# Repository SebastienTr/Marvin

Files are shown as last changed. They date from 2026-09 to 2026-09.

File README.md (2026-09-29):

# Marvin

**A small desk companion that sees the room five ways at once, and knows how you are doing.**

Marvin is an open-source robot for your desk. A 360° lidar turns on top of its head, a camera and a face live behind a black glass window, and two mmWave radars (24 GHz and 60 GHz) hide behind the band around its body. It hears you through a microphone and answers through a speaker in its side.

It can **see** (camera, lidar), **feel** (who is in the room, how they move, and your breathing and heart rate when you sit in front of it), **hear** (microphone) and **speak** (speaker, expressive eyes). The heavy thinking runs on your computer, which fuses everything into one live model of the room.

<p align="center">
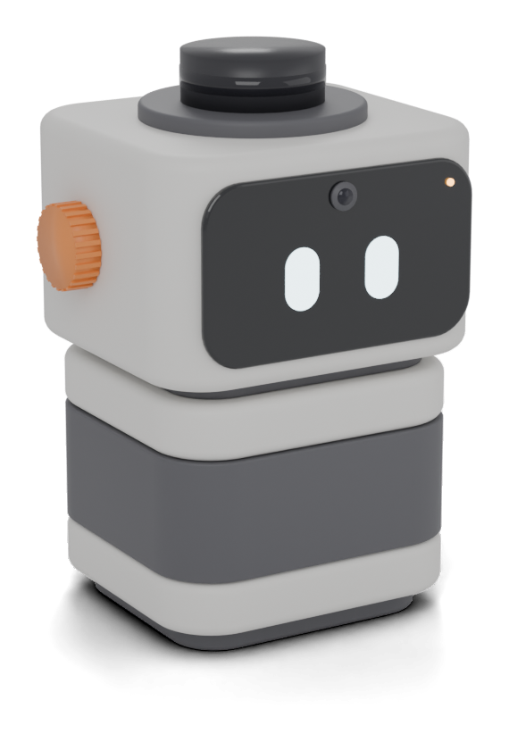
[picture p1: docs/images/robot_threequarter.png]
The Marvin robot: an upright warm-grey body with an anthracite band, a slightly wider head with a black glass face showing two eyes, an orange knob on the side and a lidar turret on top
  
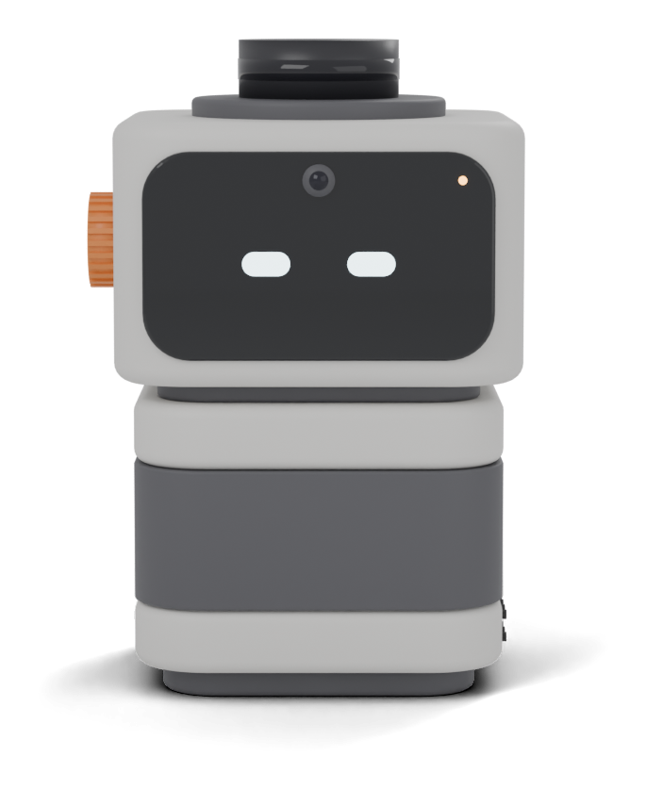
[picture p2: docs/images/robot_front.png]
Front view of the robot with a content expression on its face
  
</p>

> Français : [lire en français](README.fr.md) · Presentation page: open [`docs/index.html`](docs/index.html) in a browser.

> **Project status: rev F, parts for the first build ordered (arriving early October), nothing built yet.** The body half of the CAD is designed and printable ([`hardware/cad/marvin.scad`](hardware/cad/marvin.scad)): body, plinth, sensor sled and TPU neck. The head follows once the screen is measured. The firmware is written and tested on the computer and in simulation, and a Wemos D1 mini runs it today with simulated sensors; its real sensor, screen, audio and camera code has not run on the real hardware yet. The host software (fusion, presence events, the app, the local voice) runs today. The rev E lighthouse is archived in [`hardware/archive/rev-e/`](hardware/archive/rev-e/). The wiring is unchanged since rev D.

## What we want to do

Every sensor on its own is half-blind. A lidar draws perfect walls but cannot tell a person from a coat rack. A radar knows who moves and who breathes, but it cannot draw the room. A camera sees everything and understands nothing about distance. Marvin puts them in one small body, on one clock, and gives the result a personality.

1. **Capture: the robot is dumb on purpose.** The ESP32-S3 reads every sensor, stamps each packet with the same clock and streams it over Wi-Fi. It draws its own eyes and plays its own sounds.
2. **Fuse: the computer does the thinking.** It places every measurement in the same 3D frame (lidar geometry, radar people and speeds, vital signs, camera colour) and shows one live overlay in [Rerun](https://rerun.io).
3. **Live: a companion that notices.** It looks at you when you sit down, reminds you to take a break after about 50 minutes seated, shows your breathing and heart rate (measured, not diagnosed), and answers your questions with what its sensors tell it and what it remembers of you (every memory shows where it comes from, and you can correct or forget it). No cloud is required, and no image needs to leave the room; the one optional exception is the weather tool, which sends a place name to Open-Meteo and can be switched off.

## Designed around the sensors

The robot stands upright on the desk; **the sensors are tilted inside it**, not the body.

- **Heart rate at the desk.** The 60 GHz radar sits in the body on a sled tilted 20° up, so its beam lands on the chest of someone seated 0.65–1.1 m away. It looks through a flat 1.6 mm PETG wall, half a wavelength at 60 GHz; crossing it at 20° costs almost nothing.
- **Room tracking.** The 24 GHz radar sits just below it, tilted 10°, covering ±60° of the room. Below, not above: that way it never shadows the 60 GHz beam.
- **Face and camera.** The screen stands vertical behind a smoked acrylic window; the camera is tilted 20° so it frames your face, not your chest.
- **Lidar on top**, with nothing above its laser plane. On a desk, your monitor and the wall will hide part of its 360° scan; it maps the whole room best from a corner or a shelf.
- **Quiet for the radar.** Head and body are joined through a TPU damper, so the lidar motor does not shake the heart-rate radar.
- **Compact.** About 88 × 80 mm on the desk, about 15 cm tall with the lidar.

<p align="center">
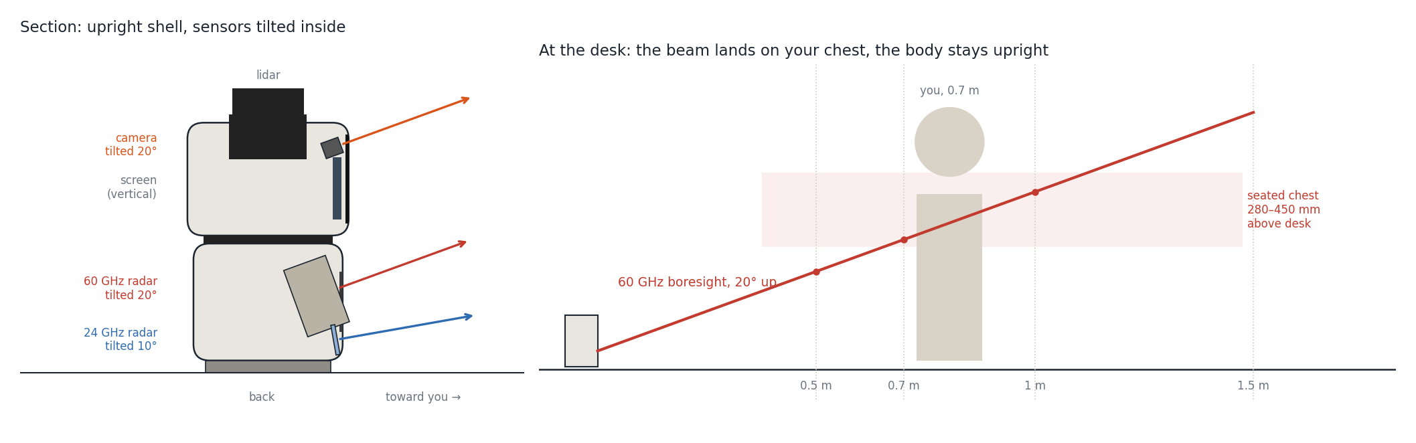
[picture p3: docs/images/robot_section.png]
Section and desk diagram: the upright shell with the sensors tilted inside, and the 60 GHz radar beam reaching the chest of a person seated 0.7 m away
  
</p>

## What each part adds

| Part | Band | Its role |
|---|---|---|
| LDROBOT **D800** lidar (STL-27L) | 905 nm laser | 360° outline of the room, 21 600 points/s, up to 25 m. The cheaper D500 also fits. |
| Hi-Link **HLK-LD2450** | 24 GHz radar | Position and speed of up to 3 people, up to 6 m |
| Seeed **MR60BHA2** kit | 60 GHz radar | Presence, breathing rate and heart rate, best within 1 m |
| **XIAO ESP32S3 Sense** | Visible light | Camera, microphone, Wi-Fi, and the brain that runs everything |
| Waveshare **1.69" LCD** (ST7789) | — | The face: expressive eyes (a mini-map later) |
| **MAX98357A** amp + 1 W speaker | Sound | The voice: built-in sounds, and spoken answers from the computer |

Heart rate from a radar is consumer-grade: a few beats per minute of error, and only while you stay fairly still. It is not a medical device.

## Design language

The name is also the robot's wake word: "marvin" is one of the keywords in Google's open [Speech Commands](https://arxiv.org/abs/1804.03209) dataset, so a keyword-spotting model can be trained for it without recording a dataset first.

Warm grey shell, anthracite band and face, a single orange knob (volume, and a tap to wake it). No stickers, no cartoon features: the personality comes from the eyes and from how it behaves.

## How it works

```mermaid
flowchart LR
  subgraph Robot["Marvin robot"]
    LID["D800 lidar<br/>UART 921600"] --> ESP["XIAO ESP32S3 Sense<br/>camera + mic + Wi-Fi<br/>face + voice"]
    LD2450["HLK-LD2450<br/>UART 256000"] <--> ESP
    MR60["MR60BHA2 kit<br/>(own ESP32-C6)"]
  end
  PWR["USB-C 5 V"] --> ESP
  ESP -->|5 V| LID & LD2450 & MR60
  ESP -->|"Wi-Fi: UDP frames + MJPEG + audio"| PC["Computer<br/>fusion + companion brain"]
  MR60 -->|"Wi-Fi: vital signs"| PC
```

See [docs/architecture.md](docs/architecture.md) for data rates, the power budget and the reasoning behind each choice.

## Build it

1. **Buy the parts** in [docs/bom.md](docs/bom.md): about €230 with the D800 lidar (about €190 with the D500).
2. **Print** following [docs/printing.md](docs/printing.md). Print the 5-minute lidar template first.
3. **Solder** two header strips, then **wire** the 29 connections in [docs/wiring.md](docs/wiring.md). The guide is written for first-timers.
4. **Assemble** following [docs/assembly.md](docs/assembly.md).
5. **Flash and run.** The [firmware](firmware/) and the [host software](host/) already talk to each other with simulated sensors (a Wemos D1 mini is enough to try the firmware); the real-sensor firmware waits for the first build. The host turns what it sees into events, a face, a local voice, a local memory you can read, correct and erase, and an app for your computer and your phone: `./marvin up` starts it (`./marvin demo` without a robot, `./marvin doctor` says what is missing). The Python host's `marvin-host` commands stay as tools: the simulator, the viewer, replays.

The body parts are ready to print; the head parts arrive with the head CAD.

## Repository layout

```
marvin/
├── hardware/
│   ├── cad/                      # parametric OpenSCAD source (marvin.scad, rev F)
│   ├── stl/                      # print-ready STLs (generated)
│   ├── bambu/                    # Bambu Studio project, A1 + AMS lite (generated)
│   ├── blender/                  # assembled model + print layout (generated)
│   ├── scripts/                  # export_stl.sh, render_previews.sh, section_diagram.py, build_3mf.py, build_blend.sh
│   └── archive/                  # earlier revisions (rev E: Fanou the lighthouse)
├── firmware/                     # ESP32 firmware (prototype)
├── host/                         # Python: simulator, viewer, replay tools, the voice sidecar (and the first host)
├── host-java/                    # the host core (Java): ./marvin runs it
├── docs/                         # BOM, wiring, printing, assembly, architecture
│   ├── protocol.md               # robot ↔ host UDP protocol
│   ├── design.md                 # Marvin's brain: next-generation host design (memory, agents, Java core)
│   ├── concepts/                 # design studies, from the lighthouse to the robot
│   └── index.html                # presentation page (open in a browser)
└── LICENSES/                     # full licence texts
```

## Licences

| What | Licence |
|---|---|
| Hardware (`hardware/`) | [CERN-OHL-P-2.0](LICENSES/CERN-OHL-P-2.0.txt) |
| Software (`firmware/`, `host/`, `host-java/`, scripts) | [MIT](LICENSES/MIT.txt) |
| Documentation and images (`docs/`, READMEs) | [CC BY 4.0](LICENSES/CC-BY-4.0.txt) |

All three are permissive: build it, modify it, sell it. Just keep the attribution.

## Contributing

Issues and pull requests are welcome. Build reports with photos are especially useful while no unit has been built yet. See [CONTRIBUTING.md](CONTRIBUTING.md).

## Credits

Mechanical dimensions come from the LDROBOT LD19 datasheet (v2.5, same footprint as the STL-19P and STL-27L in the D500 and D800 kits), the Waveshare 1.69" LCD documentation, the Hi-Link HLK-LD2450 manual, the Seeed MR60BHA2 datasheet and schematic, and the Seeed XIAO ESP32S3 Sense documentation. Sensor names are trademarks of their respective owners. This project is not affiliated with any of them.

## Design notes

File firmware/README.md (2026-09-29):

# Firmware

Firmware for the Marvin robot's XIAO ESP32S3 Sense, built with PlatformIO.

**Status: prototype, real sensors ready for the first power-on.** The Wi-Fi link and the [UDP protocol](../docs/protocol.md) work. The robot build reads the **real lidar and HLK-LD2450** over its UARTs; the other builds run **simulated sensors** (a D500 or D800 lidar, an LD2450 and the MR60BHA2 vital signs, seeing a small home office with a person walking around and sitting down, byte-exact to the real frames), on a Wemos D1 mini (ESP8266) as well as on the ESP32-S3 boards, so the whole chain can be tested without the robot. On the XIAO builds, the face runs on the screen, the speaker and microphone stream over UDP and the camera streams MJPEG over HTTP (untested on hardware so far).

## Build environments

| Env | Board | Sensors |
|---|---|---|
| `xiao_esp32s3` | XIAO ESP32S3 Sense, **the robot** | **Real**: lidar on UART0, LD2450 on UART1 (`MARVIN_SENSORS=REAL`, `MARVIN_LIDAR_MODEL=2` = D800); screen, audio, camera |
| `xiao_esp32s3_sim` | XIAO ESP32S3 Sense | Simulated; screen, audio, camera |
| `esp32s3` | ESP32-S3 DevKitC-1 (bench) | Simulated |
| `esp32dev` | Classic ESP32 DevKit (ESP32-WROOM-32, 30 pins; bench, a second device) | Simulated |
| `d1_mini` | Wemos D1 mini (ESP8266), default | Simulated (real sensors need an ESP32: the build stops with an error) |
| `native` | Your computer | Unit tests of the portable code: `pio test -e native` |

Build flags: `MARVIN_SENSORS=SIM|REAL`, `MARVIN_LIDAR_MODEL=1|2` for the real lidar (1 = D500 at 230 400 baud, 2 = D800 at 921 600 baud), `MARVIN_SIM_LIDAR_MODEL=1|2` for the simulated one. `MARVIN_HAS_SCREEN` (the face), `MARVIN_HAS_AUDIO` (speaker and microphone, see [Audio](#audio)) and `MARVIN_HAS_CAMERA` (see [Camera](#camera)) switch the optional parts on; the audio and camera ones are for the XIAO ESP32S3 Sense only (the build stops with an error elsewhere). The `d1_mini`, `esp32s3` and `esp32dev` builds have neither.

Partitions: the XIAO builds keep the board's `default_8MB.csv`, two 3.2 MB OTA app slots. With screen, audio and camera, the robot firmware is about 0.83 MB (25 % of a slot).

With real sensors, `HELLO` does not carry the *simulated* flag, lidar packets go 10 per `LIDAR` datagram (a partial batch leaves after 20 ms), each LD2450 frame goes in its own datagram, no `VITALS` are sent (the MR60BHA2 kit has its own bridge), and a `LOG` with the sensor counters goes to the host every 5 s.

## Build and flash

1. Install PlatformIO: `pip install platformio` (or the VS Code extension).
2. Copy `include/secrets.example.h` to `include/secrets.h` and put your Wi-Fi name and password in it (2.4 GHz network). `secrets.h` is ignored by git.
3. Plug the board in over USB, then:

```bash
cd firmware
pio run -e d1_mini -t upload       # Wemos D1 mini
pio device monitor                 # serial log (Ctrl+C to quit); the speed comes from platformio.ini
```

The robot: `pio run -e xiao_esp32s3 -t upload && pio device monitor -e xiao_esp32s3`. If the upload does not start, hold **BOOT**, press **RESET**, release **BOOT**, and upload again (the first flash of a new XIAO often needs it). The serial log goes over the USB-C port; UART0 belongs to the lidar.

Then run `marvin-host run` on a computer on the same network (see [host/README.md](../host/README.md)). The on-board LED blinks fast while the robot looks for the host, and flashes briefly every 2 s once linked.

## First power-on with the real sensors

Wire as in [docs/wiring.md](../docs/wiring.md), flash `xiao_esp32s3`, open the serial monitor. Expected:

```text
Marvin firmware 0.1.0, board 3, real sensors
lidar D800 on UART0 RX GPIO44 at 921600 baud
LD2450 on UART1 (RX GPIO5, TX GPIO6) at 256000 baud: multi-target tracking set
joining MyWifi....
IP 192.168.1.42, RSSI -51 dBm
lidar 1800 pkt/s, 0 CRC err, 0 B dropped; LD2450 10.0 frame/s, 0 bad; 0 UART overflows
linked to host 192.168.1.10
```

The counters line comes every 5 s, host or not. A D800 gives about 1 800 packets/s (21 600 points/s), a D500 about 375; the LD2450 10 frames/s. A few CRC errors right after boot are normal.

| Symptom | Likely cause | Fix |
|---|---|---|
| `0 pkt/s` and `0 B dropped` | No lidar data reaches GPIO44 | Check the lidar's power (motor spinning?) and that its **Tx** goes to **D7** |
| `0 pkt/s`, many CRC errors or dropped bytes | Wrong baud rate: the model does not match the build | Set `MARVIN_LIDAR_MODEL` (1 = D500, 2 = D800) in `platformio.ini`, flash again |
| `UART overflows` keep growing | The loop is too slow to drain the UARTs | Report it: something blocks `loop()` |
| `LD2450 ... no answer` and `0.0 frame/s` | TX and RX swapped, or no power | Swap the wires on **D4 / D5** (LD2450 TX → D4, D5 → LD2450 RX), check 5 V |
| `LD2450 ... no answer` but `10.0 frame/s` | Only the robot → radar wire (D5 → LD2450 RX) is wrong | The radar still streams in its saved mode (multi-target by default); fix the wire for the boot configuration |
| `LD2450 0.0 frame/s`, many bad frames | Wrong baud rate (the radar's was changed from 256 000) | Reset it to factory settings with the HLKRadarTool app |

## Audio

`MARVIN_HAS_AUDIO` ([`src/audio/`](src/audio/)): the host streams speech to the speaker and asks for the microphone over the same UDP link as everything else ([protocol](../docs/protocol.md#audio-messages), [docs/audio.md](../docs/audio.md) for the earcons, the volume cap and the latency budget).

- **Speaker**: MAX98357A on I2S1, BCLK GPIO8 (D9), LRC/WS GPIO43 (D6), DIN GPIO3 (D2), 16 kHz 16-bit, the mono stream on both slots. `AUDIO_OUT` datagrams go through a jitter buffer (100 ms prebuffer, 750 ms capacity; lost datagrams become silence, late ones are dropped); `SOUND` plays a built-in earcon, mixed over the stream; `AUDIO_CTRL` stops playback or sets the volume (0–100, the loudest setting is capped at −6 dBFS for the 1 W speaker). The *hello* earcon plays on the first link after boot (`-DMARVIN_BOOT_SOUND=0` to silence it).
- **Microphone**: the Sense board's PDM mic on I2S0, CLK GPIO42, DATA GPIO41, 16 kHz. Off by default: the PDM clock only runs while the host has asked for it (`AUDIO_CTRL` *mic start*, repeated every second) and the link is up. DC offset removed, +12 dB of gain by default, 20 ms per `AUDIO_IN` datagram.
- **Tasks**: `speaker` (priority 6) and `mic` (priority 5) on core 1, above the Arduino loop (priority 1), so the I2S DMA never starves; each 10–20 ms block costs well under a millisecond. The loop sends the microphone blocks itself, so `AUDIO_IN` leaves from the robot's UDP port like every other message.
- **GPIO43**: it is UART0 TX at boot, where the ROM bootloader and ESP-IDF logs print (the Arduino `Serial` is the USB port, and UART0 only receives the lidar on GPIO44). `audio_app::begin()` runs after the sensors, resets GPIO43 (`gpio_reset_pin`) and routes I2S1 WS to it, so no console byte ever reaches the amp's LRC input. The boot ROM messages still toggle it for a moment before the firmware starts: harmless, the amp stays silent without BCLK. Do not call `Serial0.begin()` or `Serial0.setPins()` after `audio_app::begin()`.
- Options: `MARVIN_AUDIO_VOLUME` (default volume, 60), `MARVIN_AUDIO_GAIN_CAP` (percent of full scale at volume 100, 50), `MARVIN_MIC_GAIN_DB` (12), `MARVIN_MIC_RIGHT_SLOT=1` (read the mic on the other PDM slot).

Every 10 s while audio is in use, a `LOG` line: `audio: speaker 500 dgram, 0 lost / 0 late / 0 overflow samples, 0 underruns, 1 sounds; mic 500 blocks, 0 dropped, peak 2100`.

## Camera

`MARVIN_HAS_CAMERA` ([`src/camera/`](src/camera/)): the OV3660 (or OV2640) of the Sense board, VGA JPEG at quality 12, two frame buffers in PSRAM, always the latest frame.

- `http://<robot ip>:81/stream`: MJPEG (`multipart/x-mixed-replace`, boundary `marvinframe`), every part with `Content-Length` and `X-Marvin-Time-Us` (the robot clock of the UDP headers). `http://<robot ip>:81/capture`: one JPEG. `http://<robot ip>:81/`: a page showing the stream. The robot's IP is in the serial log, and the host knows it from `HELLO`.
- A small socket server in one task (`camera`, core 0, priority 1, below Wi-Fi and lwIP): one frame grab is shared by every client (up to 4, e.g. the viewer and the web UI at once), and `/capture` works while a stream is open. Frames go out at most `MARVIN_CAMERA_FPS` times a second (10) and only while someone is connected: VGA is ~25–40 kB a frame, ~3 Mbit/s at 10 fps.
- Options: `MARVIN_CAMERA_FPS` (10), `MARVIN_CAMERA_QUALITY` (12; 0–63, lower is better and larger), `MARVIN_CAMERA_VFLIP` / `MARVIN_CAMERA_HMIRROR` (0/1, for how the module is mounted; the OV3660 is flipped vertically by default, as in Espressif's example).
- `HELLO` flags bit 1 (camera) and bit 2 (audio) are set only when that part started.

Every 10 s while someone watches: `camera OV3660: 1 streaming, 10.0 frames/s, 100 parts, 0 captures, 310 kB/s, 0 connections`.

### Audio and camera troubleshooting

| Symptom | Likely cause | Fix |
|---|---|---|
| `audio: speaker I2S init failed` | Another driver owns I2S1 | Check that nothing else installs an I2S driver |
| No sound at all, not even the *hello* earcon | Amp wiring or power | BCLK → D9, LRC → D6, DIN → D2, VIN on 5 V; SD and GAIN unconnected |
| Buzzing or clicks in time with serial output | GPIO43 still driven by UART0 | Something called `Serial0.begin()` after the audio started: move it before `audio_app::begin()` |
| Distorted or too loud | Gain cap too high for the speaker | Lower `MARVIN_AUDIO_GAIN_CAP`, or the volume from the host |
| `underruns` keep growing | The host sends late, or Wi-Fi drops bursts | Check the host pacing (`RobotSpeakerSink`, 150 ms lead) and the RSSI |
| `mic ... peak 0` | The mic is on the other PDM slot | Build with `-DMARVIN_MIC_RIGHT_SLOT=1` |
| Mic very quiet / clipping | Gain | `AUDIO_CTRL` mic gain from the host, or `MARVIN_MIC_GAIN_DB` |
| `camera: no PSRAM` | Wrong board definition | The env must use `board = seeed_xiao_esp32s3` (OPI PSRAM) |
| `camera: init failed (0x20001)` | Camera not detected | Reseat the Sense expansion board and the camera ribbon |
| Stream stutters, lidar datagrams lost | Wi-Fi air time | Lower `MARVIN_CAMERA_FPS` or raise `MARVIN_CAMERA_QUALITY` |
| `503` from the camera | Four clients already connected | Close a viewer tab |

## Tests

```bash
pio test -e native
```

Runs the Unity tests in `test/` on your computer: the lidar and LD2450 stream framers against a real LD19 packet, the LD2450 datasheet frames, garbage, split and corrupted streams, round trips through the simulator, and the LD2450 command bytes; the face renderer; and (`test_audio`) the speaker jitter buffer (prebuffering, lost, late, duplicated and overlapping datagrams, index wrap, overflow, underrun, stop), the earcons, the audio payloads, the DSP helpers and the camera server's HTTP routing.

## Source layout

| File | Role |
|---|---|
| `src/main.cpp` | Wi-Fi, host discovery (`HELLO` / `HOST_ACK`), host message dispatch, streaming loop, status LED, sensor source selection |
| `src/protocol.h` | UDP envelope, mirrors `host/marvin_host/protocol.py` |
| `src/sensor_framing.cpp` | Portable stream framers: LDROBOT lidar packets (CRC-8), LD2450 target and ACK frames, LD2450 command builders |
| `src/sensors_real.cpp` | ESP32 only: the lidar and LD2450 UARTs, LD2450 boot configuration, counters |
| `src/sensors_sim.cpp` | Simulated lidar packets, LD2450 frames and MR60BHA2 vital signs |
| `src/scene_data.h` | The simulated room and person, generated from `host/marvin_host/scene.py` |
| `src/audio/audio_app.cpp` | ESP32-S3 only: I2S speaker and PDM microphone drivers, their tasks, `AUDIO_*` / `SOUND` handling |
| `src/audio/jitter_buffer.cpp`, `earcons.cpp`, `audio_dsp.cpp`, `audio_packets.h` | Portable: speaker jitter buffer, procedural earcons, DC blocker / gain / volume, audio payloads |
| `src/camera/camera_app.cpp` | ESP32-S3 only: esp32-camera setup and the MJPEG server on port 81 |
| `src/camera/http_request.h` | Portable: the camera server's request routing and multipart framing |
| `test/` | Unit tests (`pio test -e native`) |

## Responsibilities (full firmware)

1. Read the **lidar** on UART0 (RX = GPIO44 / D7): 921 600 baud for the D800 (STL-27L), 230 400 baud for the D500 (STL-19P). Validate each 47-byte LDROBOT packet (header `0x54`, CRC8).
2. Read the **HLK-LD2450** on UART1 (RX = GPIO5 / D4, TX = GPIO6 / D5, 256 000 baud), switch it to multi-target mode at boot and parse its target frames.
3. Stamp every packet with a monotonic microsecond clock, synchronised to the host.
4. Send lidar and radar packets to the host as **UDP** datagrams, in a small versioned binary envelope.
5. Serve the camera as an **MJPEG** stream over HTTP (done: [Camera](#camera)).
6. Drive the **1.69" ST7789 screen** (SPI), the robot's face:
   - **eyes** by default: blinking, looking towards the nearest person tracked by the LD2450, sleepy when nobody is around, and any expression the host sends;
   - a top-down lidar **mini-map** with radar targets, and a status page (Wi-Fi, host link), on request.
7. **Audio in**: read the built-in PDM microphone (I2S0, 16 kHz) and stream it on request (done: [Audio](#audio)), or detect simple sound events locally.
8. **Audio out**: play chirps, beeps and speech streamed from the host through the MAX98357A (I2S1), with a volume cap (done: [Audio](#audio)).
9. Keep the robot **alive without a computer**: eyes, presence reactions and sounds work on the device alone; the host adds understanding and language.
10. Support **OTA** updates after the first USB flash.

The MR60BHA2 kit keeps its own ESP32-C6: [`mr60_bridge/`](mr60_bridge/) replaces Seeed's stock firmware on it and sends the vital signs straight to the host, in the same protocol.

## Pin map

Unchanged since rev D.

| Signal | XIAO pin | GPIO | Peripheral |
|---|---|---|---|
| Lidar Tx → | D7 | 44 | UART0 RX |
| LD2450 TX → | D4 | 5 | UART1 RX |
| → LD2450 RX | D5 | 6 | UART1 TX |
| Screen CS | D0 | 1 | GPIO |
| Screen DC | D1 | 2 | GPIO |
| Screen RST | D3 | 4 | GPIO |
| Screen CLK | D8 | 7 | SPI2 SCK |
| Screen DIN | D10 | 9 | SPI2 MOSI |
| Amp BCLK | D9 | 8 | I2S1 |
| Amp LRC / WS | D6 | 43 | I2S1 |
| Amp DIN | D2 | 3 | I2S1 |
| Mic CLK / DATA | internal | 42 / 41 | I2S0 PDM (Sense board) |
| Camera | internal | — | DVP (Sense board) |

The screen shares the SPI pins (GPIO7/8/9) with the Sense board's microSD slot. Leave the slot empty, or give each device its own chip-select.

## Planned toolchain

PlatformIO with the Arduino-ESP32 core (`board = seeed_xiao_esp32s3`), USB CDC on boot enabled so UART0 stays free.

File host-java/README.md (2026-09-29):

<!-- SPDX-License-Identifier: CC-BY-4.0 -->
# Marvin's host in Java

The next host core for Marvin: Java 25, Spring Boot 4.1, hexagonal, one deployable made of
bounded contexts that could later become services. The design is in
[docs/design.md](../docs/design.md); the engineering log (decisions, deviations, known gaps, per
migration phase) is in [NOTES.md](NOTES.md).

Status: **phase 3, memory v1**, on top of parity with the Python host (phase 2b); the default way to run Marvin (`./marvin up`).
The host owns the robot's UDP port (protocol v1, byte for byte as the Python host), runs the presence
brain on it, feeds the robot's face, records, replays and taps the datagrams, keeps the history in
PostgreSQL, serves its app (the current design) with the Python host's API, event streams and access key, and
talks: the conversation (persona, context, Ollama through Spring AI, the tool loop and the weather,
memory, break reminders) runs in Java, the audio loop in the Python voice sidecar it supervises
([docs/voice.md](../docs/voice.md#the-voice-sidecar)). The Python host (`marvin-host`) stays for the
simulator, the Rerun viewer and replays; only one host can own UDP 47100 at a time.

**Memory v1** (design phase 3) is built: an append-only event log fed by the conversation and the brain, facts on two
clocks with their sources, day, week and month summaries, a profile with versions, a memory worker that learns when
the voice is idle and at night, the profile and the facts that matter in each question, the `remember`, `recall` and
`forget` tools, and the owner's control over all of it in the new app (Day, Night or Auto; Home, Talk, Memory,
Activity, Marvin). How it works: [docs/memory.md](../docs/memory.md); the app: [docs/ui.md](../docs/ui.md).

Before relying on it with real boards and a real model, run the manual
[test plan](../docs/test-plan.md); to review the change, start with the
[review guide](../docs/review-guide.md).

## The architecture in four pictures

### 1. The hexagon

The domain and the use cases sit in the middle, in plain Java, and know nothing about HTTP, UDP,
SQL or Ollama. They define **ports** (Java interfaces). **Adapters** on the outside implement or
call those ports. On the left, the adapters that *drive* Marvin call an inbound port. On the right,
the use cases call an outbound port that an adapter implements.

```mermaid
flowchart LR
    subgraph drivers["Who drives Marvin"]
        phone["📱 The app<br/>(phone, browser)"]
        robot_in["🤖 The robot<br/>UDP 47100"]
        voice_in["🎙️ Voice sidecar<br/>(Python, gRPC)"]
    end

    subgraph in_adapters["Inbound adapters"]
        web["adapter-web<br/>REST · SSE · access key"]
        udp_in["adapter-robot<br/>UdpRobotLink · replay"]
        grpc_in["adapter-sidecar<br/>GrpcVoiceSidecar"]
    end

    subgraph core["The core (plain Java, no framework)"]
        direction TB
        subgraph app["application: use cases"]
            pin(["port.in<br/>ManageSettings · VoiceControl<br/>RobotInbound · PresenceQuery<br/>RecallMemory · ManageFacts …"])
            svc["RobotLinkService · PresenceService<br/>VoiceService · ConversationService<br/>MemoryWorker · MemoryRecallService<br/>SettingsService · HealthService"]
            pout(["port.out<br/>LanguageModel · ConversationStore<br/>RobotOutbound · VoiceSidecar<br/>EventLog · FactStore · MemoryModel · Embedder …"])
            pin --> svc --> pout
        end
        dom["domain<br/>protocol v1 · presence brain<br/>persona · tools · face<br/>memory rules · retrieval scoring"]
        svc --> dom
    end

    subgraph out_adapters["Outbound adapters"]
        pg["adapter-persistence<br/>JDBC · Flyway"]
        llm["adapter-llm<br/>Spring AI · JDK HTTP"]
        udp_out["adapter-robot<br/>UdpRobotLink"]
        side["adapter-sidecar<br/>gRPC client · supervisor"]
    end

    subgraph driven["What Marvin drives"]
        db[("PostgreSQL 18<br/>+ pgvector")]
        ollama["Ollama<br/>(local LLM, embeddings)"]
        meteo["Open-Meteo"]
        robot_out["🤖 The robot<br/>face · speaker"]
        voice_out["🎙️ Voice sidecar"]
    end

    phone --> web --> pin
    robot_in --> udp_in --> pin
    voice_in --> grpc_in --> pin
    pout --> pg --> db
    pout --> llm --> ollama
    llm --> meteo
    pout --> udp_out --> robot_out
    pout --> side --> voice_out
```

The dependency always points **inward**: an adapter knows the port, the port never knows the
adapter. Replacing PostgreSQL, Ollama or the UDP link means writing another adapter; the core does
not change. `marvin-app` (Spring Boot) is the only place where the two sides are plugged together.

### 2. The Maven modules

Each layer is its own Maven module, so a wrong dependency does not even compile. The Maven
enforcer and ArchUnit check the rest on every build.

```mermaid
flowchart BT
    domain["marvin-domain<br/><i>plain Java, depends on nothing</i>"]
    application["marvin-application<br/><i>use cases + ports</i>"]
    web["marvin-adapter-web"]
    robot["marvin-adapter-robot"]
    persistence["marvin-adapter-persistence"]
    llm["marvin-adapter-llm"]
    sidecar["marvin-adapter-sidecar"]
    contracts["marvin-contracts<br/><i>voice.proto · golden files</i>"]
    appm["marvin-app<br/><i>Spring Boot main, wiring, ArchitectureTest</i>"]

    application --> domain
    web --> application
    robot --> application
    persistence --> application
    llm --> application
    sidecar --> application
    sidecar --> contracts
    appm --> web
    appm --> robot
    appm --> persistence
    appm --> llm
    appm --> sidecar
```

No arrow between two adapters: `adapter-web` cannot call `adapter-persistence`, it goes through a
use case.

### 3. The bounded contexts

Seven contexts share the core. Each one owns its model and its ports, and the ones that store data own
a PostgreSQL schema. A context uses another only through that context's ports (`port.in`,
`port.out`) or domain events (`domain.<context>.event`), never through its classes or its tables.
That is what lets a context become a service of its own later ([design 10.4](../docs/design.md)).
An arrow reads "uses".

```mermaid
flowchart LR
    robot["<b>robot</b><br/>protocol v1, devices,<br/>link health, face link"]
    presence["<b>presence</b><br/>the brain: seated,<br/>away, breaks, vitals"]
    conversation["<b>conversation</b><br/>persona, context,<br/>tools, voice turns"]
    face["<b>face</b><br/>the eyes, drawn<br/>for the app"]
    settings["<b>settings</b><br/>app settings"]
    memory["<b>memory</b><br/>event log, facts, episodes,<br/>profile, the memory worker"]
    system["<b>system</b><br/>health, log, traces"]

    robot -. "frames: SensorFrameListener<br/>(plugged in marvin-app)" .-> presence
    robot -- "PresenceQuery, PresenceEvent<br/>(the eyes follow the brain)" --> presence
    robot -- "VoiceRobotAudio<br/>(robot mic and speaker)" --> conversation
    conversation -- "PresenceQuery, PresenceEvent<br/>(what Marvin knows)" --> presence
    face -- "PresenceQuery, PresenceEvent" --> presence
    conversation -- "Tracing" --> system

    classDef ctx fill:#24201d,stroke:#ee7626,color:#ece6da
    memory -. "VoiceActivity, rewarm<br/>(plugged in marvin-app)" .-> conversation
    conversation -. "kept lines<br/>(plugged in marvin-app)" .-> memory
    presence -. "stored events<br/>(plugged in marvin-app)" .-> memory
    conversation -. "MemoryContext: profile, sections, tools<br/>(plugged in marvin-app)" .-> memory

    class robot,presence,conversation,face,settings,system,memory ctx
```

`presence` uses nobody: it is the heart, and everyone reads it. `settings` and `system` are used by
the adapters (the app, the health checks), not by the other contexts. `memory` uses nobody either: `marvin-app`
feeds it what the conversation keeps and what the presence history stores, and gives it the voice's activity; the
conversation reads memory through its own port, `MemoryContext`, which `marvin-app` plugs into memory's in-ports
([docs/memory.md](../docs/memory.md)).

| Context | PostgreSQL schema | Main use cases |
|---|---|---|
| `robot` | none (the link lives in memory) | `RobotLinkService`, `FaceLinkService`, `RobotAudioService` |
| `presence` | `presence` (events, minute samples) | `PresenceService`, `PresenceHistoryService` |
| `conversation` | `conversation` (turns) | `VoiceService`, `ConversationService`, `WeatherTool` |
| `settings` | `settings` | `SettingsService` |
| `face` | none | `FaceService`, `FaceLinkService` drives the robot's screen |
| `system` | none | `HealthService`, `HostLogService` |
| `memory` | `memory` (event log, facts and their sources, episodes, block versions, state) | `MemoryLogService`, `MemoryWorker` (`Consolidator`, `NightlyPass`), `MemoryAdminService`, `MemoryRecallService`, `ForgetConfirmations` |

A `platform` schema holds what belongs to no context: the database extensions (pgvector) and the
record of the one-time import from the Python host.

### 4. Two requests, end to end

**A robot frame becomes a presence event.**

```mermaid
sequenceDiagram
    autonumber
    participant R as 🤖 Robot
    participant U as UdpRobotLink<br/>(adapter-robot)
    participant L as RobotLinkService<br/>(robot)
    participant F as PresenceFeed<br/>(marvin-app)
    participant P as PresenceService<br/>(presence)
    participant B as Brain<br/>(domain)
    participant S as Subscribers<br/>face link · history · app

    R->>U: UDP datagram (protocol v1)
    U-->>R: HOST_ACK
    U->>L: RobotInbound.accept(frame)
    L->>F: SensorFrameListener.onFrame(frame)
    F->>P: ObservePresence.onTargets / onVitals
    P->>B: update (robot clock only)
    B-->>P: event, for example "seated for 50 min"
    P->>S: PresenceEventPublisher.publish(event)
    Note over S: the robot's eyes change,<br/>the history is written,<br/>the phone gets it over SSE
```

**A spoken question becomes a spoken answer, with what Marvin remembers.**

```mermaid
sequenceDiagram
    autonumber
    participant S as 🎙️ Voice sidecar<br/>(Python)
    participant G as GrpcVoiceSidecar<br/>(adapter-sidecar)
    participant V as VoiceService<br/>(conversation)
    participant K as MemoryContext<br/>(memory, via marvin-app)
    participant M as OllamaLanguageModel<br/>(adapter-llm)
    participant W as WeatherTool<br/>(conversation)
    participant D as JdbcConversationStore<br/>(adapter-persistence)
    participant A as 📱 App

    S->>G: partial transcript, then "Marvin, il fait quel temps ?"
    G->>V: VoiceSidecar.Signals
    V->>K: recollect (started on the partial, while recognition ends)
    K-->>V: facts and summaries within their token budget
    V->>M: LanguageModel.streamChat(system prompt with the profile,<br/>question with context and memory, tools)
    M-->>V: tool call get_weather
    V->>W: run (JsonFetcher → Open-Meteo)
    W-->>V: forecast
    V->>M: streamChat(… + tool result)
    M-->>V: answer, piece by piece
    V->>G: VoiceSidecar.send(say …)
    G->>S: speak (Piper)
    V->>D: ConversationStore.save(turn)
    V-->>A: VoiceListener → SSE (partial, say, the reply's memory report)
    Note over D: the kept lines reach memory's event log;<br/>the memory worker learns from them when the voice is idle
```

## Run it

From the repository root, one command does everything (JDK, build, database, host):

```bash
./marvin doctor     # what this machine has and how to fix what is missing
./marvin up         # PostgreSQL (Docker) + the host + the voice; the app on http://localhost:8765/
./marvin demo       # the same with a simulated robot and a simulated past week
./marvin status     # what runs, and the host's health
./marvin logs       # follow the log (-n 100: the last lines)
./marvin restart    # stop the host and start it again, rebuilt if the code changed (after a git pull)
./marvin down       # stop everything (the data is kept)
```

- **JDK**: a JDK 25 from `MARVIN_JAVA_HOME`, `JAVA_HOME`, `/usr/libexec/java_home` (macOS) or the
  `PATH`; if there is none, `./marvin` downloads Eclipse Temurin 25 into
  `~/.local/share/marvin/jdk` (Adoptium API). Nothing is installed system-wide.
- **PostgreSQL 18 with pgvector**: in Docker (`pgvector/pgvector:pg18`, container
  `marvin-postgres`, volume `marvin-pgdata`, `127.0.0.1:5433`) when Docker runs; otherwise the host
  starts its own PostgreSQL (data in `~/.local/share/marvin/pg`, no pgvector yet). The first choice
  is kept (`~/.local/share/marvin/db_mode`): if the data is in Docker and Docker is not running,
  `./marvin up` starts Docker Desktop (macOS) or says so, rather than opening an empty second
  database. `MARVIN_DB=docker` or `MARVIN_DB=embedded` forces one; `MARVIN_PG_PORT` moves the Docker
  database off 5433.
- **Python**: the voice sidecar runs from `host/.venv`, which `./marvin up` creates with the
  `sidecar` and `voice` extras the first time (a few minutes; `--no-voice` skips it). The demo's
  simulated robot and past week also come from the Python host (`host/.venv` if it exists, else
  `python3` if it can import it, else `./marvin demo` creates `host/.venv` with the base
  dependencies; `./marvin demo --voice` adds the voice). The voice is optional: if its packages cannot
  be installed (offline), Marvin starts without it. The sidecars exit with the host, even when it is
  killed.
- **The voice**: turned on and off in the app (Talk panel), settings in Settings > Voice, saved to
  `~/.config/marvin/voice.json` (shared with `marvin-host talk`). It needs Ollama and its model
  (`ollama pull qwen3:4b-instruct`); the panel says what is missing and how to fix it. The demo works
  on a copy of `voice.json` (in `~/.local/share/marvin/demo/`), remade at each start.
- **The Python host's history**: on first start, `~/.local/share/marvin/marvin.db` (the Python
  host's SQLite file: events, minute samples, settings, conversation) is imported into PostgreSQL,
  once. Both hosts use the same data directory and the same access key (`ui_token`).
- **Build**: `./marvin` builds the jar when it is missing or older than the sources.
- **The JVM**: `-XX:+UseSerialGC -Xmx384m` (about 250 MB resident at idle); `MARVIN_JAVA_OPTS` replaces these
  options. The host gives virtual threads at least 8 carrier threads whatever the number of processors (a start-up
  hang seen on two processors, NOTES "final verification"). `host.log` is rotated to `host.log.1` past 10 MB.
- **Health and traces**: `/api/health` (the app's), `/actuator/health` with its components
  (`db`, `marvin/database`, `marvin/robot`, `marvin/voice`), `/actuator/health/readiness` (down
  without the database) and `/actuator/health/liveness`. Each question is a trace
  (`marvin.question`, with the latency stages as attributes; trace and span ids in the log lines);
  set `MANAGEMENT_OPENTELEMETRY_TRACING_EXPORT_OTLP_ENDPOINT=http://localhost:4318/v1/traces` to
  export them to an OpenTelemetry collector.

Or by hand, with a PostgreSQL at `MARVIN_DB_URL` (default `jdbc:postgresql://127.0.0.1:5433/marvin`,
user and password `marvin`):

```bash
cd host-java
./mvnw -q -DskipTests package
java -jar marvin-app/target/marvin-host.jar          # MARVIN_MODE=demo for the demo
curl http://localhost:8765/api/health
```

| Variable | Default | |
|---|---|---|
| `MARVIN_PORT`, `MARVIN_BIND` | `8765`, `0.0.0.0` | The app's port and address |
| `MARVIN_MODE` | `live` | `live` or `demo` |
| `MARVIN_DATA_DIR` | `~/.local/share/marvin` | Data (embedded database, run files, logs) |
| `MARVIN_DB_MODE` | `external` | `external` (at `MARVIN_DB_URL`) or `embedded` |
| `MARVIN_DB_URL`, `MARVIN_DB_USER`, `MARVIN_DB_PASSWORD` | Docker's | The external database |
| `MARVIN_UDP_PORT`, `MARVIN_UDP_BIND` | `47100`, `0.0.0.0` | The robot link |
| `MARVIN_TAP` | none | Forward every datagram to this UDP port (or `host:port`) for the Python viewer |
| `MARVIN_RECORD` | none | Also record the datagrams to this `.mvrec` file (`.gz`: compressed) |
| `MARVIN_REPLAY`, `MARVIN_REPLAY_SPEED`, `MARVIN_REPLAY_LOOP` | none, `1.0`, `true` | Play a recording instead of listening (speed 0: as fast as possible) |
| `MARVIN_CALIBRATION` | `~/.config/marvin/calibration.json` | The sensor calibration the Python host writes (`MARVIN_CONFIG_DIR` also works) |
| `MARVIN_UI_TOKEN` | `auto` | The app's access key for other devices: `auto` (kept in `<data dir>/ui_token`), `off`, or the key |
| `MARVIN_TZ` | this computer's | The owner's time zone (days, quiet hours) |
| `MARVIN_IMPORT` | `<data dir>/marvin.db` | The Python host's history to import once (empty: none) |
| `MARVIN_PYTHON`, `MARVIN_REPO` | `host/.venv`, the repository | The Python for the sidecars, and where `host/` is |
| `MARVIN_DEMO_SIMULATOR`, `MARVIN_DEMO_SEED` | `true`, `true` | Demo: the Python simulator as the robot; the simulated past week |
| `MARVIN_CONFIG_DIR` | `~/.config/marvin` | Where `voice.json` is (also `$XDG_CONFIG_HOME/marvin`) |
| `MARVIN_VOICE_SIDECAR`, `MARVIN_VOICE_ARGS` | `true`, none | Start the voice sidecar; more arguments for it (its test mode: `--fake,--say,2:Marvin bonjour`) |
| `MARVIN_MEMORY_WORKER` | `true` | The memory worker (`false`: memory records but learns nothing) |
| `MARVIN_EMBEDDING_DIMENSIONS` | `1024` | The embedding model's size (qwen3-embedding:8b), fixed when memory's tables are made |
| `MARVIN_MEMORY_VECTOR` | `auto` | pgvector's index when installed; `off`: exact search |

### The app

The app is the Java host's own (`marvin-adapter-web/src/main/resources/app`, plain ES modules, no build step; the
Python host keeps its older app): Day, Night or Auto, five destinations (Home, Talk, Memory, Activity, Marvin), the
same API and event streams (`/api/stream`, `/api/robot/stream`) as the Python host, the same rules
([docs/ui.md](../docs/ui.md)). `AppFilesTest` keeps it self-contained; `e2e/e2e.py` walks it in a browser. From this computer nothing is needed; other devices need the access key, which `./marvin up`
prints in the phone address (`http://<LAN address>:8765/?token=...`); the browser keeps it in a
cookie. `ApiContractIT` replays every request recorded from the Python host (marvin-contracts
`golden/api`) against the Java host and compares status, headers and shapes.

### The demo

`./marvin demo` runs the host on its own database (`marvin_demo`, emptied at every start: the
owner's data is never touched), imports a simulated past week and past conversations made by the
Python host's demo code, and starts the Python simulator as the robot. Time runs at its real pace
(the Python demo runs 10 times faster). The voice is the real one (`./marvin demo --voice` sets it
up); the Python demo's scripted voice is not ported.

### A robot, a simulator, the viewer

The robot finds the host by itself (it broadcasts `HELLO` to UDP 47100): a Wemos D1 mini with
simulated sensors, an ESP32-S3 DevKitC with the face, the MR60BHA2 bridge (a device of its own) all
link with `./marvin up` as they do with `marvin-host run`. Without hardware, the Python simulator
works unchanged against the Java host:

```bash
./marvin up
cd host && python3 -m marvin_host.cli sim --host 127.0.0.1     # or no --host: broadcast
./marvin status                                               # health: robot marvin-53494d (simulator)
```

The Rerun viewer is not ported (design 4.4): start the host with `MARVIN_TAP=47110 ./marvin up`,
then `marvin-host run --port 47110 --no-ui` shows what the Java host receives.

## Build and test

```bash
cd host-java
./mvnw verify          # unit tests, ArchUnit, Testcontainers integration tests (Docker needed)
./mvnw -q test         # unit tests and architecture rules only
```

`*Test` classes run in `test` (surefire), `*IT` classes in `integration-test` (failsafe). The
integration tests use `pgvector/pgvector:pg18` through Testcontainers and are skipped without
Docker; the embedded-database test is skipped when run as root (PostgreSQL refuses root). The voice
tests run the real Python sidecar in its test mode (`pip install -e "host[sidecar]"`) against a
stand-in for Ollama; they are skipped when the sidecar cannot run.

## Modules

| Module | Packages | Holds | May depend on |
|---|---|---|---|
| `marvin-domain` | `marvin.host.domain.<context>` | Model and domain services, plain Java | nothing (Maven enforcer) |
| `marvin-application` | `marvin.host.application.<context>`, `.port.in`, `.port.out` | Use cases and ports, plain Java | domain (Maven enforcer) |
| `marvin-adapter-web` | `marvin.host.adapter.web` | The app, its REST API and SSE (Spring MVC) | application |
| `marvin-adapter-robot` | `marvin.host.adapter.robot` | UDP protocol v1, `.mvrec`, datagram tap | application |
| `marvin-adapter-persistence` | `marvin.host.adapter.persistence` | PostgreSQL, one schema and one Flyway history per context | application |
| `marvin-adapter-llm` | `marvin.host.adapter.llm` | Spring AI's Ollama client (streamed chat, models), the tools' HTTPS requests; memory's model and embeddings (the JDK's HTTP client, so that a cancelled call really stops) | application |
| `marvin-adapter-sidecar` | `marvin.host.adapter.sidecar` | The voice sidecar over gRPC, the process supervisor, the demo's simulator | application, contracts |
| `marvin-app` | `marvin.host.app` | Spring Boot main, wiring; `ArchitectureTest` | everything |
| `marvin-contracts` | `marvin.host.contracts.voice.v1` (generated) | Golden files from the Python host, `voice.proto` ([README](marvin-contracts/README.md)) | protobuf, gRPC |

Bounded contexts today: `robot`, `presence`, `conversation`, `settings`, `system`, `face`, `memory`. A context
reaches another only through its application ports (`application.<context>.port.in|out`) and its
domain events (`domain.<context>.event`); `domain.shared` is the shared kernel. Each context owns a
PostgreSQL schema of the same name.

## Architecture rules

`marvin-app/src/test/java/marvin/host/app/ArchitectureTest.java`, on every build:

- onion architecture: domain, application, adapters; no adapter depends on another;
- the domain uses no framework and no I/O (`org.springframework`, `jakarta`, `javax`, `java.sql`,
  `java.net`, `java.io` except `Serializable`, gRPC, protobuf, Jackson, SLF4J);
- the application layer uses no framework either (Spring wiring lives in `marvin-app`);
- Spring AI only in the LLM and MCP adapters;
- no system clock in the domain and application (`System.currentTimeMillis`, `nanoTime`,
  `Instant.now`, ...): time comes from a `Clock` port or from the robot's frames;
- no cycles between the domain's or the application's contexts; ports are interfaces;
- bounded contexts talk through ports and events only (`ArchitectureRulesBiteTest` checks that
  this rule catches a violation).

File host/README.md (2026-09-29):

# Host software

The desktop side of Marvin: the robot's big brain. Today it receives the robot's sensor stream, places every point in the robot's frame and shows it live in [Rerun](https://rerun.io). A simulator produces the same stream, so all of this runs before any hardware arrives.

> **To run Marvin, use `./marvin up`** from the repository root: the Java host ([host-java](../host-java/README.md)), which starts this package's voice sidecar. The commands below are the first host, complete and kept as tools: the simulator, the Rerun viewer, recording and replay, calibration, and a voice in one process.

## Install

Python 3.10 or newer.

```bash
cd host
python3 -m venv .venv && source .venv/bin/activate
pip install -e ".[dev]"
```

## Use

```bash
marvin-host demo                   # simulated robot + live 3D view, nothing else needed
marvin-host ui --demo              # the app in the browser, with a simulated robot and week
marvin-host run                    # wait for the real robot: viewer, app (http://localhost:8765) and face link
marvin-host run --voice            # ... and talk to Marvin ("Marvin, ...") with the computer's mic
marvin-host -v run                 # the same, printing events, the conversation and a summary per second
marvin-host run --record day1.mvrec   # keep the raw sensor data; `marvin-host replay day1.mvrec` plays it back
marvin-host talk                   # voice only, no robot needed
marvin-host calibrate lidar --save # find the lidar's yaw (person moving in front of the robot)
marvin-host sim --model d800       # pretend to be the robot, for another machine running `run`
```

Voice needs the `voice` extra and Ollama: see [docs/voice.md](../docs/voice.md). The app (this host keeps its older one; the Java host has the current design): [docs/ui.md](../docs/ui.md). Recording, replay, calibration and wireless firmware updates: [docs/tools.md](../docs/tools.md).

The robot finds the host on its own: see [docs/protocol.md](../docs/protocol.md). On macOS, allow incoming connections for Python the first time the firewall asks.

## What the viewer shows

| View | Content |
|---|---|
| 3D | The robot, the lidar scan and the radar targets in the device frame; for a simulated robot, the room as faint wireframes. |
| Face | The robot's eyes, exactly as the 240 × 280 screen will show them, driven by the brain. |
| Camera | The camera image, with the lidar points and radar targets projected onto it. Simulated robots get a rendered image of the simulated room, at the robot's clock. |
| Lidar, top view | One full revolution seen from above, the robot's front up, coloured by distance, with range rings every metre and the LD2450 target. |
| mmWave radars | Radar-style view: the LD2450 sector (±60°, 6 m) with targets, speed and a 4-second trail; the MR60BHA2 vital-signs range and the person it measures. |
| Time series | Presence (targets, distance, speed, seated), vital signs (breath and heart rates, breathing and heartbeat waves), events, link statistics, log. |

## The brain and the face

[`brain.py`](marvin_host/brain.py) follows the nearest person seen by the LD2450 and turns the frames into events ([`events.py`](marvin_host/events.py)): `arrived`, `approached`, `sat_down`, `stood_up`, `still_long` (seated for 50 minutes: time for a break), `vitals_acquired`, `vitals_lost`, `left`. Every decision is debounced, and time comes only from the robot's clock, so a recording replays to the same events. `marvin-host run` prints them and shows them in the viewer.

[`face.py`](marvin_host/face.py) is the reference implementation of the robot's eyes: it follows your head, blinks, reacts to the events and falls asleep when you leave. It only draws rounded rectangles, ellipses and triangles, so it ports 1:1 to the ESP32-S3; see [docs/face.md](../docs/face.md).

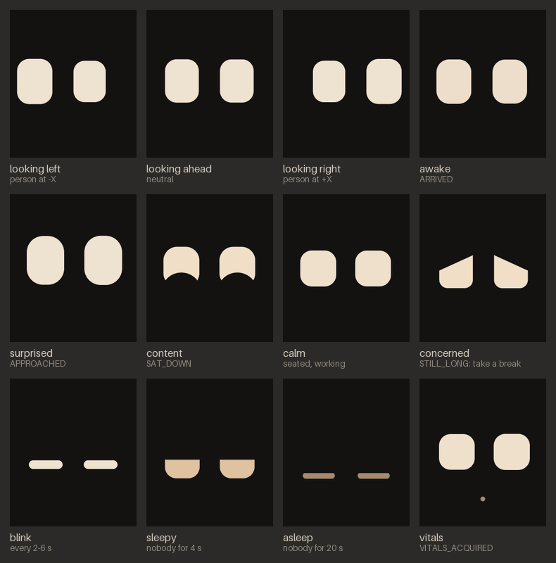
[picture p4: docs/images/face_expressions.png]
The face's expressions


## The simulated room

[`scene.py`](marvin_host/scene.py) describes a small home office (desk, workbench, sofa, wardrobe, plants) and a person who walks in, moves around, sits at the desk for half a minute, then leaves (70 s loop). The lidar only sees what crosses its plane, 133 mm above the desk, as the real one would. The same scene drives the host simulator, the simulated camera and the firmware simulator: after editing it, regenerate the firmware copy with `python -m marvin_host.scene > ../firmware/src/scene_data.h` (a test checks it).

## Layout

| Module | Role |
|---|---|
| `protocol.py` | UDP envelope, message types, `HELLO` |
| `ldrobot.py` | LDROBOT 47-byte lidar packets, CRC-8 |
| `ld2450.py` | HLK-LD2450 30-byte target frames |
| `frames.py` | Sensor extrinsics, conversions to the device frame |
| `receiver.py` | UDP server, handshake, loss counting, lidar revolution assembly; sink calls run on their own thread, so a slow viewer or model never delays the robot's `HOST_ACK` (stale lidar scans are dropped first, see `Device.stats.shed` and `Receiver.timings()`) |
| `viewer.py` | Rerun logging |
| `scene.py` | The simulated room and person (single source of truth) |
| `sim.py` | Simulated robot: lidar, LD2450 and MR60BHA2 frames from the scene |
| `camera.py` | Camera model and the simulated camera (numpy ray casting) |
| `events.py` | Events and presence state: the contract between the brain and what reacts to it |
| `brain.py` | Presence, seating, stillness and vital-sign reliability, as debounced events |
| `face.py`, `raster.py` | The robot's eyes (reference renderer and behaviour) and the tiny rasterizer they use |
| `link.py` | Host → robot face link: brain events (`FACE_EVENT`) and presence state (`FACE_STATE`, 10 Hz) to every robot with a screen |
| `audio.py` | Audio contract (sources and sinks, 16 kHz mono) shared by the voice and the robot's audio |
| `voice/` | Wake word, speech-to-text, local LLM and text-to-speech: talking to Marvin; `voice/tools/`: tools the model can call (the weather) |
| `sidecar/voice/` | The voice sidecar for the Java core: the same audio loop behind gRPC (`python -m marvin_host.sidecar.voice`, see [docs/voice.md](../docs/voice.md#the-voice-sidecar)) |
| `robot_audio.py`, `camera_stream.py` | The robot's microphone and speaker over UDP, its MJPEG camera |
| `ui/` | The app: a local web page with the face, today's timeline, breaks, history, the conversation (kept, searchable, each answer explained) and voice controls, the robot's devices and sensors, the log, settings |
| `record.py`, `calibration.py` | Recording and replaying raw sessions, sensor calibration |
| `cli.py` | The `marvin-host` command |

Tests: `pytest` (includes a real LD19 packet and the LD2450 datasheet example, and a full simulator → UDP → receiver run).

## Roadmap

1. Everything checked on the real hardware: sensors, screen, audio, camera, MR60BHA2 bridge.
2. The voice through the robot's microphone and speaker instead of the computer's.
3. Camera/lidar extrinsic calibration, and using the camera in the brain.
4. A dedicated "Marvin" wake-word model (Google Speech Commands).

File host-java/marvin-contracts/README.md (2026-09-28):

<!-- SPDX-License-Identifier: CC-BY-4.0 -->
# marvin-contracts

What the Java host must reproduce, taken from the Python host (`host/marvin_host`), and the
contract between the Java core and the voice sidecar. See [docs/design.md](../../docs/design.md),
sections 3.5 and 4.3.

Everything under `golden/` is **generated** by the scripts in `tools/`, from this checkout's Python
host. Do not edit it by hand. Regenerate only on purpose, and review the diff: these files are the
contract.

```bash
python3 host-java/marvin-contracts/tools/generate_all.py            # everything (about 40 s)
python3 host-java/marvin-contracts/tools/generate_all.py --no-api   # the deterministic part only
```

The scripts need the Python host's dependencies (`pip install -e "host[dev]"`), nothing else.
The Maven module puts `golden/` on the classpath under `marvin/contracts/golden/`, and
`src/main/proto/` under `marvin/contracts/proto/`, for the other modules' tests.

## What is here

| Path | Made by | Content |
|---|---|---|
| `golden/protocol/vectors.json` | `protocol_vectors.py` | Protocol v1 test vectors: every message type, whole datagrams as hex, their header and decoded values (`HELLO`, `LIDAR` with the LDROBOT manual's packet and CRC failures, `LD2450` with the datasheet frame, `VITALS`, `LOG`, `AUDIO_IN`; `HOST_ACK`, `FACE_STATE`, `FACE_EVENT`, `AUDIO_OUT`, `AUDIO_CTRL`, `SOUND`), invalid datagrams, and the protocol constants (CRC table, board ids, extrinsics) |
| `golden/recordings/*.mvrec.gz` | `recordings.py` | Recordings of the simulated robot (`.mvrec` v1, gzip): `room_loop` (walks in, sits, vital signs acquired and lost at each fidget, stands up, leaves), `lidar_yaw` (lidar mounted 37° off), `robot_reboot` (the device clock jumps back), `damaged_link` (lost datagrams, CRC errors, bad frames, junk) |
| `golden/recordings/*.events.jsonl` | `recordings.py` | The Python brain's events for each recording, in order, with their device times |
| `golden/recordings/*.states.jsonl` | `recordings.py` | The brain's presence state at the end of each device tick |
| `golden/recordings/*.scans.jsonl` | `recordings.py` | The lidar revolutions the receiver assembled (device time, points, speed) |
| `golden/recordings/index.json` | `recordings.py` | The scenarios, the receiver's counters per device, the brain's configuration, the lidar yaw estimate |
| `golden/api/get/*.json`, `post/*.json`, `access/*.json` | `api_snapshots.py` | Every app endpoint in demo mode: request, status, headers, body and its shape (see below); the access key rules |
| `golden/api/sse.json` | `api_snapshots.py` | The two event streams: event names, counts, a sample payload and the shapes of each |
| `golden/face/` | `face_vectors.py` | The face: each expression as PNG, the icon, and the scripted scenario of `host/scripts/face_golden.py` with the CRC-32 of every frame |
| `src/main/proto/marvin/voice/v1/voice.proto` | by hand | The gRPC contract between the Java core and the voice sidecar (design section 4) |

## How the Java host uses them

- **Protocol vectors**: the robot adapter decodes every `robot_to_host` datagram to the same
  values, encodes every `host_to_robot` input to the same bytes, and rejects the `invalid` ones.
  Python's `round()` rounds halves to even; the vectors pin it (Java: `Math.rint`).
- **Recordings**: replayed through the Java receiver and brain, each recording gives the same
  events at the same device times, the same states (floats within 1e-6), the same revolutions and
  the same receiver counters.
- **API snapshots**: the demo runs on a clock ten times faster than real time, so values change
  from run to run. The Java web adapter must answer each request with the same status, content
  type and **shape** (every value replaced by its JSON type; a list becomes the distinct shapes of
  its items), and with the same values where `index.json` does not list them as volatile (error
  messages, settings, the access rules). `get/voice_options.json` depends on the machine that
  recorded it.
- **Face**: pixels, compared through the CRC-32 of the RGB888 frames or the decoded PNGs.
- **voice.proto**: compiled by this module (Java classes in `marvin.host.contracts.voice.v1`),
  and by the Python sidecar with `grpcio-tools` in phase 2.

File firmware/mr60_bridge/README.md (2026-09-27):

# MR60BHA2 bridge

Firmware for the **Seeed MR60BHA2 kit** (60 GHz breathing and heartbeat radar on a XIAO ESP32C6). It replaces the kit's stock ESPHome firmware: it reads the radar and sends breathing rate, heart rate, both waves and the distance to the Marvin host as [`VITALS`](../../docs/protocol.md) messages.

## Why a separate firmware

The kit already has its own Wi-Fi microcontroller, the ESP32-C6 the radar is wired to. Rather than running a wire to the robot, the kit talks to the host directly, exactly like the robot does: same UDP protocol v1, same discovery (`HELLO` / `HOST_ACK`), its own device id. The host receives each device separately and the brain merges them, so the vitals arrive in the same stream as the robot's lidar and LD2450, whether the kit sits on the robot or on the desk.

## Hardware

Everything is on the kit's board; nothing to wire.

| Part | XIAO pin | GPIO | Notes |
|---|---|---|---|
| MR60BHA2 TX → C6 | D7 | 17 | UART1 RX, 115 200 baud 8N1 |
| C6 → MR60BHA2 RX | D6 | 16 | UART1 TX (not used yet) |
| WS2812 RGB LED | D1 | 1 | status light |
| BH1750 light sensor | D4 / D5 | 22 / 23 | I2C, not used yet |

Pins are those of Seeed's stock ESPHome configuration.

## Build and flash

1. Install PlatformIO: `pip install platformio` (or the VS Code extension).
2. Copy `include/secrets.example.h` to `include/secrets.h` and put your Wi-Fi in it (2.4 GHz network; same file format as the main firmware). `secrets.h` is ignored by git.
3. Plug the kit in with a USB-C cable (the port is on the XIAO), then:

```bash
cd firmware/mr60_bridge
pio run -t upload        # the first run downloads the ESP32-C6 toolchain, a few minutes
pio device monitor       # serial log at 115200 (Ctrl+C to quit)
```

If the upload cannot find or open the port (the stock firmware can keep the USB busy, or a crashed sketch can hide it): unplug the kit, **hold the XIAO's BOOT button** (marked B) while plugging it back in, release it, run the upload again, then press **RESET** (R) once it is done.

The official `platformio/espressif32` platform only supports ESP-IDF on the ESP32-C6. Arduino on the C6 needs Arduino-ESP32 3.x, packaged by the community [pioarduino](https://github.com/pioarduino/platform-espressif32) platform, pinned in `platformio.ini` to a release. pioarduino also calls itself `espressif32`, so this project keeps it in its own PlatformIO directory (`core_dir = ~/.platformio-pioarduino`): it cannot replace the platform used by the main firmware.

Unit tests of the radar parser, the vitals logic and the `VITALS` encoder run on the computer:

```bash
pio test -e native
```

### Back to the stock ESPHome firmware

Seeed's firmware can be put back at any time, in a Chrome or Edge browser:

- the [MR60BHA2 web flasher](https://limengdu.github.io/MR60BHA2_ESPHome_external_components/): plug the kit in, click CONNECT; or
- the `*.factory.bin` from the [releases of the ESPHome component](https://github.com/limengdu/MR60BHA2_ESPHome_external_components/releases), flashed with [ESPHome Web](https://web.esphome.io/).

Use the BOOT button as above if the browser cannot connect. The radar module keeps its own firmware either way; only the C6 is reflashed.

## Expected log

```
Marvin MR60BHA2 bridge mr60-bridge-0.1.0, board 4
radar on UART1, RX GPIO17, TX GPIO16, 115200 baud
joining my-network.......
IP 192.168.1.42, RSSI -61 dBm
linked to host 192.168.1.10
radar: nobody, breath 0.0/min, heart 0.0/min, distance 0 mm (frames 812, errors 0)
radar: person, breath 14.2/min, heart 71.0/min, distance 820 mm, valid (frames 1630, errors 0)
```

A status line is printed every 5 s. `radar: no data` means no valid frame came from the radar for 3 s: check that this is an MR60BHA2 kit (the MR60FDA2 fall kit looks the same). A growing `errors` count means corrupted UART frames. If the radar reports its firmware version, it is printed once and sent to the host in the `LOG` message on link (`firmware mr60-bridge-0.1.0 up, MR60BHA2 radar 1.2.3 (project 2)`, or `not reported`).

## Status light

The kit's RGB LED, kept dim:

| Light | Meaning |
|---|---|
| Blue blink | joining Wi-Fi (fast) or looking for the host (one short flash per second) |
| Slow green pulse | linked to the host, no valid vital signs |
| Soft red heartbeat | a person is measured; it beats at the measured heart rate |

## What is sent

`HELLO` every 0.5 s by broadcast until the host answers, then every 2 s to the host; board id **4**, flags 0 (real sensor data), firmware `mr60-bridge-0.1.0`. After 6 s without `HOST_ACK`, back to broadcasting. Once linked, `VITALS` every 100 ms (10 Hz) with the latest readings:

| `VITALS` field | From the radar (frame type) |
|---|---|
| valid | 1 only if someone is present (`0x0F09`, or a valid range `0x0A16` on radar firmware without `0x0F09`), the radar spoke in the last 3 s, and both a breath rate and a heart rate above zero arrived in the last 5 s |
| breath rate | `0x0A14`, float, per minute |
| heart rate | `0x0A15`, float, per minute |
| breathing wave | breath phase of `0x0A13`, rescaled (below) |
| heartbeat wave | heart phase of `0x0A13`, rescaled (below) |
| distance | `0x0A16` range when its flag is set, **cm × 10** → mm; 0 when unknown |

Rates and waves are 0 when nobody is present. A "nobody" report clears the rates, so after someone comes back `valid` waits for fresh ones.

**Wave scaling.** The radar's phases are in raw, uncalibrated units whose amplitude depends on distance and posture. Each one is rescaled to −1…1 by automatic gain: a slow moving average (10 s time constant) removes the offset, then the signal is divided by its recent peak, which decays with an 8 s time constant. The host therefore gets the shape and timing of each breath and beat, not an absolute amplitude. Waves are 0 when no phase frame came in the last second.

## Radar protocol

The radar sends Seeed's "tiny frame" protocol at 115 200 baud: `0x01`, frame id (u16), payload length (u16), type (u16), header checksum, payload, payload checksum; the header is big-endian, the payload little-endian (floats), checksums are the inverted XOR of their bytes. `lib/mr60` holds a small parser for it rather than Seeed's Arduino library: that library blocks the loop for the whole read timeout, allocates a vector per frame, reads payloads without checking their length, and is not in the PlatformIO registry. The parser is portable, uses a fixed buffer, resynchronises on the next frame after any error and is unit-tested.

| File | Role |
|---|---|
| `src/main.cpp` | Wi-Fi, host discovery, UART reading, `VITALS` at 10 Hz, status light and log |
| `lib/mr60/mr60.h`, `mr60.cpp` | Tiny-frame parser, vitals tracker, wave scaling, `VITALS` encoder (no Arduino) |
| `test/test_mr60/` | Unit tests (`pio test -e native`) |
| `../src/protocol.h` | Shared with the main firmware, included through `-I../src` |

## Known limits

- **Heart rate at a desk is not reliable.** Seeed recommends the breathing and heart rate functions for sleep only, with the kit about 1 m above the head, tilted 45° down, and asks not to use them while the person is seated at a desk or moving ([Seeed wiki](https://wiki.seeedstudio.com/getting_started_with_mr60bha2_mmwave_kit/)). Breathing and heart rate need a still person within about 1.5 m; presence works up to about 6 m. The host must treat these values as hints, never as measurements, and `valid` only means that the radar produced them.
- The distance unit (cm) follows ESPHome's MR60BHA2 component; `Tracker::CM_TO_MM` changes it if a real kit proves otherwise.
- Presence frames (`0x0F09`) and the firmware version frame only exist on newer radar firmware; without them, presence falls back to the range flag and the version shows as `not reported`.
- The light sensor, the target list (`0x0A04`) and the radar's configuration commands are not used yet.
- No OTA: updates go over USB.

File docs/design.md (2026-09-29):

<!-- SPDX-License-Identifier: CC-BY-4.0 -->
# Marvin's brain: design

This is the design for the next generation of Marvin's host software: a long-term memory, background agents, connectors to the owner's email and calendar, an identity that grows over time, and a new host core in Java. It builds on what runs today ([architecture.md](architecture.md), [voice.md](voice.md), [ui.md](ui.md), [protocol.md](protocol.md)) and on the perception plan in [intelligence.md](intelligence.md). Status: **proposal**, nothing here is implemented yet.

Versions and facts about third-party projects were checked in late September 2026; the sources are at the end.

## The design in one page

**Decisions already taken** (not up for debate in this document):

1. **One entry point.** One process starts everything on the host, and everything is controlled from the web app: voice on and off, settings, robots, memory, connectors, agents, logs.
2. **The host core is rewritten in Java with Spring Boot, as a hexagonal architecture** (ports and adapters). Later everything runs in Docker, then Kubernetes.
3. **Layered memory, agents and connectors**, with a hard **context budget** so that more knowledge never means a bigger, slower prompt.
4. **A Soul**: Marvin's identity with its owner, a fixed core written by the owner plus a learned part that changes only with the owner's approval.
5. **Microservices in the long term.** The host starts as one deployable, but its parts must be able to become separate services without a rewrite ([section 10.4](#104-toward-microservices)).

**What this document recommends:**

- **Java 25 (LTS), Spring Boot 4.1, Spring AI 2.0**, Maven multi-module, a framework-free domain, ArchUnit to keep it that way.
- **Machine learning stays in Python, in "sidecars"**: small local services behind ports, started and supervised by the Java host, so there is still one command. MLX (Whisper on the Apple GPU) cannot run in a container on macOS; the Mac runs the sidecars natively, Linux runs them in containers with CUDA.
- **The real-time audio loop lives in the voice sidecar** (microphone, VAD, echo gate, speculative STT, chunked TTS, barge-in). Java owns the conversation: context, model, tools, memory. The seam is "a transcript comes in, a stream of text goes out", which costs about a millisecond on localhost.
- **The Java host owns the robot's UDP socket** (protocol v1, unchanged) and relays audio frames to the voice sidecar. Rerun is not ported: a debug tap forwards raw datagrams to the existing Python viewer.
- **Memory is an append-only event log plus derived layers**: Soul (≈300 tokens, system prompt), Profile (≈500 tokens, rewritten nightly), Facts (bi-temporal, with provenance), Episodes (day → week → month summaries), Procedures. A memory worker consolidates when idle and at night. A context assembler builds each prompt under a hard per-section budget.
- **PostgreSQL 18 with pgvector everywhere**, including on the Mac. It needs no GPU, so it runs fine in Docker on macOS (or from Homebrew). One storage engine, one set of queries.
- **Spring AI for model clients** (Ollama chat and embeddings, tool calling, MCP client), **not for memory**: its chat memory is a message window and its vector store is a single document table; our memory model is the domain and gets its own schema.
- **Agents are background tasks** with their own context, tool subset, model and budget. Side effects need the owner's approval in the app. Marvin never sends an email: it writes drafts.
- **Migration is a strangler in seven phases (0 to 6) (about 22 to 28 weeks of full-time work for one developer)**. The protocol, the app and the recordings stay compatible at every step, and golden files taken from the Python host are the contract the Java host must reproduce.

```mermaid
flowchart LR
  subgraph Robot["Robot (ESP32-S3, MR60BHA2 kit)"]
    R["sensors, face, mic, speaker"]
  end
  subgraph Host["Host: one command"]
    CORE["Java core<br/>Spring Boot, hexagonal"]
    VOICE["Voice sidecar<br/>Python: VAD, Whisper, Piper"]
    VISION["Vision sidecar<br/>Python, later"]
    PG[("PostgreSQL<br/>+ pgvector")]
    OLL["Ollama<br/>chat + embeddings"]
  end
  UI["Web app<br/>phone, browser"]
  MCP["MCP servers<br/>calendar, email, ..."]
  R <-->|"UDP protocol v1"| CORE
  R -->|"MJPEG"| VISION
  CORE <-->|"gRPC: audio frames,<br/>transcripts, text"| VOICE
  CORE <-->|gRPC| VISION
  CORE --> PG
  CORE -->|HTTP| OLL
  CORE <-->|"REST + SSE"| UI
  CORE <-->|MCP| MCP
```

## 1. Goals and non-goals

**Goals**

- Marvin remembers what matters about its owner over months and years, and can say where each thing it knows came from.
- A spoken answer stays as fast as today (first word ≈ 1.1–1.6 s with a 4B model and Piper), however much Marvin knows.
- Long jobs ("prepare my week", "find the email about the car insurance") run in the background without blocking the conversation.
- Everything is visible and controllable from the one web app: nothing happens that the owner cannot see, undo or turn off.
- The host core is maintainable for years: strict boundaries, fast tests, one language for the core.
- Every step of the migration leaves a working robot.

**Non-goals**

- A general agent platform. Marvin is one companion for one home; there is no multi-tenancy.
- Autonomous actions in the world. Marvin proposes; the owner disposes.
- Rewriting working ML code in Java. Whisper, Piper, VAD and future vision models stay Python or C++.
- Cloud-first anything. Cloud models are an opt-in per task, never a dependency.
- A protocol v2. The robot does not change for any of this.
- Medical interpretation of vital signs. Marvin keeps measuring, not diagnosing ([intelligence.md](intelligence.md)).

## 2. Privacy principles

These are design constraints, checked in code review and, where possible, in tests.

1. **Local first.** Memory, recordings, audio and images live on the owner's machine. Local models by default. The only network traffic without explicit consent is what the owner already enabled (the weather tool, the connectors).
2. **The owner sees, edits and deletes everything.** Every fact shows its sources; every summary, profile and soul version is readable and editable in the app. "Forget this" deletes the item and everything derived only from it, and marks the summaries that used it for regeneration.
3. **Switches per source.** Sensors, conversation, camera, each connector: each has an on/off switch for *collection* and a separate one for *memory* (a connector can be usable as a tool without anything being remembered from it).
4. **Sensitivity labels on everything.** Each event and fact carries one of `normal`, `personal`, `sensitive` (health including vital signs, finances, third parties' private matters), `secret` (credentials, codes, never stored: dropped at ingestion). `sensitive` data never goes to a cloud model and is never spoken while someone else is detected in the room.
5. **Third parties.** People mentioned in email or conversation are remembered only in relation to the owner ("the owner's brother lives in Lyon"), never profiled.
6. **Export.** One button exports everything as a zip of JSON (machine-readable, the full schema) and Markdown (readable: profile, soul, facts, episodes).
7. **No dark patterns.** Marvin does not try to increase how much it is used (see [Soul guardrails](#guardrails)).

## 3. Architecture overview

### 3.1 Hexagonal core

The core is a set of domain modules with no framework and no I/O. It talks to the world only through ports: interfaces owned by the core, implemented by adapters.

```mermaid
flowchart TB
  subgraph IN["Inbound adapters"]
    WEB["Web: REST + SSE"]
    UDP["Robot link: UDP protocol v1"]
    SCHED["Scheduler: cron, idle"]
    VIN["Voice events<br/>(from the sidecar)"]
  end
  subgraph CORE["Core (plain Java)"]
    direction TB
    APP["Application: use cases"]
    subgraph DOM["Domain"]
      D1["Robots & sensing"]
      D2["Presence (brain, events)"]
      D3["Conversation"]
      D4["Memory"]
      D5["Agents & tasks"]
      D6["Connectors"]
      D7["Soul"]
      D8["Settings"]
    end
    APP --> DOM
  end
  subgraph OUT["Outbound adapters"]
    LLM["Language model: Ollama<br/>(cloud, opt-in)"]
    EMB["Embeddings: Ollama"]
    VOUT["Voice channel, STT batch<br/>(sidecar, gRPC)"]
    VIS["Vision (sidecar)"]
    DB["Persistence + vectors:<br/>PostgreSQL, pgvector"]
    MCPC["Connectors: MCP client"]
    NOTE["Notifications"]
    RTX["Robot out: face, audio,<br/>sounds (UDP)"]
    SEC["Secrets: keychain, files"]
  end
  IN --> APP
  APP --> OUT
```

**Domain modules**

| Module | Holds | Comes from |
|---|---|---|
| Robots & sensing | `Device`, link state and stats, LD2450 targets, lidar revolutions, vitals, parsers for the raw frames | `receiver.py`, `protocol.py`, `ldrobot.py`, `ld2450.py`, `frames.py` |
| Presence | `Brain`, `PresenceState`, `Event` (arrived, sat_down, ...) | `brain.py`, `events.py` |
| Conversation | `Turn`, `Heard`, `Reply`, tool loop, persona text, fillers, the "why Marvin said that" record | `voice/assistant.py` (the non-audio half), `persona.py`, `tools/` |
| Memory | event log, facts, episodes, profile, procedures, consolidation rules, context assembler, retrieval scoring | new |
| Agents & tasks | `Task`, lifecycle, `Budget`, `Approval`, agent loop | new |
| Connectors | `Connector`, scopes, ingestion policy, cursors | new |
| Soul | core, learned part, versions, reflection proposals | new |
| Settings | typed settings, validation, defaults | `ui/server.py`, `voice/control.py` |

**Ports**

| Direction | Port | Adapter (first) | Notes |
|---|---|---|---|
| In | `WebApi` | Spring MVC, SSE | Same endpoints as today's app (see [ui.md](ui.md)), plus new sections |
| In | `RobotInbound` | UDP 47100, protocol v1 | Handshake, parsing, loss counting, lidar revolutions |
| In | `Schedule` | Spring scheduling | Nightly consolidation, weekly reflection, connector sync, idle detection |
| In | `VoiceEvents` | gRPC stream from the voice sidecar | `heard`, `ignored`, `status`, `level`, `partial`, `say` progress |
| Out | `RobotOutbound` | UDP | `HOST_ACK`, `FACE_STATE`, `FACE_EVENT`, `AUDIO_OUT`, `AUDIO_CTRL`, `SOUND` |
| Out | `LanguageModel` | Spring AI `OllamaChatModel`, streamed | Cloud adapter only for tasks with consent |
| Out | `Embeddings` | Spring AI Ollama embeddings | One model for everything, dimension fixed in the schema |
| Out | `VoiceChannel` | gRPC to the voice sidecar | See [section 4](#4-the-ml-reality-sidecars): one bidirectional port rather than separate STT and TTS |
| Out | `SpeechToText` (batch) | gRPC to the voice sidecar | Transcribing recordings, not the live loop |
| Out | `Vision` | gRPC to the vision sidecar | Later: faces, pose, as brain inputs |
| Out | `EventLog`, `MemoryStore`, `TaskStore`, ... | JDBC, Flyway, pgvector | Repositories per module |
| Out | `ConnectorClient` | Spring AI MCP client | Plus native adapters where MCP lacks incremental sync |
| Out | `Notifier` | SSE to the app, robot speech/earcon, optional push | |
| Out | `AudioDevices`, `Camera` | inside the sidecars | The core never opens a sound card or a camera |
| Out | `SecretStore` | macOS Keychain, file with 0600, Docker/Kubernetes secrets | Never the database, never logs, never prompts |
| Out | `Clock` | system clock; device clock for sensor time | Tests inject a fake clock; replays use the robot's clock as today |

**Why `VoiceChannel` and not separate STT and TTS ports.** The live loop couples them in time: the echo gate needs to know when the speaker really played the last sample; barge-in stops TTS from what the microphone hears; speculative STT starts before the end of speech. Splitting them across a process boundary would put a 20 ms-granularity real-time loop on two sides of a socket. The honest port is "a voice that hears and speaks", with a batch STT port on the side.

### 3.2 Versions

| Component | Version | Why |
|---|---|---|
| Java | **25 LTS** | The current LTS (September 2025). JDK 27 (September 2026) is not LTS and Spring Boot 4.1 supports Java 17–26. The next LTS, 29, is due September 2027. |
| Spring Boot | **4.1.x** (4.1.1, August 2026) | Current stable line, open-source support to July 2027. 4.2 is at milestone 2. |
| Spring AI | **2.0.x** (2.0.1, August 2026) | GA in June 2026, built for Boot 4.0/4.1; Ollama chat with streaming, tool calling and `think` control; Ollama embeddings; MCP client and server on MCP Java SDK 2.0. |
| PostgreSQL | **18** + pgvector **0.8.x** | 19 is still in beta. |
| ArchUnit | **1.5.x** | |
| Python (sidecars) | 3.12, managed with `uv` | One lock file per sidecar; reproducible on the Mac and in containers. |

Virtual threads on (`spring.threads.virtual.enabled=true`): the UDP loop, sidecar streams and SSE are all blocking I/O, and virtual threads keep that code straightforward. Generational ZGC keeps pauses well under a millisecond, far below the 20 ms audio frame.

### 3.3 Build: Maven, multi-module

**Recommendation: Maven** with the wrapper. The module graph is small (about ten modules), the build is not a bottleneck, and Maven's declarative model, `enforcer` (dependency convergence, banned dependencies in the domain) and the Spring Boot parent give guardrails with no build logic to maintain. Gradle would be faster on incremental builds and could drive the Python builds, but a build script is code, and nothing here needs it. The Python sidecars keep their own `uv` projects; CI runs both.

```
host-java/
├── pom.xml                         # parent: versions, enforcer, ArchUnit, Spotless
├── marvin-domain/                  # plain Java: model, domain services, NO Spring, NO I/O
│   └── marvin.host.domain.{robot,presence,conversation,memory,agent,connector,soul,settings}
├── marvin-application/             # use cases + port interfaces; depends on domain only
│   └── marvin.host.application.{robot,conversation,memory,agent,connector,soul}
│       ├── port.in                 # WebApi-facing use-case interfaces
│       └── port.out                # LanguageModel, Embeddings, VoiceChannel, EventLog, ...
├── marvin-adapter-web/             # Spring MVC, SSE, static app (moved from host/marvin_host/ui/static)
├── marvin-adapter-robot/           # UDP protocol v1: receiver, sender, .mvrec record/replay
├── marvin-adapter-persistence/     # JDBC, Flyway migrations, pgvector
├── marvin-adapter-llm/             # Spring AI: Ollama chat and embeddings, optional cloud
├── marvin-adapter-sidecar/         # gRPC clients, process supervisor, health checks
├── marvin-adapter-mcp/             # Spring AI MCP client, native connector adapters
├── marvin-adapter-notify/          # notification channels
├── marvin-app/                     # Spring Boot main, configuration, wiring, scheduler
└── marvin-contracts/               # .proto files, protocol test vectors, golden files (shared with Python)
sidecars/
├── voice/                          # Python: the current voice package, minus LLM/tools/persona
└── vision/                         # Python, later
```

Naming: packages `marvin.host.<layer>.<module>`; ports end in the role they play (`LanguageModel`, `EventLog`), adapters say their technology (`OllamaLanguageModel`, `JdbcEventLog`); use cases are verbs (`AnswerQuestion`, `ConsolidateMemory`, `ApproveAction`). Domain events are records in the past tense (`PersonArrived`, `FactLearned`).

Spring Modulith was considered for module boundaries and its event publication registry. ArchUnit covers the boundaries we need without tying the domain to Spring; the event log (below) already gives us durable, replayable events.

Because the long-term target is microservices (section 10.4), the domain and application modules are cut along **bounded contexts** (robot, presence, conversation, memory, agent, connector, soul, settings), and ArchUnit also forbids one context from reaching into another's internals: contexts talk through their application ports and through events only, and each owns its own Postgres schema. That is what makes a later split a deployment change instead of a rewrite.

### 3.4 ArchUnit rules

One test class in `marvin-app` (it sees every module), run on every build:

```java
@AnalyzeClasses(packages = "marvin.host")
class ArchitectureTest {
  @ArchTest static final ArchRule hexagon = onionArchitecture()
      .domainModels("marvin.host.domain..")
      .domainServices("marvin.host.domain..")
      .applicationServices("marvin.host.application..")
      .adapter("web", "marvin.host.adapter.web..")
      .adapter("robot", "marvin.host.adapter.robot..")
      .adapter("persistence", "marvin.host.adapter.persistence..")
      .adapter("llm", "marvin.host.adapter.llm..")
      .adapter("sidecar", "marvin.host.adapter.sidecar..")
      .adapter("mcp", "marvin.host.adapter.mcp..")
      .adapter("notify", "marvin.host.adapter.notify..");

  @ArchTest static final ArchRule pureDomain = noClasses().that().resideInAPackage("marvin.host.domain..")
      .should().dependOnClassesThat().resideInAnyPackage(
          "org.springframework..", "jakarta.persistence..", "java.sql..", "java.net..", "io.grpc..");

  @ArchTest static final ArchRule noSpringAiOutsideAdapters = noClasses()
      .that().resideOutsideOfPackages("marvin.host.adapter.llm..", "marvin.host.adapter.mcp..", "marvin.host.app..")
      .should().dependOnClassesThat().resideInAPackage("org.springframework.ai..");

  @ArchTest static final ArchRule modulesDoNotCycle = slices()
      .matching("marvin.host.domain.(*)..").should().beFreeOfCycles();

  @ArchTest static final ArchRule noSystemClock = noClasses().that().resideInAPackage("marvin.host.domain..")
      .should().callMethod(System.class, "currentTimeMillis");   // time comes from the Clock port
}
```

Onion architecture already forbids adapter-to-adapter dependencies and any dependency from the core to an adapter. The Maven module split makes most violations impossible to compile; ArchUnit catches the rest (inside a module, and the Spring AI rule).

### 3.5 Testing strategy

| Level | What | How |
|---|---|---|
| Domain unit tests | Brain, retrieval scoring, context budget, consolidation rules, task state machine, soul guardrails | JUnit 5, no Spring, fake `Clock`; milliseconds each |
| Golden tests from Python | The brain and the parsers must reproduce the Python host exactly | Fixtures in `marvin-contracts/golden/` (below) |
| Protocol contract tests | Every message type, byte for byte, both directions | Test vectors from `test_protocol.py` (the real LD19 packet, the LD2450 datasheet frame) exported as hex + expected JSON; a Java simulator run over real UDP on localhost, as `test_receiver.py` does |
| Replay tests | A `.mvrec` recording through the Java receiver gives the same events as through the Python one | The Java adapter reads and writes `.mvrec` v1 (the format is small, see `record.py`) |
| Adapter tests | JDBC + pgvector, Flyway migrations, Ollama client | Testcontainers (`pgvector/pgvector:pg18`, the Ollama module with a tiny model), Spring Boot `@ServiceConnection` |
| Sidecar contract tests | The gRPC contract in both languages | Same `.proto`; Python tests with a fake Java peer and the reverse; audio fixtures as WAV |
| UI API contract | The existing app keeps working unchanged | JSON snapshots of today's endpoints, recorded from the Python server in demo mode, replayed against the Java server |
| LLM behaviour | Tool choice, extraction quality | A small evaluation set run on demand (not in CI): questions → expected tool calls; conversations → expected facts. Scored, tracked over time |

**Golden files.** The Python tests generate their recordings on the fly (`record.write_simulated`); they are not in the repository. Phase 0 adds a script that writes a few small recordings (walk in, sit, stand up, leave; vitals acquired and lost; a lidar yaw offset) and, next to each, the Python brain's events and presence states as JSON Lines. These files are the contract: the Java brain must produce the same events at the same device times. They are regenerated only on purpose, and the diff is reviewed.

## 4. The ML reality: sidecars

### 4.1 What runs where

The best speech stack on the Mac is Python or C++ on the Apple GPU:

- **MLX Whisper** (large-v3-turbo on the GPU, a few hundred ms per question) is what Marvin uses on Apple Silicon today.
- **faster-whisper** (CTranslate2) runs on CPU and NVIDIA CUDA; it has no Metal backend.
- **whisper.cpp** runs on Metal and Core ML, CUDA, Vulkan and more, ships an HTTP server and Silero VAD.
- **Piper** runs on CPU with ONNX, fast enough (a sentence in about 0.1 s).

**MLX and Metal are not available inside Docker containers on macOS.** Containers run in a Linux VM with no Metal passthrough; Docker's own Model Runner runs its Metal backend natively on the host for exactly that reason. The partial exception: Podman with the libkrun/krunkit VM exposes a Vulkan GPU to containers (translated to Metal through MoltenVK), which gets llama.cpp close to native speed; it does not help MLX. Ollama in a container on a Mac runs on the CPU only.

So:

- **On the Mac, sidecars run natively**, as child processes of the Java host, from `uv`-managed environments. Ollama runs natively (the app or `ollama serve`).
- **On Linux with an NVIDIA GPU, sidecars run in containers** with faster-whisper or whisper.cpp on CUDA, and Ollama in a container or natively.
- The sidecar's backend is a setting (`mlx`, `faster-whisper`, `whisper.cpp`), as the STT backend is today.

**Piper's licence.** Piper moved to `OHF-Voice/piper1-gpl` (the original repository was archived in October 2025) and is now GPL-3.0. The host is MIT. Running Piper in a separate process, as a sidecar, keeps the two apart; a published container image that bundles Piper must meet the GPL for that component. The voice models have their own licences, listed per voice.

### 4.2 The supervisor: still one entry point

`marvin-app` starts, watches and stops the sidecars:

- A sidecar is declared in configuration: command (native) or image (containers), gRPC port, health check, required or optional.
- Start: spawn (`ProcessBuilder`), wait for the gRPC health check, then mark the port ready. Logs are piped into the app's Log panel with the sidecar's name.
- Crash: restart with exponential backoff (1 s → 60 s), shown in the app with the last error lines. A missing Python environment gives a fix, as today's voice panel does ("run `uv sync` in `sidecars/voice`").
- Stop: graceful shutdown over gRPC, then `SIGTERM`, then `SIGKILL` after 5 s. A shutdown hook makes sure no orphan survives the host.
- In Docker Compose or Kubernetes, the supervisor switches to "external" mode: it only checks health and reports; the orchestrator restarts.

### 4.3 Where the audio loop lives

**Recommendation: the whole real-time loop lives in the voice sidecar. Java owns what to say.**

The current pipeline is already split along this line in all but name: `assistant.py` mixes an audio machine (capture, VAD, echo gate, wake word, speculative STT, chunking, synthesis, playback, barge-in) with a conversation (context, model, tools, history). The audio half is timing-critical, tested, and depends on Python libraries. The conversation half is where all the new work (memory, agents, soul) happens.

| Stays in the voice sidecar (Python) | Moves to the Java core |
|---|---|
| Audio I/O: the Mac's microphone and speakers (`io.py`); the robot's audio as frames relayed by Java | Owning the robot's UDP socket and relaying `AUDIO_IN` / `AUDIO_OUT` / `AUDIO_CTRL` / `SOUND` |
| VAD and segmentation (`vad.py`) | Deciding whether and what to answer, with the conversation history |
| Echo gate and echo filter (`echo.py`) | Context assembly from memory and sensors (`persona.py`'s context block, extended) |
| Wake word, listening windows, follow-up window, "merci" ends the conversation (`wake.py`, `filters.py`) | The model call, streamed; the tool loop, fillers, `</think>` handling (`llm.py`, `tools/`, `text.strip_thinking`) |
| Speculative and final STT, hallucination filters (`stt.py`, `filters.py`) | Tools: weather, recall, calendar, delegate a task |
| Chunking text for speech, cleaning it (`text.py`: first clause early, no markdown, no JSON) | Proactive speech decisions (`proactive.py`: reminders, welcome back, notifications) |
| TTS and playback pacing (`tts.py`, the robot speaker's 150 ms lead from `robot_audio.py`) | Recording every turn in the event log, with its latency breakdown |
| Live signals for the app: level, utterance, partial, say | Forwarding those signals to the app over SSE |

**One turn:**

```mermaid
sequenceDiagram
  participant R as Robot
  participant J as Java core
  participant V as Voice sidecar
  participant O as Ollama
  R->>J: AUDIO_IN (20 ms frames, UDP)
  J->>V: frames (gRPC stream, same bytes)
  V->>V: VAD, echo gate, wake word, speculative STT
  V->>J: heard("what's on tomorrow?", timings)
  J->>J: assemble context (memory, sensors, calendar) under budget
  J->>O: chat (stable system prompt, history, context + question), streamed
  O-->>J: tokens
  J->>V: text pieces, as they come
  V->>V: chunk, synthesise, pace
  V->>J: speaker frames
  J->>R: AUDIO_OUT (UDP)
  V->>J: say progress, done
```

**What this costs.** Each hop over localhost gRPC costs roughly 0.1–0.5 ms. Audio frames arrive every 20 ms, so relaying them through Java adds well under a frame. The turn itself adds two hops: the transcript to Java, the first text piece back. Together: about a millisecond, against a first word at 1.1–1.6 s. The latency that matters is elsewhere and does not change: 0.55 s of silence to end a question, recognition, the model's first token (which the prompt design below protects), the first chunk's synthesis.

**The alternative** was to keep the audio loop in Java and call STT and TTS as remote functions. It would split the echo gate from the speaker it gates, put audio devices behind Java Sound (weak on macOS), and rewrite a few thousand lines of tested timing code for no user-visible gain. Rejected.

**The gRPC contract** (`marvin-contracts/voice.proto`), sketched:

```proto
service Voice {
  rpc Session(stream CoreToVoice) returns (stream VoiceToCore);   // one long-lived bidi stream
  rpc Transcribe(AudioClip) returns (Transcript);                  // batch, for recordings
  rpc Options(Empty) returns (VoiceOptions);                       // backends, models, voices
}
message CoreToVoice { oneof m {
  Configure configure = 1;  AudioFrame robot_mic = 2;   // relayed AUDIO_IN, with sample index and robot clock
  ReplyStart reply_start = 3;  TextPiece text = 4;  ReplyEnd reply_end = 5;
  Say say = 6;  ListenNow listen_now = 7;  Mute mute = 8;  StopSpeaking stop = 9; } }
message VoiceToCore { oneof m {
  Status status = 1;  Heard heard = 2;  Ignored ignored = 3;  Level level = 4;  Partial partial = 5;
  SpeakerFrame robot_speaker = 6;  RobotAudioCtrl ctrl = 7;  SayProgress say = 8;  Interrupted interrupted = 9; } }
```

### 4.4 Rerun

Rerun has no Java SDK, and the web app already has lidar, radar and vital-sign views. **Rerun is not ported.** The Java robot adapter gets a **datagram tap**: an option that forwards every received datagram, unchanged, to a localhost UDP port. The existing Python receiver and viewer read it (`marvin-host viewer --tap 47110`), and they already replay `.mvrec` files, which the Java host writes in the same format. The 3D view stays a developer tool, with no cost to the core. The same goes for the simulator (`marvin-host sim`): it pretends to be a robot over UDP and works against the Java host unchanged.

## 5. Memory

### 5.1 Layers

| Layer | Size | Where it goes | Changes | Written by |
|---|---|---|---|---|
| **Soul** | ≈ 300 tokens | System prompt | Rarely (approved versions) | Owner (core), weekly reflection (learned part, approved) |
| **Profile** | ≈ 500 tokens | System prompt, after the soul | Nightly, **rewritten, not appended** | Memory worker; owner edits win |
| **Facts** | Unbounded; ≤ 300 tokens retrieved per turn | Retrieved into the question's context block, or via `recall` | Continuously | Memory worker, owner |
| **Episodes** | Day, week, month summaries | Today's and yesterday's gist in context (≤ 150 tokens); older ones via `recall` | Daily, weekly, monthly | Memory worker |
| **Procedures** | A few dozen routines | Matched by trigger; the matched one's line in context | Rarely, approved | Owner, or proposed by reflection |
| **Raw log** | Everything | Never in context directly; the source of truth | Append-only (deletions are real) | Every part of the system |

The Soul and Profile are what Letta calls core memory blocks: always in context, labelled, size-limited. Facts follow Graphiti's bi-temporal model. The extraction step follows mem0. Episodes are a summary hierarchy. Retrieval scoring follows the Generative Agents paper. None of these libraries is used directly (see [5.8](#58-what-we-take-from-existing-libraries)).

### 5.2 The write path

**Everything is an event in one append-only log**: what Marvin heard and answered (today's `conversation` table), brain events and per-minute samples (today's `events` and `samples`), connector items (an email arrived, a calendar event changed), task results, the owner's feedback and edits. Each event has a source, a sensitivity label and, when it comes from outside, a reference to the original (a message id, an event id).

```mermaid
flowchart LR
  subgraph Sources
    C["Conversation turns"]
    B["Brain events,<br/>minute samples"]
    K["Connector items"]
    T["Task results"]
    F["Owner feedback, edits"]
  end
  Sources --> LOG[("Event log<br/>append-only")]
  LOG --> W["Memory worker<br/>(idle + nightly)"]
  W --> FA[("Facts<br/>bi-temporal")]
  W --> EP[("Episodes<br/>day → week → month")]
  W --> PR["Profile<br/>(rewrite)"]
  W -.weekly proposal.-> SO["Soul<br/>(owner approves)"]
  W -.proposal.-> PC["Procedures<br/>(owner approves)"]
```

**When the worker runs:**

- **Idle pass**: nobody has talked to Marvin for 10 minutes and no conversation is open. Processes new events since the last pass: extraction and fact updates only. Stops between steps as soon as the voice becomes active (the GPU belongs to the conversation).
- **Nightly pass** (default 03:00, or the first idle hour after it if the Mac was asleep): the day summary, week and month roll-ups when due, the profile rewrite, decay, then re-warming the voice model's prompt cache with the new profile, so the morning's first question is not slow.

**Steps of a pass:**

1. **Extract.** For each batch of new events (a conversation, a day of sensor summaries, a set of emails), ask the model for candidate facts as structured output (Ollama's JSON schema mode): `{subject, statement, valid_from?, valid_to?, importance 1–10, sensitivity, confidence}`. Input: the batch, the current profile, and the date, so relative times ("next Tuesday") resolve against the event's own timestamp.
2. **Reconcile** (mem0's update phase, Graphiti's invalidation). For each candidate, fetch the 10 most similar current facts; the model picks one operation:
   - `ADD` a new fact;
   - `UPDATE`: same fact, better wording or new detail → new version, the old one marked superseded;
   - `INVALIDATE`: the world changed ("moved to Lille" after "lives in Lyon") → the old fact gets `valid_to` (the world's time) and `expired_at` (our time); nothing is deleted;
   - `NOOP`.
3. **Link provenance**: every fact keeps the ids of the events it came from.
4. **Summarise** (nightly): the day's episode from its events (≤ 200 words), then the week from its days and the month from its weeks.
5. **Rewrite the profile** (nightly): from the previous profile, the day's new and invalidated facts, and the owner's edits. Hard limit 500 tokens; the rewrite is a new version with a diff, visible in the app. Lines the owner wrote or pinned are kept verbatim.
6. **Decay** (nightly): each fact's retrieval weight decays with time since it was last used; facts below a threshold are archived (still searchable with `recall`, never auto-retrieved). Nothing is deleted by decay.
7. **Retention** (nightly): raw sensor samples older than the retention setting (default 1 year) are reduced to their day summaries. Conversation text is kept until the owner says otherwise.

Honest limits: a 4–8B local model is mediocre at extraction. It misses facts, merges people, misreads dates. That is why every fact has provenance and a confidence, why the owner can fix anything in the app, why a larger local model (up to 27–32B, if the Mac has the memory) is used at night when speed does not matter, and why the extraction prompts are measured against a small evaluation set before they change.

### 5.3 The read path: a context assembler with a budget

The **context assembler** builds each prompt from sections, each with a hard token budget. When a section overflows, it is cut by score, never by position. Budgets depend on the path: the voice path is small because every token in the volatile part is processed again at each turn; background agents get more.

**Prompt layout, voice path** (target model context: 8192 tokens, as today):

| Part | Section | Budget | Changes | Cached by Ollama |
|---|---|---:|---|---|
| System | Rules (today's persona: body, how to speak, tools usage) | ≈ 600 | With the code | Yes |
| System | Soul | 300 | Rarely | Yes |
| System | Profile | 500 | Nightly | Yes (re-warmed after the rewrite) |
| System | Tool schemas | ≈ 400 | With settings | Yes |
| History | Previous turns, whole turns only | ≤ 2500 | Each turn | Yes (the prefix grows) |
| Last message | Now: time, presence, seated for, vitals, room | 120 | Each turn | No |
| Last message | Today so far (episode gist) + next calendar items | 150 | Each turn | No |
| Last message | Retrieved facts (top 5) | 300 | Each turn | No |
| Last message | Matched procedure, open tasks, pending approvals | 80 | Each turn | No |
| Last message | The question | ≈ 50 | | No |

About 1800 tokens of "memory" in total (soul, profile and the volatile block), of which only ≈ 700 are new at each turn. That distinction is the key to latency: Ollama reuses the cached prefix (system prompt and history), so what costs time at each turn is the volatile block. A 4B model on Apple Silicon processes a prompt at hundreds to a few thousand tokens per second depending on the chip; 700 tokens is a fraction of a second at worst, and the assembler logs `prompt_eval_count` and `prompt_eval_duration` from Ollama's response so the budget is tuned on measurements, not guesses.

**Keeping the prompt cache.** The rule already in place today stays: the system prompt is byte-identical from one question to the next; the live context goes into the last user message. New: the soul and profile join the system prompt because they change at most daily; the profile rewrite is followed by a warm-up. Tool schemas are sorted and canonical, as today. The history keeps its past context blocks (they are part of the cached prefix; stripping them would invalidate it).

**Token counting.** Java has no Qwen tokenizer at hand. The assembler estimates tokens with a characters-per-token ratio per language, calibrated continuously from Ollama's `prompt_eval_count`, and keeps a 10 % margin.

**Retrieval scoring** for auto-retrieved facts, as in Generative Agents, as a weighted sum of normalised terms rather than a product (with a product, one weak term hides a fact that is both very relevant and very important):

```
score = 1.0 · relevance + 0.5 · recency + 0.7 · importance
relevance  = cosine(question embedding, fact embedding)            (min-max over the candidates)
recency    = 0.995 ^ hours since the fact was last used or learned
importance = importance / 10
```

Candidates: the 30 nearest facts by vector (pgvector HNSW), filtered to currently valid (`expired_at IS NULL AND (valid_to IS NULL OR valid_to > now())`), not archived, and allowed by the path (no `sensitive` facts when a guest is detected, none at all for a cloud model). Then scored, cut to the budget. A relevance floor keeps irrelevant facts out: an empty section is better than noise. The question's embedding is computed on the speculative transcript as soon as it exists, so retrieval (tens of milliseconds) overlaps the end of recognition.

**As built (memory v1, read path).** As above, with these deliberate differences, explained in [host-java/NOTES.md](../host-java/NOTES.md) ("Memory v1, read path"): the "now" section's budget is 200 tokens, not 120 (the brain's context is up to about 230 real tokens, and the line saying the sensors are simulated, which must never be cut, is about 100 of them); the history is held to its 2500 tokens by dropping its older half at once, as the turn limit already does; the question waits at most 300 ms for its memory, then goes without; "today so far" is today's and yesterday's day summaries, sentence by sentence (a day is summarised the night after); the relevance floor is 0.45 (qwen3-embedding:8b). `forget` answers a six-character code and forgets only when it comes back in a later turn, or when the owner confirms in the app. The retrieval, the tools and the memory API are described in [memory.md](memory.md). Since the review fixes: the memory sections share one budget of 250 tokens (`marvin.memory.volatile-budget`), filled by score, because what memory adds to every question's prompt evaluation is what it costs the first word; the conversation's history is dropped when a guest comes in and after anything is forgotten; with a guest, `remember` only suggests and a forget is confirmed in the app.

**Tools for deep dives**, offered to the model like `get_weather`:

| Tool | Does |
|---|---|
| `recall(query, period?)` | Searches facts (including archived and past ones, with their validity), episodes and the raw log; returns a short, dated list with sources |
| `calendar(range)` | Events in a range, from the calendar connector |
| `search_email(query)` | Searches mail through the connector; returns senders, subjects, dates, snippets |
| `remember(statement)` | The owner said "remember that ...": written at once as an owner-stated fact, confidence 1 |
| `forget(query)` | Proposes the matching facts for deletion; confirmed by voice or in the app |
| `delegate(goal)` | Starts a background task (section 6) |

With many tools, Spring AI 2.0's tool-search advisor (progressive disclosure of tool definitions) is worth measuring. For the voice path, a short fixed list is better: it keeps the tool block stable and cached.
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

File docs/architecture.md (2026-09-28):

# Architecture

## Principle: dumb device, smart computer

The robot collects, timestamps and forwards data, and it performs: eyes on the screen, sounds on the speaker. The computer does everything else: parsing, fusion, 3D modelling, language and the companion's behaviour. This keeps the firmware small and lets heavy processing run on a GPU.

```mermaid
flowchart TB
  subgraph Device["Marvin robot"]
    direction LR
    LID["D800 lidar<br/>≈ 21 600 pts/s"] -->|UART0 921600| FW
    LD2450["LD2450<br/>3 targets @ 10 Hz"] -->|UART1 256000| FW
    CAM["OV3660 camera"] -->|DVP| FW
    MIC["PDM mic"] -->|I2S0| FW
    FW -->|"I2S1"| SPK["MAX98357A + speaker"]
    FW["ESP32-S3 firmware<br/>timestamp + frame"]
    FW -->|"SPI"| LCD["1.69in screen<br/>eyes + mini-map"]
    MR60["MR60BHA2 kit<br/>ESP32-C6"]
  end
  FW -->|"UDP: lidar + radar frames"| HOST
  FW -->|"HTTP MJPEG stream"| HOST
  HOST -->|"expressions + speech"| FW
  MR60 -->|"Wi-Fi: vitals"| HOST
  subgraph HOST["Computer"]
    direction LR
    RX["Receivers"] --> SYNC["Time alignment"] --> FUSE["Fusion<br/>(extrinsics)"] --> VIEW["Live viewer (Rerun)"]
    FUSE --> BRAIN["Companion brain<br/>(events, local LLM)"]
  end
```

## Data rates

| Stream | Rate | Bandwidth |
|---|---|---|
| Lidar point packets, D800 (12 points each) | ≈ 1 800 packets/s × 47 bytes | ≈ 85 kB/s |
| Lidar point packets, D500 | ≈ 420 packets/s × 47 bytes | ≈ 20 kB/s |
| Microphone, 16 kHz 16-bit mono (when streamed) | — | 32 kB/s |
| LD2450 target frames | 10 Hz × 30 bytes | < 1 kB/s |
| Camera, MJPEG VGA | ≈ 10–15 fps | ≈ 300–600 kB/s |
| MR60BHA2 vitals | ≈ 1 Hz | negligible |

Everything fits comfortably in the ESP32-S3's Wi-Fi throughput.

## Design decisions

| Decision | Why | Alternative considered |
|---|---|---|
| **The MR60BHA2 stays a separate Wi-Fi node** | The kit ships with its own ESP32-C6 and firmware. Routing its data through the S3 would mean opening the case and soldering. Vital signs update at about 1 Hz, so timestamping them on arrival at the PC is precise enough. | UART link through the kit's Grove port (possible later) |
| **Power through the XIAO's USB-C port** | The 5V pin is tied directly to VBUS, so the ESP32 becomes the power distribution point with no extra board. | Separate USB-C breakout with 5.1 kΩ resistors and a soldered distribution board (rev A) |
| **WAGO lever connectors** | Solderless, reliable and reusable. | Soldered perfboard |
| **An upright robot, sensors tilted inside** | To measure heart rate at a desk, the 60 GHz radar must aim at a seated chest, about 20° up. Tilting the whole object (rev E and the early robot sketches) made it look like it was falling backwards. Keeping the shell vertical and tilting the sensors on an internal sled gives the same aim with a calm silhouette. | Tilted face panel (robot v1–v2), lighthouse taper (rev E) |
| **Radars behind a flat, uniform wall** | No holes in front of the radars keeps the design clean. A 1.6 mm PETG wall is half a wavelength at 60 GHz; seen at 20° incidence it is only about 3 % thicker electrically, which costs almost nothing. The anthracite band is a colour change, not a thickness change. | Open radar windows (rev A–D) |
| **Head and body decoupled by a TPU damper** | The radar measures sub-millimetre chest motion; the lidar motor spins at 10 Hz on top of the head. The damper keeps that vibration out of the body. | Rigid neck |
| **Screen vertical, camera tilted** | An IPS screen reads fine from 20° below, but a camera with a ~65° field of view at desk height would frame your chest. Tilting the XIAO by 20° centres your face. | Tilting the whole face |
| **Smoked acrylic face window** | Gives the black-glass look while letting the screen through; printed black PETG would be opaque. | Open screen cut-out with a bezel |
| **Grown-up design language** | The companion is for adults: warm grey, anthracite, one orange knob. Personality comes from the eyes and behaviour, not from decoration. | Cute toy styling (robot v2) |
| **Screen as the face, eyes by default** | A face makes the device readable at a glance: awake, listening, sleepy. The mini-map is still one tap away. | Back screen with a mini-map (rev C–D) |
| **Thread-forming screws into PETG and PLA** | No heat-set inserts and no nuts, except the optional tripod nut. | Brass inserts (rev A) |
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

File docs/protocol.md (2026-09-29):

# Robot ↔ host protocol (v1)

The robot streams its sensors to the host over **UDP** on the local network. Each datagram carries one message: a 16-byte header, then a payload. All integers are little-endian.

Reference implementations: [`host/marvin_host/protocol.py`](../host/marvin_host/protocol.py) and [`firmware/src/protocol.h`](../firmware/src/protocol.h).
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

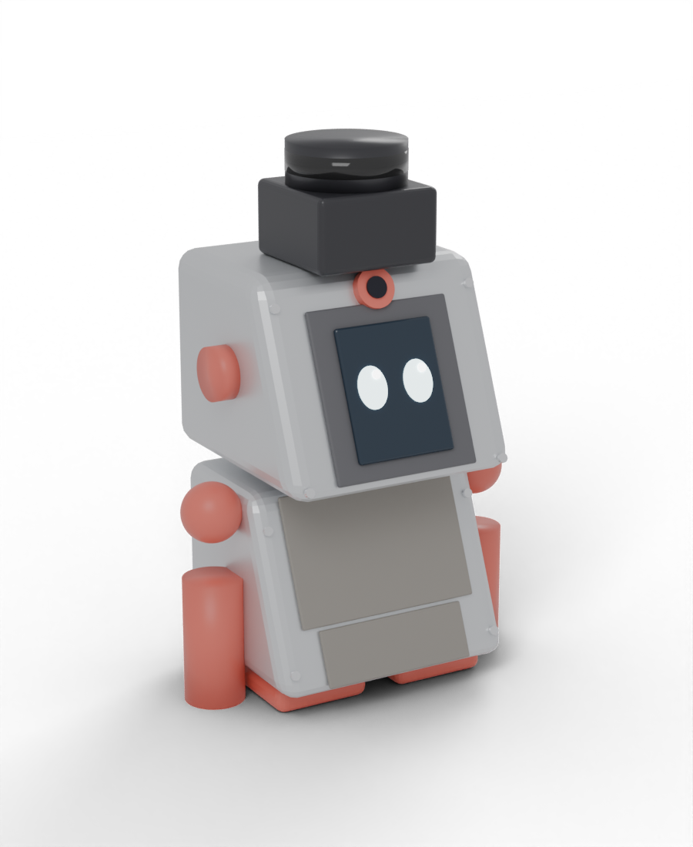
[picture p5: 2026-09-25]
docs/concepts/concept_E_robot.png

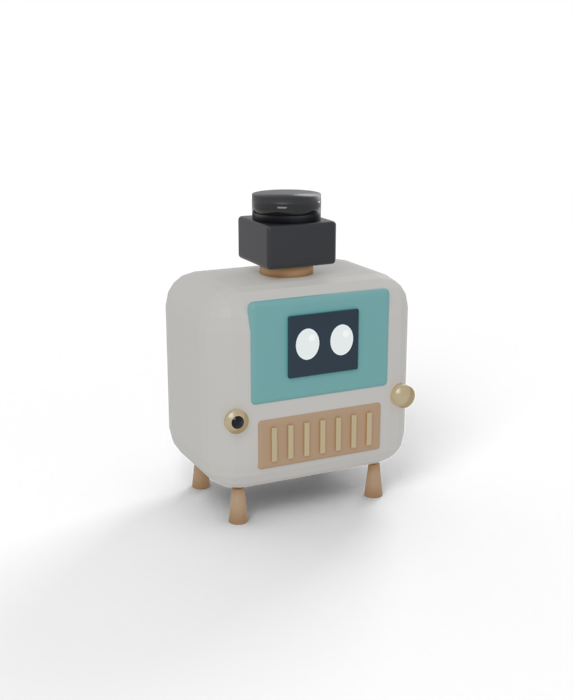
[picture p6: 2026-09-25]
docs/concepts/concept_C_tito.png

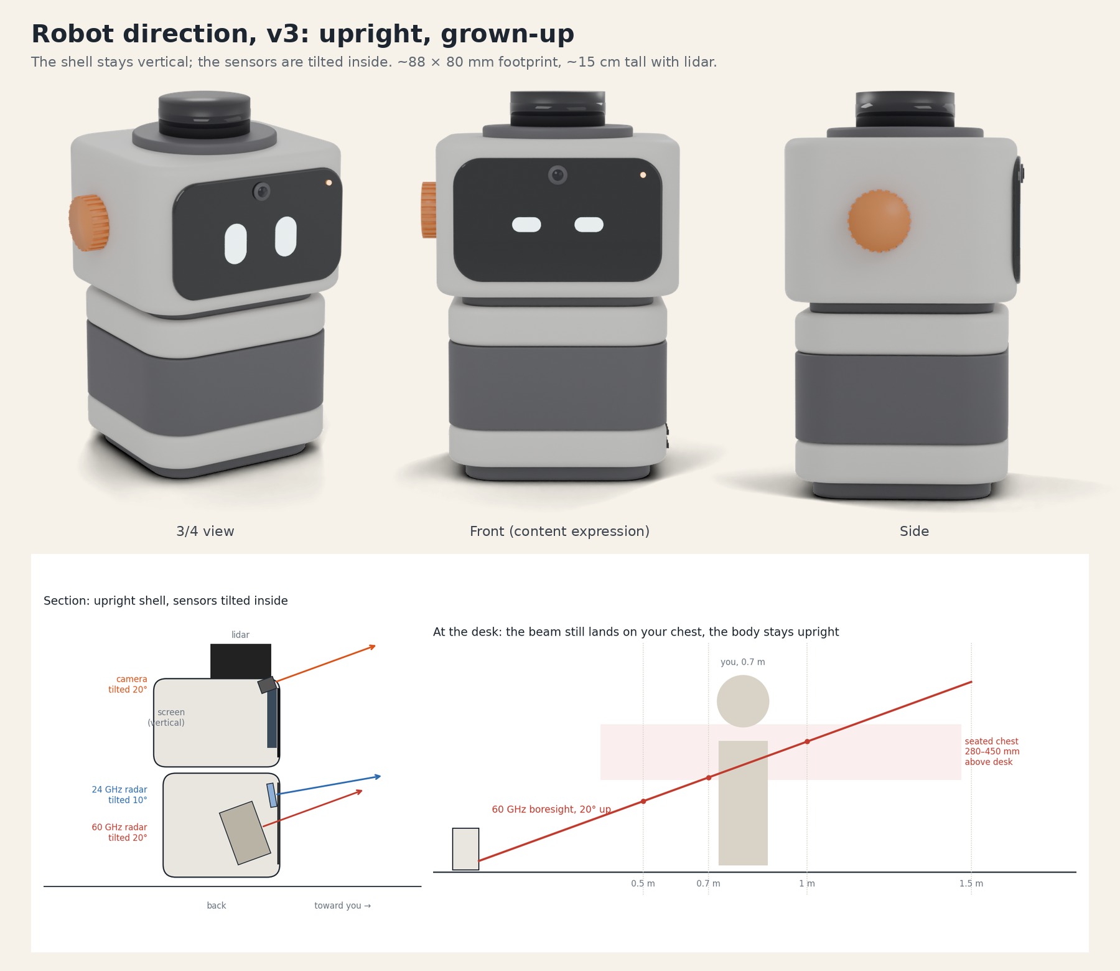
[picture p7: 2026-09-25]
docs/concepts/robot_v3_board.jpg

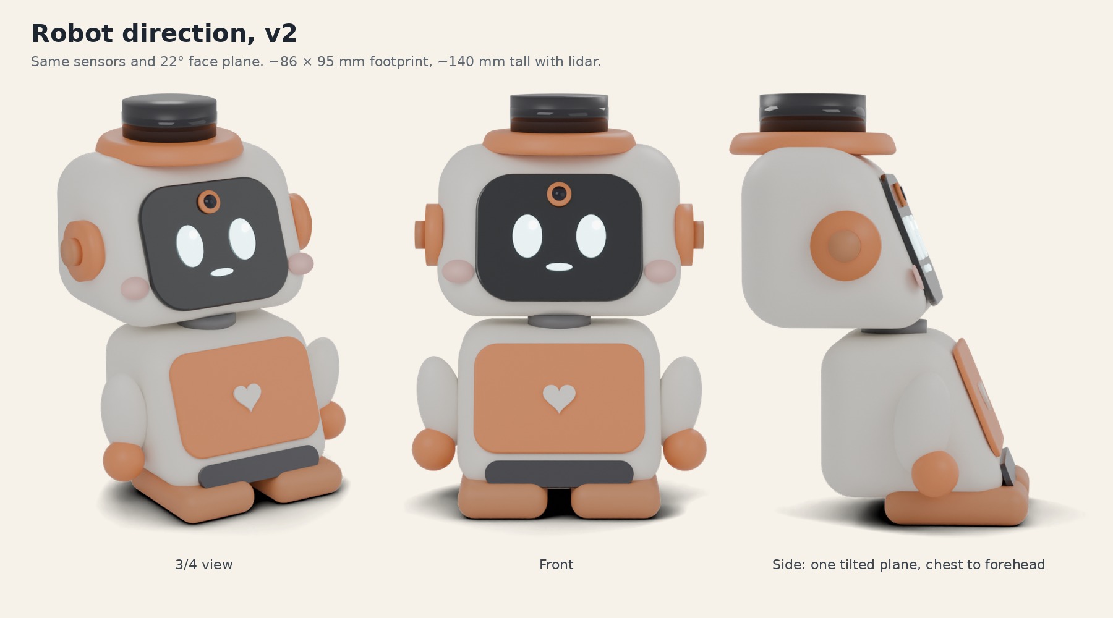
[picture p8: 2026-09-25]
docs/concepts/robot_v2_board.jpg

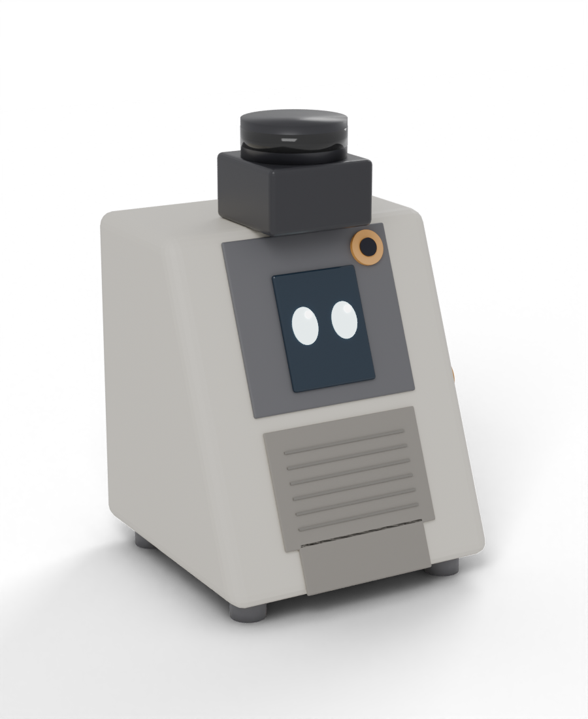
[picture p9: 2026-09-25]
docs/concepts/concept_D_terminal.png

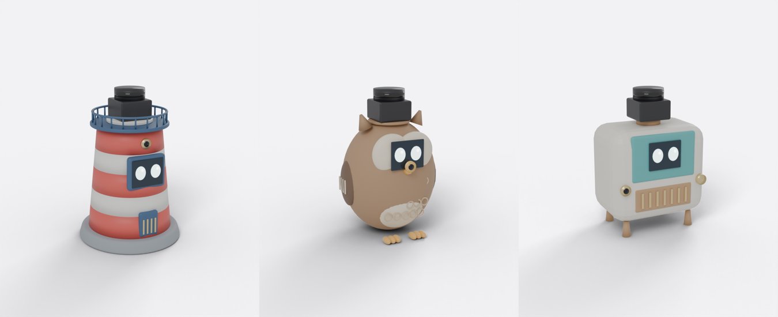
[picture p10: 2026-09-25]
docs/concepts/concepts_board.jpg

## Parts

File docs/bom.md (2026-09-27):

# Bill of materials

Prices are indicative. They were checked in September 2026 and move often. Pick the best-rated listing rather than the cheapest one, and allow 2–4 weeks for delivery.

**Total: about €230 in parts with the D800 lidar, or about €190 with the D500** (prices checked 26 September 2026, before import fees, see below), in one AliExpress order. Seeed Studio's own shop (Germany warehouse) can be cheaper for the MR60BHA2 kit and the XIAO ESP32S3 Sense when they are in stock there. You provide the USB-C power source: a phone charger or a power bank.

Rev F (the upright robot) uses exactly the same electronics as rev D and rev E. It only adds a smoked acrylic face window and a little TPU for the vibration damper.

## Sensors and controller

| Part | Qty | Purpose | ≈ € |
|---|---:|---|---:|
| [Seeed XIAO ESP32S3 Sense](https://fr.aliexpress.com/item/1005006988111963.html) (official Seeed store on AliExpress, variant "1pc", +€5.44 shipping) | 1 | Controller, camera (OV3660), **built-in PDM microphone** and Wi-Fi. It sits in the head, tilted 20° so the camera sees your face. Ships with loose header pins to solder; the [pre-soldered version](https://www.seeedstudio.com/Seeed-Studio-XIAO-ESP32S3-Sense-Pre-Soldered-p-6335.html) avoids that step. | 22 |
| [LDROBOT **D800** lidar kit (STL-27L)](https://fr.aliexpress.com/item/1005010728254952.html), variant "D800 lidar" | 1 | Reference lidar: 360°, 25 m, 21 600 points/s, UART at 921 600 baud. It sits on top of the head. Its footprint (54 × 46.29 mm) matches the LD19 family; check it on the printed template. | 111 |
| *Cheaper option:* same listing, variant "D500 lidar kit" (STL-19P) | — | 12 m, 5 000 points/s, UART at 230 400 baud, same footprint and connector. | 68 |
| [Hi-Link HLK-LD2450, KIT-A](https://fr.aliexpress.com/item/1005007316768708.html) (official Hi-Link store) | 1 | 24 GHz radar, tracks up to 3 people. Behind the body band, tilted 10°. KIT-A ships with its cable. | 8 |
| [Seeed MR60BHA2 kit with XIAO ESP32C6](https://fr.aliexpress.com/item/1005008715574827.html) (Elshare store on AliExpress, variant "MR60BHA2 Sensor", free shipping) | 1 | 60 GHz radar for breathing and heart rate. Behind the body band, on a sled tilted 20° towards the chest of a seated person. It has its own ESP32-C6 and sends data over Wi-Fi. Kept in Seeed's 54 × 35 × 22 mm case, printed from [Seeed's published files](https://www.printables.com/model/1326287-3d-print-enclosure-for-xiao-60ghz-mmwave-sensors-m). | 47 |
| [1.69" IPS LCD module, 240×280, ST7789](https://fr.aliexpress.com/item/1005007987731480.html), variant "1.69 Inch" | 1 | The face: expressive eyes behind the smoked window, and a mini-map or status on demand. Generic SPI module (the Waveshare one works too, for €15). Measure its board and mounting holes before printing the head frame. | 3 |
| *Optional upgrade:* 2.0" ST7789 LCD, 240×320 | — | Same driver and wiring, fills more of the face window. Change `lcd*` in the CAD if you use it. | 7 |

## Audio

| Part | Qty | Purpose | ≈ € |
|---|---:|---|---:|
| [MAX98357A I2S amplifier module](https://fr.aliexpress.com/w/wholesale-max98357a.html) | 1 | 3 W class-D mono amp, driven digitally over I2S by three ESP32 pins. Most boards ship with a loose header and a screw terminal. | 2 |
| [2030 cavity speaker, 8 Ω 1 W](https://fr.aliexpress.com/w/wholesale-2030-speaker-8ohm-1w.html) | 1 | 20 × 30 mm speaker in its own small box, behind the dot grille on the right side of the body. | 2 |

The microphone is already on the XIAO Sense board: nothing to buy.

## Wires and connectors

| Part | Qty | Purpose | ≈ € |
|---|---:|---|---:|
| [JST-ZH 1.5 mm 4-pin → Dupont female cables](https://fr.aliexpress.com/item/1005005840702851.html), variant "ZH1.5 to Dupont / 4Pin 10 pieces" | 1 pack | Lidar to ESP32. | 5 |
| [Dupont jumper wires, female–female, 20 cm](https://fr.aliexpress.com/item/1005012095727159.html) | 1 lot | ESP32 power pins to the lever connectors, the amp's I2S lines, and the runs through the neck. | 2 |
| [5-port lever connectors, 221-415 type](https://fr.aliexpress.com/item/1005007171193407.html), variant "10pcs-415-Bag" | 1 bag of 10 | Four buses: 5 V, GND-A, GND-B, 3V3 (0.15–4 mm² wire). No tools needed. | 3 |
| [USB-C male pigtail, 2 wires, 90° plug](https://fr.aliexpress.com/item/1005010089226136.html) | 1 | Powers the MR60BHA2 kit from the 5 V bus; the right-angle plug fits under the kit. | 2 |
| [USB-C cable with a **90° (right-angle) plug**](https://fr.aliexpress.com/item/1005008765247136.html), single elbow, 1 m | 1 | Enters at the back of the body and climbs through the neck to the XIAO in the head. The other end goes to a charger, a power bank or your computer (for flashing). | 3 |

## Enclosure extras

| Part | Qty | Purpose | ≈ € |
|---|---:|---|---:|
| [Tinted acrylic sheet, 10 × 20 cm, 2.3 mm](https://fr.aliexpress.com/item/1005006782700043.html), variant "Transparent Black" | 1 | The black-glass face window, about 74 × 44 mm (the CAD uses 2.3 mm). Cut with a fine saw or score-and-snap, then file the corners round. Black PETG would hide the screen. | 5 |
| [TPU filament 95A, 200 g](https://fr.aliexpress.com/item/1005008589285483.html), variant "Black 200g" | ~15 g used | The neck gasket, the four grommets between head and body, and the feet. It keeps the lidar motor's vibration away from the 60 GHz radar. Print it on the A1 outside the AMS. | 13 |
| M2.5×10 screws | 3 | Lidar on top of the head. They thread-form into the plastic: no nuts. | from your kit |
| M3 screws | 2 × M3×12, 4 × M3×10 button head, 4 × M3×14 + 4 washers | Plinth to sled, body back wall to sled, neck (through the TPU grommets into the head floor). They thread-form into the plastic: no nuts. See [assembly](assembly.md#screws). | from your kit |
| [3 mm double-sided foam strips](https://fr.aliexpress.com/item/1005008290401897.html), variant "Square 20X150mm 5pcs" | 1 | Cut into pads that hold both radars on the sled, and the lever connectors, amp and speaker. | 2 |

## Tools

| Tool | Needed? | ≈ € |
|---|---|---:|
| [Automatic wire stripper](https://fr.aliexpress.com/item/1005007540063503.html) | Yes | 8 |
| Soldering iron and [0.6 mm solder](https://fr.aliexpress.com/item/1005005618101831.html) | Yes, for the two header strips. | 4 (solder) |
| Small Phillips/hex screwdriver | Yes | — |
| Fine saw or cutter, file | Yes, for the acrylic window | — |
| [Multimeter (ANENG SZ308)](https://fr.aliexpress.com/item/1005007097120431.html) | Recommended, to check the buses before plugging modules in | 6 |

## Power requirements

- USB-C, 5 V, **at least 2 A**. Any phone charger or modern power bank qualifies.
- At about 1 A average draw, a 10 000 mAh power bank lasts roughly 5 hours. On a desk, a wall charger is simpler.
- To flash the firmware, plug the same cable into your computer instead. Never connect both at once.

## Import fees

AliExpress splits the cart into one order per seller, and since July 2026 each parcel entering the EU pays a small flat import fee (about €1–4, shown only after checkout in each order's details). Ordered from about 15 sellers, the parts above add **roughly €40 of import fees** to the cart total. Buying several items from the same seller keeps it down.

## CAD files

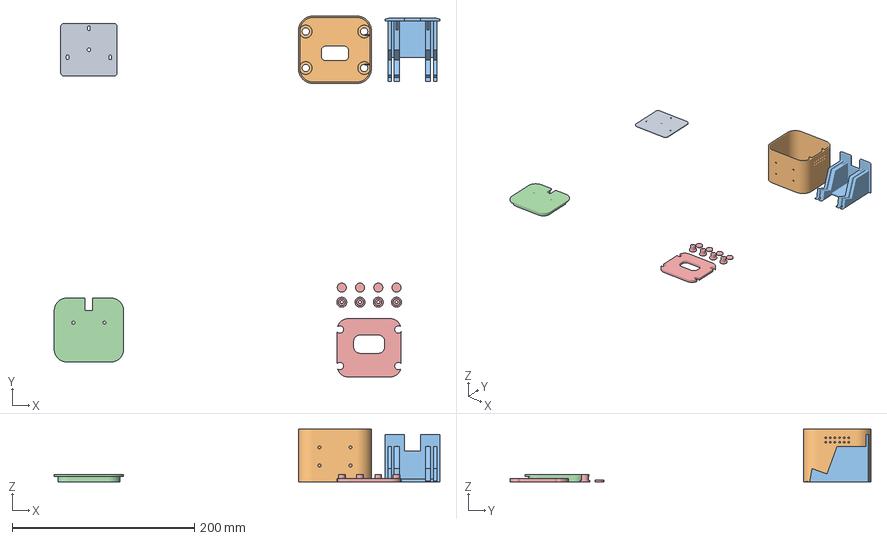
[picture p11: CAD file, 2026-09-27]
hardware/bambu/marvin_A1.3mf
422.8 x 395.7 x 58.0 mm
Lidar template
Sensor sled
Plinth
TPU neck, grommets and feet

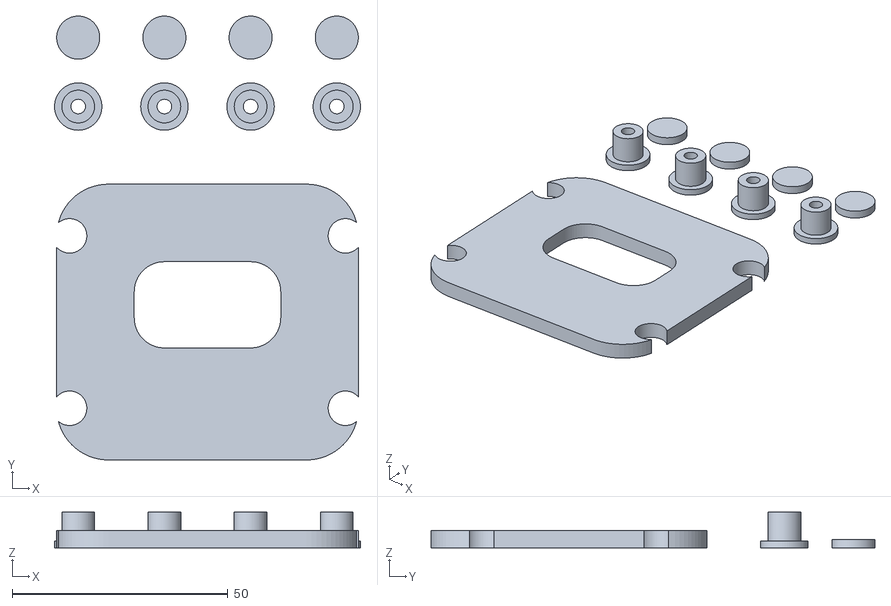
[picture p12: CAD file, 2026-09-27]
hardware/stl/4_tpu_neck_grommets_feet.stl
71.0 x 103.0 x 8.30

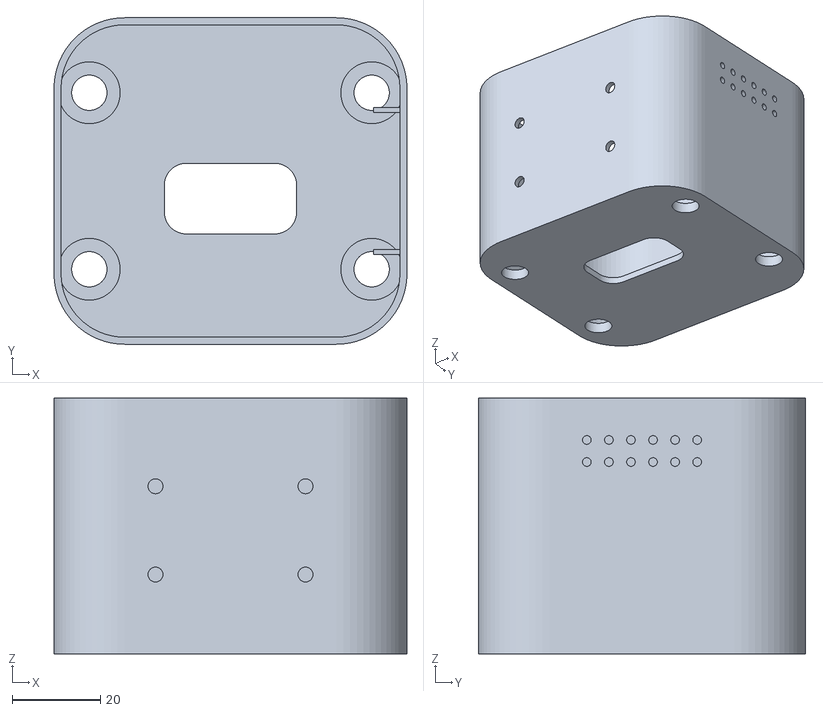
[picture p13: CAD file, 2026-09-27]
hardware/stl/1_body.stl
80.0 x 74.0 x 58.0

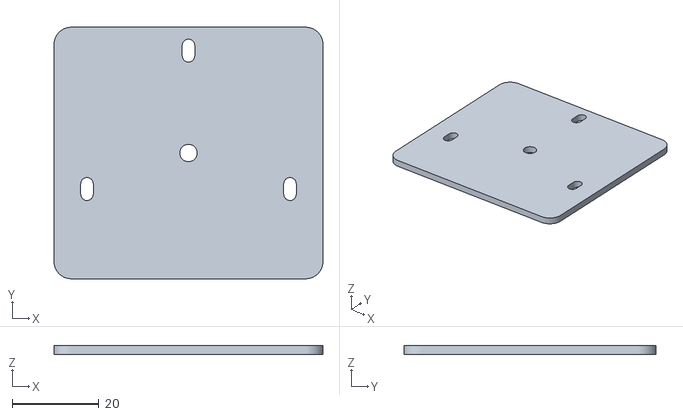
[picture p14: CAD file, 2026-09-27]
hardware/stl/0_lidar_template.stl
62.0 x 58.0 x 2.00

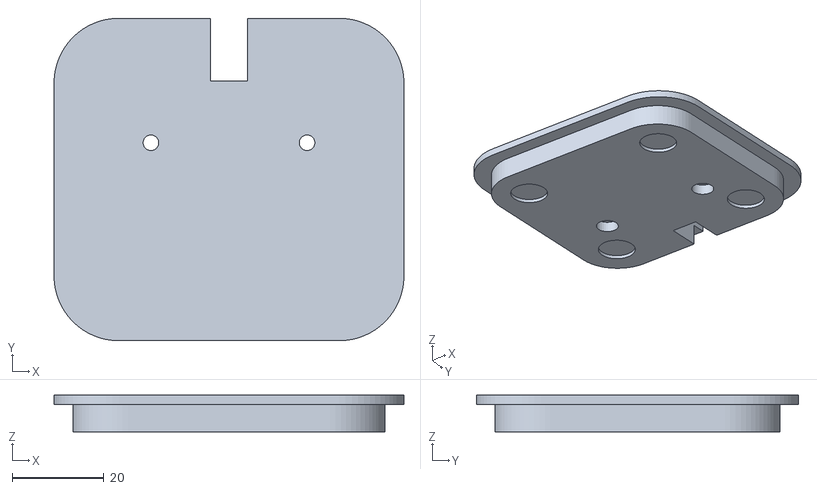
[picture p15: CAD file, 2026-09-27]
hardware/stl/2_plinth.stl
76.2 x 70.2 x 8.00

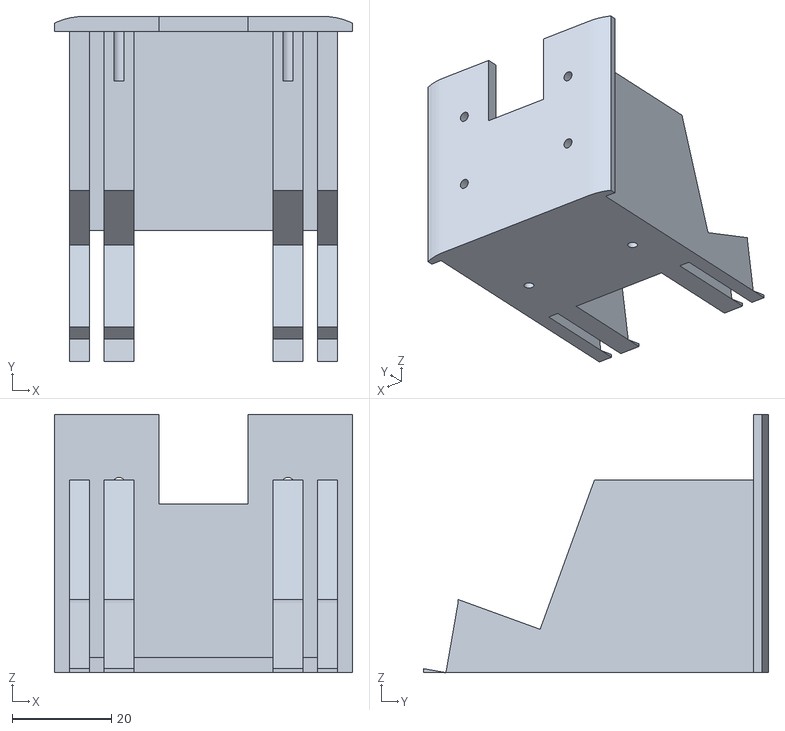
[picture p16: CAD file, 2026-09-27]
hardware/stl/3_sensor_sled.stl
60.0 x 69.5 x 52.0

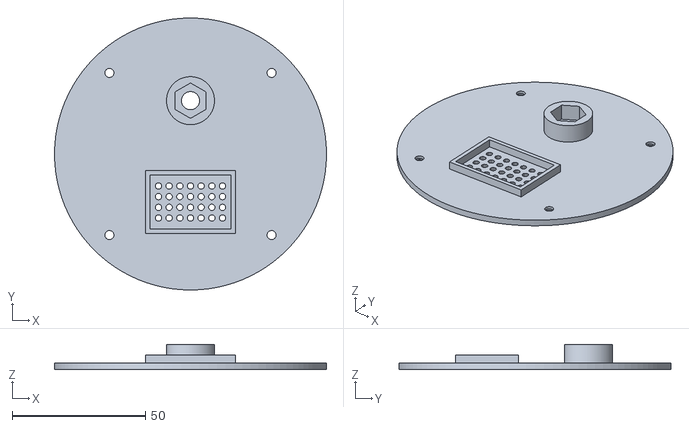
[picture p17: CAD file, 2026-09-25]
hardware/stl/2_bottom_plate.stl
102.0 x 102.0 x 9.40

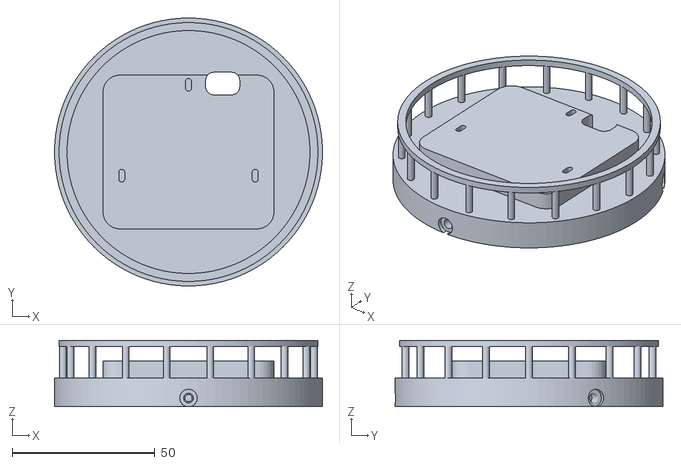
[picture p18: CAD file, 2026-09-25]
hardware/stl/5_gallery_cap.stl
94.0 x 94.0 x 23.2

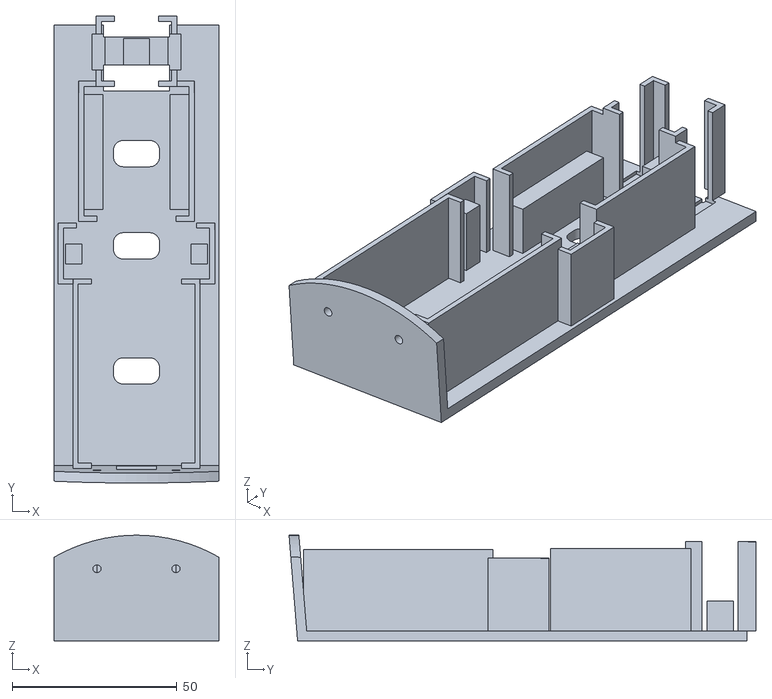
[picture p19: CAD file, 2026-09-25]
hardware/stl/4_spine.stl
50.0 x 141.8 x 32.1

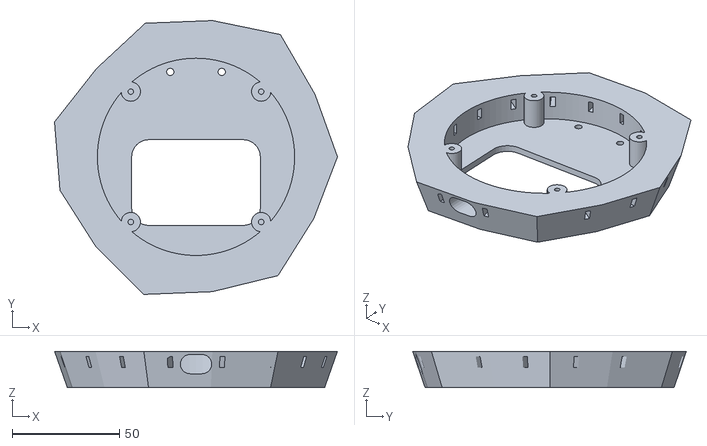
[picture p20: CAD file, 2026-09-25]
hardware/stl/1_base_island.stl
132.0 x 127.7 x 17.0

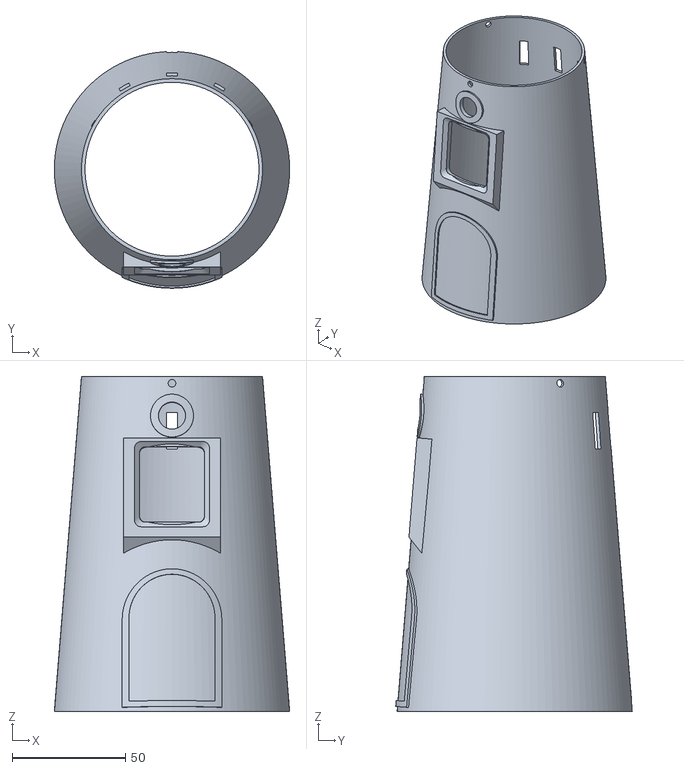
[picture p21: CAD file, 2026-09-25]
hardware/stl/3_tower_shell.stl
104.0 x 104.5 x 148.0

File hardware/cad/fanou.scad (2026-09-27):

// =====================================================================
//  FANOU - the little lighthouse (Marvin rev E)
//  A desk companion: the lidar is the lamp turning at the top, the
//  screen is its face, the radars sleep behind the painted bands.
//
//  Parametric OpenSCAD source. Units: mm.
//  Frame: X = right, Y = front (-) to back (+), Z = up. Tower axis = Z.
//
//  PART = "base" | "bottom" | "shell" | "spine" | "cap" | "template"   (assembly frame)
//         "print_base" | "print_bottom" | "print_shell" | "print_spine" | "print_cap"
//         "assembly" | "exploded" | "section"
//
//  SPDX-License-Identifier: CERN-OHL-P-2.0
// =====================================================================

PART = "assembly";
$fn = 96;
eps = 0.01;

// ---------------- Tower -------------------------------------------------
zb  = 22;        // tower bottom = top face of the base
zt  = 170;       // tower top = underside of the gallery
Rb  = 52;        // outer radius at the bottom
Rt  = 40;        // outer radius at the top
ws  = 1.6;       // shell wall: half a wavelength at 60 GHz in PETG, so it acts as a radome
k   = (Rb - Rt) / (zt - zb);
a   = atan(k);   // taper angle: every front module leans back by it and looks slightly up
function r(z) = Rb - k * (z - zb);

// Face plane: the front of every module, parallel to the wall and "gap" behind it
gap = 0.8;
y0  = -(Rb - ws - gap);
module F() { translate([0, y0, zb]) rotate([-a, 0, 0]) children(); }
// F frame: x = right, y = depth (backwards), z = height measured along the face
function Fy(w, u) = y0 + w * cos(a) + u * sin(a);
function Fz(w, u) = zb - w * sin(a) + u * cos(a);
// A flat module in a round tower must sit back so its corners clear the wall.
// sb(h, u) = depth of the module front for a half-width h whose top is at height u.
function Rin(u) = r(Fz(0, u)) - ws - 0.3;
function sb(h, u) = ceil((Rin(u) + 0.3 - gap - sqrt(Rin(u)*Rin(u) - h*h)) * 10) / 10;

// ---------------- Fits / fasteners ---------------------------------------
clr     = 0.4;
colFoam = 3.0;                     // 3 mm double-sided foam pads hold the modules
m3_clear = 3.4; m3_pilot = 2.6; m25_pilot = 2.1;
tripod_nut_af = 11.5; tripod_nut_h = 6.0;

// ---------------- Modules (face-frame heights) -----------------------------
kitW = 35; kitH = 54; kitD = 22; kitU = 6;       // MR60BHA2 in its Seeed case, portrait
ldW = 44;  ldH = 15;  ldT = 1.6; ldU = 62;       // HLK-LD2450 behind the red band
lcdW = 31.5; lcdH = 39; lcdT = 4.5; lcdStand = 4.0; lcdU = 81;  // Waveshare 1.69", portrait like a window
lcdWinW = 28.8; lcdWinH = 33.4;                  // opening for the 27.97 x 32.63 active area
lcdSx = 13.25;                                   // standoff columns (pads are wide)
xW = 21; xH = 17.8; xD = 15; xU = 122;           // XIAO ESP32S3 Sense, lens forward
camD = 12;
g = 1.6 + clr/2;                                  // guide thickness beyond the module edge
kitS = sb(kitW/2 + g, kitU + kitH);
ldS  = sb(ldW/2 + g, ldU + ldH);
lcdS = sb(lcdW/2 + g, lcdU + lcdH);
xS   = sb(xW/2 + g, xU + xH);
echo(setbacks = [kitS, ldS, lcdS, xS]);

// Spine: tilted plate behind all modules
spD = kitS + kitD + 2.8;
spT = 3; spW = 50; spTopU = 139;

// ---------------- Lidar (D800 / D500, LD19 footprint) ---------------------
lidPairDY = 8.3; lidSingleDY = -23.6; slot = 1.2; lidY = 0;

// ---------------- Cap (gallery + lantern plinth) --------------------------
galR = Rt + 7; galT = 4; capDn = 6;              // floor from zt-capDn to zt+galT
plinthH = 6;
railR = galR - 3; railH = 13; nPosts = 18;

// ---------------- Base (rocky island) ------------------------------------
baseR = 66; baseRt = 60; baseZ0 = 5; cavR = 46;
spkL = 30.4; spkH = 20.4; spkT = 5;

// =====================================================================
module rrect(w, d, r, h) {
    hull() for (x=[-w/2+r, w/2-r], y=[-d/2+r, d/2-r]) translate([x,y,0]) cylinder(r=r, h=h, $fn=32);
}
module slotY(d, len, h) { hull() for (s=[-len, len]) translate([0,s,0]) cylinder(d=d, h=h, $fn=24); }
module lidarHoles() {
    for (x=[-23.4, 23.4]) translate([x, lidY - lidPairDY, 0]) children();
    translate([0, lidY - lidSingleDY, 0]) children();
}
rockJ = [1.00,0.94,1.02,0.96,1.04,0.95,0.99,1.03,0.94,1.01,0.97,1.05,0.95];
rockPts = [for (i=[0:12]) [cos(i*360/13)*rockJ[i], sin(i*360/13)*rockJ[i]]];
module rock(h, r0, r1) { linear_extrude(height=h, scale=r1/r0) scale([r0, r0]) polygon(rockPts); }

// thin layer hugging the outside of the tower, used to make reliefs
module skin(t) {
    difference() {
        translate([0,0,zb]) cylinder(r1=Rb+t, r2=Rt+t, h=zt-zb);
        translate([0,0,zb-1]) cylinder(r1=Rb-0.3, r2=Rt-0.3, h=zt-zb+2);
    }
}
// shapes projected forward through the wall (in the F frame, facing -y)
module throughF(u) { F() translate([0, 30, u]) rotate([90,0,0]) linear_extrude(60) children(); }
module arch(w, h) { translate([-w/2, -h]) square([w, h - w/2]); translate([0, -w/2]) circle(d=w); }

// =====================================================================
// SHELL - the striped tower (print upright; colour changes by layer)
module shell() {
    difference() {
        translate([0,0,zb]) cylinder(r1=Rb, r2=Rt, h=zt-zb);
        translate([0,0,zb-eps]) cylinder(r1=Rb-ws, r2=Rt-ws, h=zt-zb+2*eps);
        throughF(lcdU + lcdH/2) offset(r=3) offset(delta=-3) square([lcdWinW, lcdWinH], center=true);   // face
        throughF(xU + xH/2) circle(d=camD);                                                              // camera porthole
        for (ang=[150, 180, 210]) rotate([0,0,ang-90]) translate([r(146), 0, 146]) cube([10, 5, 16], center=true);  // back windows = vents
        for (ang=[0, 120, 240]) rotate([0,0,ang-90]) translate([r(zt-3), 0, zt-3]) rotate([0,90,0]) cylinder(d=m3_clear, h=10, center=true, $fn=24);  // cap screws
        translate([-2.5, Rb-ws-1.5, zb-eps]) cube([5, 4, 4]);                                           // key notch
    }
    // face plaque: flat inside for the screen, chamfered underneath so it prints without supports
    difference() {
        intersection() {
            F() hull() {
                translate([-(lcdWinW/2 + 7), -(gap + ws + 1.0), lcdU - 4]) cube([lcdWinW + 14, 0.01, lcdH + 5]);
                translate([-(lcdWinW/2 + 7), lcdS - 0.4, lcdU - 4 - (lcdS + gap + ws + 1)]) cube([lcdWinW + 14, 0.01, lcdH + 5 + (lcdS + gap + ws + 1)]);
            }
            translate([0,0,zb]) cylinder(r1=Rb+20, r2=Rt+20, h=zt-zb);
        }
        translate([0,0,zb-0.01]) cylinder(r1=Rb-ws+0.01, r2=Rt-ws+0.01, h=zt-zb+0.02);   // outside only: nothing inside the tower
        throughF(lcdU + lcdH/2) offset(r=3) offset(delta=-3) square([lcdWinW, lcdWinH], center=true);
        F() translate([0, -(gap + ws + 1.0) - 0.01, lcdU + lcdH/2]) rotate([-90,0,0]) linear_extrude(2.2, scale=[lcdWinW/(lcdWinW+4.4), lcdWinH/(lcdWinH+4.4)]) offset(r=3) offset(delta=-3) square([lcdWinW + 4.4, lcdWinH + 4.4], center=true);
    }
    // reliefs: arched door around the 60 GHz radar, face frame, brass porthole ring
    intersection() { skin(0.8); throughF(kitU + kitH + 3) difference() { arch(kitW + 9, kitH + 7); translate([0, -2.4]) arch(kitW + 3, kitH + 2); } }
    intersection() { skin(1.0); throughF(xU + xH/2) difference() { circle(d=camD + 7); circle(d=camD); } }
}
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

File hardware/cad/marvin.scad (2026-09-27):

// =====================================================================
//  MARVIN - open-source desk companion, rev F (the upright robot)
//
//  Parametric OpenSCAD source. Units: mm. OpenSCAD >= 2021.01.
//  Frame: X = right, Y = back (+) / front (-, toward the user), Z = up.
//  Z = 0 is the desk. The robot stands upright; the sensors are tilted
//  inside it, not the body.
//
//  This file covers the body half of the robot (everything below the neck).
//  The head (face frame, acrylic window, XIAO cradle, lidar ring, knob)
//  follows once the 1.69" screen is measured; its interface with the body
//  is fixed here (neck bolt pattern, cable hole).
//
//  PART = "assembly" | "exploded" | "section"                (views)
//         "body" | "plinth" | "sled" | "neck" | "grommet" | "foot" | "template"   (assembly frame)
//         "ghost_mr60" | "ghost_ld2450" | "ghost_speaker"   (modules, for the Blender model)
//         "print_body" | "print_plinth" | "print_sled" | "print_tpu" | "print_template"
//
//  SPDX-License-Identifier: CERN-OHL-P-2.0
// =====================================================================

PART = "assembly";
$fn = 64;
eps = 0.01;

// ---------------- Outer shape -------------------------------------------
bodyW = 80;  bodyD = 74;  bodyR = 16;     // body footprint (squircle), a little narrower than the head
bodyZ0 = 6;  bodyZ1 = 64;                 // body bottom / top (the plinth hides below bodyZ0)
wall = 1.6;                               // half a wavelength at 60 GHz in PETG: the front wall is a radome
deck = 2.0;                               // roof of the body, under the neck
headW = 88;  headD = 80;  headR = 16;     // head footprint (for the ghost and the bolt pattern)
headZ0 = 68; headZ1 = 124;
neckH = headZ0 - bodyZ1;                  // 4 mm TPU gasket between body and head

// Anthracite band: a filament change by layer (cosmetic only; any colour is RF-transparent)
bandZ0 = 20; bandZ1 = 50;

plinthW = 68; plinthD = 62; plinthR = 12; // recessed foot, reads as a shadow line
floorT = 2.0;                             // plinth plate that closes the body from below
floorZ = bodyZ0 + floorT;                 // = 8, everything inside stands on it

// ---------------- Fits and fasteners -------------------------------------
clr = 0.3;
m3_clear = 3.4; m3_pilot = 2.6; m3_head = 6.2; m25_pilot = 2.1;
foam = 3.0;                               // double-sided foam pads under every module

// ---------------- Inside the body ------------------------------------------
inW = bodyW - 2*wall;  inD = bodyD - 2*wall;  inR = bodyR - wall;
yWall  = -inD/2;                          // inner face of the front wall
yFront = yWall + 1.0;                     // module fronts stand 1 mm behind the wall

// 24 GHz radar HLK-LD2450: low, tilted 10 deg up. It sits BELOW the 60 GHz radar so it never
// shadows the 60 GHz beam, which leaves the robot upwards.
ldW = 44; ldH = 15; ldT = 1.6; ldTilt = 10;
ldZ = floorZ + 1.0;                       // bottom edge of the board (rests on a 1 mm lip)

// 60 GHz radar MR60BHA2 kit in Seeed's 54 x 35 x 22 case, landscape, tilted 20 deg up
kitW = 54; kitH = 35; kitD = 22; kitTilt = 20;
kitZ = ldZ + ldH*cos(ldTilt) + 1.5;       // bottom front edge of the case, just above the LD2450

// Sled: four ribs (they carry both radars), a foot and a back plate for the lever connectors and the amp
ribX  = [[14, 20], [23, 27]];             // |x| ranges of the inner and outer ribs
bpT = 3;  bpW = 60;                       // back plate
yBP = inD/2 - clr - bpT;                  // front face of the back plate
sledTop = bodyZ1 - deck - 2;              // 2 mm under the deck
screwX = 17;                              // plinth screws (from below) and back-wall screws (from behind) go into the inner ribs
plinthScrewY = 8;
backScrewZ = [26, 46];

// Speaker 2030 (20 x 30 x 5) glued inside the right wall behind a dot grille
spkY = 0; spkZ = 18; spkL = 30.4; spkH = 20.4;

// Neck: 4 x M3 through TPU grommets. The screws go up into the head floor, so no rigid path
// links the head (lidar motor) to the body (heart-rate radar).
neckBolt = [[-32, -20], [32, -20], [-32, 20], [32, 20]];
gromOD = 7.6; gromFlange = 11; gromFlangeT = 1.6; gromBore = m3_clear;
bossT = 1.2;                              // flat seat for the grommet flange under the deck
cableHole = [30, 16, 5];                  // w, d, corner r; the 90 deg USB-C plug passes through it
cableHoleY = 4;

// Lidar (D800 / D500, LD19 footprint): used by the template now and by the head later
lidPairDY = 8.3; lidSingleDY = -23.6; lidHalfX = 23.4; slot = 1.2; lidY = 0;

// =====================================================================
// Helpers
function rot(v, a) = [v[0]*cos(a) - v[1]*sin(a), v[0]*sin(a) + v[1]*cos(a)];
function add(a, b) = [a[0]+b[0], a[1]+b[1]];
function mul(v, k) = [v[0]*k, v[1]*k];

module squircle(w, d, r) { offset(r=r) square([w - 2*r, d - 2*r], center=true); }
module sqblock(w, d, r, z0, h) { translate([0, 0, z0]) linear_extrude(h) squircle(w, d, r); }
module rrect(w, d, r, h) { linear_extrude(h) offset(r=r) square([w - 2*r, d - 2*r], center=true); }
module slotY(d, len, h) { hull() for (s=[-len, len]) translate([0, s, 0]) cylinder(d=d, h=h, $fn=24); }
module lidarHoles() {
    for (x=[-lidHalfX, lidHalfX]) translate([x, lidY - lidPairDY, 0]) children();
    translate([0, lidY - lidSingleDY, 0]) children();
}
// a 2-D profile drawn in the (y, z) side plane, extruded along X from x0 to x1
module sideExtrude(x0, x1) { translate([x0, 0, 0]) rotate([90, 0, 90]) linear_extrude(x1 - x0) children(); }

// ---------------- Radar geometry in the side plane (y, z) --------------------
// "up" follows the front face of a module tilted by t; "in" goes from its front face into the robot
function upV(t) = [sin(t), cos(t)];
function inV(t) = [cos(t), -sin(t)];
L0 = [yFront, ldZ];                                         // LD2450 front, bottom edge
K0 = [yFront, kitZ];                                        // MR60 case front, bottom edge
kitCentre = add(K0, mul(upV(kitTilt), kitH/2));
ldCentre  = add(L0, mul(upV(ldTilt), ldH/2));
echo(str("MR60BHA2 face centre: y=", kitCentre[0], " z=", kitCentre[1], " | LD2450 face centre: y=", ldCentre[0], " z=", ldCentre[1]));

// Rib profile: lip under the LD2450, foam line behind it, ledge under the MR60 case,
// foam line behind the case, then straight back to the back plate.
function ribProfile() = let(
    sL0 = add(L0, mul(inV(ldTilt), ldT + foam)),            // LD2450 support line, bottom
    sL1 = add(sL0, mul(upV(ldTilt), ldH - 1)),               // ... top
    ledgeZ = function (y) kitZ - (y - yFront) * tan(kitTilt),
    e1 = [sL1[0], ledgeZ(sL1[0])],                           // up to the MR60 ledge
    f1 = add(K0, mul(inV(kitTilt), kitD + foam)),            // end of the ledge (case back + foam)
    f2 = add(f1, mul(upV(kitTilt), kitH - 3))                // top of the case support
) [[yFront, floorZ], [yFront, ldZ - 0.2], [sL0[0], ldZ - 0.2 - (sL0[0]-yFront)*tan(ldTilt)],
   sL1, e1, f1, f2, [yBP + eps, f2[1]], [yBP + eps, floorZ]];

// =====================================================================
// BODY - upright shell with the deck on top. Print upside down (deck on the bed), no supports.
module body() {
    difference() {
        union() {
            difference() {
                sqblock(bodyW, bodyD, bodyR, bodyZ0, bodyZ1 - bodyZ0);
                sqblock(inW, inD, inR, bodyZ0 - eps, bodyZ1 - deck - bodyZ0 + eps);
            }
            // bosses under the deck for the grommet flanges to bear on (keep the deck flat and stiff)
            for (p = neckBolt) translate([p[0], p[1], bodyZ1 - deck - bossT]) cylinder(d=gromFlange + 3, h=bossT + eps);
        }
        // neck bolt holes (grommet shafts) and the cable hole
        for (p = neckBolt) translate([p[0], p[1], bodyZ1 - 5]) cylinder(d=gromOD + 0.4, h=10);
        translate([0, cableHoleY, bodyZ1 - 5]) rrect(cableHole[0], cableHole[1], cableHole[2], 10);
        // back-wall screws into the sled
        for (s=[-1,1], z=backScrewZ) translate([s*screwX, bodyD/2 - wall - 1, z]) rotate([-90, 0, 0]) cylinder(d=m3_clear, h=wall + 2, $fn=24);
        // speaker grille, right side: 6 x 2 dots
        for (i=[0:5], j=[0:1]) translate([bodyW/2 - wall - 1, spkY - 12.5 + i*5, spkZ - 2.5 + j*5]) rotate([0, 90, 0]) cylinder(d=2.0, h=wall + 2, $fn=16);
    }
    // speaker locating rails on the right wall (the speaker drops in from below)
    for (s=[-1,1]) translate([inW/2 - 6, spkY + s*(spkL/2 + clr) + (s > 0 ? 0 : -1.2), spkZ - spkH/2 - 1]) cube([6 + eps, 1.2, spkH + 2]);
}
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

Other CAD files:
hardware/archive/rev-e/stl/0_lidar_template.stl
hardware/archive/rev-e/blender/fanou.blend
hardware/blender/fanou.blend
hardware/blender/marvin.blend

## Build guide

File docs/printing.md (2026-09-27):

# Printing

All parts come from one parametric OpenSCAD source, [`hardware/cad/marvin.scad`](../hardware/cad/marvin.scad). The STLs in [`hardware/stl/`](../hardware/stl/) are exported already oriented for the print bed, and **none of them needs supports**. Every part fits a 180 × 180 mm bed (Bambu A1 mini and up).

> **Rev F status:** the body half is ready to print (lidar template, body, plinth, sensor sled, TPU parts). The head (face frame, window, lidar ring, knob) comes next, once the 1.69" screen is measured on arrival. The rev E lighthouse parts are archived in [`hardware/archive/rev-e/`](../hardware/archive/rev-e/).

## Bambu Studio project (A1 + AMS lite)

[`hardware/bambu/marvin_A1.3mf`](../hardware/bambu/marvin_A1.3mf) is ready to open in Bambu Studio: every part on its plate, the filaments and colours set, the per-part settings and the band colour change already in place. Check the filament profiles against your spools, then slice.

| Plate | Parts | Filament | Time (Bambu Studio estimate) |
|---|---|---|---:|
| 1 | Lidar template, **print it first** | PETG anthracite | 12 min |
| 2 | Body + sensor sled | PETG warm grey, anthracite band from 14 to 44 mm | 2 h 27 |
| 3 | Plinth | PETG anthracite | 30 min |
| 4 | Neck gasket, 4 grommets, 4 feet | TPU 95A, **external spool** (not the AMS lite) | 59 min |

Slots: 1 = PETG warm grey, 2 = PETG anthracite, 3 = TPU black. Textured PEI plate, 0.4 mm nozzle, 0.20 mm layers. The sled also changes colour inside the band: it is hidden in the body, so it does not matter.

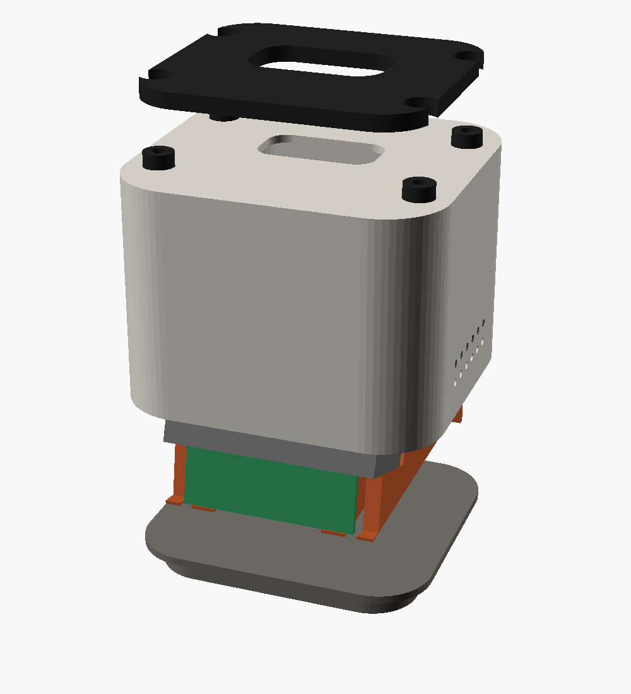
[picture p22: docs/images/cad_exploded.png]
Exploded view of the body half: plinth with the sensor sled and both radars, body shell, grommets and TPU neck gasket


## Parts

| File | Part | Material | Suggested settings | Notes |
|---|---|---|---|---|
| `0_lidar_template.stl` | Lidar template | PLA | 0.2 mm, 2 walls | About 5 min. **Print this first** and test-fit the lidar on it. |
| `1_body.stl` | Body shell | **PETG**, warm grey + anthracite | 0.2 mm, **4 walls of 0.4 mm = exactly 1.6 mm**, 15 % infill | Printed upside down, deck on the bed. The front wall in front of the radars must stay 1.6 mm and flat. The anthracite band is a filament change (see below). |
| `2_plinth.stl` | Plinth | PETG or PLA, anthracite | 0.2 mm, 3 walls, 20 % | Closes the body from below. The USB-C cable leaves through the notch at the back. |
| `3_sensor_sled.stl` | Sensor sled | PETG | 0.2 mm, 3 walls, 20 % | Printed standing, as installed. Carries the 24 GHz radar at 10° and the 60 GHz radar at 20°; the lever connectors and the amp stick on its back plate. |
| `4_tpu_neck_grommets_feet.stl` | Neck gasket, 4 grommets, 4 feet | **TPU 95A**, black | 0.2 mm, 3 walls, 15 % gyroid, slow (≤ 40 mm/s) | Decouples the head (lidar motor) from the body (heart-rate radar). On the A1, feed it from the external spool holder, not the AMS lite. |

Coming with the head: head shell, face frame (screen + XIAO cradle), lidar ring and knob. The face window is not printed: it is cut from the 2.3 mm smoked acrylic.

## The anthracite band

The body prints upside down, so the band is a filament change at two heights measured **from the bed**:

| From | To | Colour |
|---:|---:|---|
| 0 mm | 14 mm | Warm grey (top of the body) |
| 14 mm | 44 mm | Anthracite (the band) |
| 44 mm | 58 mm | Warm grey (bottom of the body) |

- **Bambu A1 with AMS lite:** in Bambu Studio, right-click the layer slider at 14 mm and at 44 mm and choose "Change filament".
- **Single-extruder printer:** insert a pause (M600 or "Pause print") at those heights and swap the filament by hand.

## Why PETG in front of the radars

At 60 GHz, a 1.6 mm PETG wall is half a wavelength thick, so it lets the signal through almost unchanged, even when the radar looks through it at 20°. At 24 GHz the same wall is thin enough not to matter. Keep the wall at 1.6 mm and flat, and avoid metallic, glitter or carbon-filled filaments on the body. The filament colour does not matter: the band is only there for looks.

## Regenerating files

```bash
# every print-ready STL
hardware/scripts/export_stl.sh

# the exploded view in docs/images (headless Linux: prefix with `xvfb-run -a`)
hardware/scripts/render_previews.sh

# the side section diagram in docs/images (needs matplotlib)
python3 hardware/scripts/section_diagram.py

# the Bambu Studio project (needs the Bambu Studio command line)
BAMBU_STUDIO=/path/to/bambu-studio python3 hardware/scripts/build_3mf.py

# the Blender model hardware/blender/marvin.blend (needs Blender 4.2+ or the bpy wheel)
hardware/scripts/build_blend.sh
```

OpenSCAD 2021.01 or newer is required.

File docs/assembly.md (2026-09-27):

# Assembly

> **Rev F status:** the body half (plinth, sensor sled, body, neck) is designed and printable; the steps below are exact for it. The head steps are the plan until the head CAD lands. A photo guide will follow the first build.

You need a small screwdriver, a wire stripper and, for two header strips, a soldering iron. The whole build takes an evening.

<p align="center">Section of the robot: upright shell, 24 GHz radar tilted 10° low in the body with the 60 GHz radar tilted 20° above it, screen vertical and camera tilted 20° in the head, lidar on top</p>

How it goes together: the **plinth** carries the **sensor sled** (both radars, the lever connectors and the amp) and slides up into the **body**, which is held by four screws through its back wall. The **head** sits on the body through a **TPU gasket and four TPU grommets**, so no rigid part links the lidar motor to the heart-rate radar. Every wire between head and body passes through the hole in the neck.

The 24 GHz radar sits **below** the 60 GHz radar on purpose: the 60 GHz beam leaves the robot upwards, so nothing may stand in front of the upper part of that radar.

## Screws

| Where | Screw | Qty |
|---|---|---:|
| Plinth → sensor sled (from below) | M3 × 12 | 2 |
| Body back wall → sensor sled | M3 × 10, button head | 4 |
| Neck: grommets → head floor (from inside the body) | M3 × 14 + washer | 4 |
| Lidar → head | M2.5 × 10 | 3 |

All M3 screws thread-form into the printed pilot holes: no nuts.

## 0. Solder the headers

Solder the 2 × 7 header pins under the XIAO ESP32S3 Sense (long side of the pins pointing away from the camera board) and the 7-pin header on the MAX98357A amp. Skip this step if you bought them pre-soldered.

## 1. Check the lidar on the template

Lay the lidar on the printed template. Its three holes must fall inside the slots. If they don't, adjust `lidPairDY` / `lidSingleDY` in the CAD and please open an issue with your measurements.

## 2. Head (planned)

1. Drill a 6 mm hole in the smoked acrylic for the camera, file the corners round, peel the film, and clip the window into the face frame.
2. **Screen** into the face frame, glass against the acrylic, connector at the back.
3. **XIAO ESP32S3 Sense** into its 20° cradle, lens right behind the hole in the acrylic.
4. Face frame into the head shell; lidar cable up through the lidar ring; lidar on top with 3 × M2.5 × 10.

## 3. Neck

1. Push the four **TPU grommets** up through the deck of the empty body, flange underneath.
2. Lay the **TPU gasket** on the deck, over the grommet shafts.
3. Pass the head wires down through the neck hole, set the head on the gasket and screw it from inside the body: 4 × M3 × 14 with a washer, up through the grommets into the head floor. Stop as soon as the gasket is lightly squeezed.

## 4. Sensor sled

1. **HLK-LD2450**: antenna side forward, bottom edge on the two small lips at the front of the sled, 3 mm foam on the inner ribs behind it.
2. **MR60BHA2 kit** in its printed case: landscape, radar face forward, standing on the sloped ledge above the LD2450, 3 mm foam on the ribs behind it.
3. Stick the four **lever connectors** and the **amp** on the back plate.
4. Screw the sled onto the **plinth**: 2 × M3 × 12 from below.

## 5. Speaker

Slide the **speaker** between the two rails on the inside of the right wall, face against the dot grille, on a strip of foam tape.

## 6. Wire it

Follow the [wire-by-wire table](wiring.md#wire-by-wire-table) and tick each line. Tug gently on every wire in a lever connector: none should come out.

## 7. Close it

1. Pass the USB-C cable in through the notch at the back of the plinth and up through the neck, and plug the right-angle end into the XIAO.
2. Slide the plinth with the sled up into the body and fix it with 4 × M3 × 10 through the back wall.
3. Stick the four TPU (or silicone) feet into the pockets under the plinth.

## 8. First power-up

Plug the other end of the USB-C cable into a charger. You should see:

- the ESP32 LED light up,
- the MR60BHA2 kit's LED light up,
- the screen backlight turn on,
- the lidar start spinning.

If nothing happens, unplug and re-check lines 1 to 5 of the wiring table.

## Check on arrival

These dimensions are not guaranteed by the datasheets. Measure them before printing the big parts, and change the matching parameter in `marvin.scad` if needed:

| What | Designed for | Parameter |
|---|---|---|
| Lidar holes | the printed template (step 1) | `lidPairDY`, `lidSingleDY` |
| MR60BHA2 kit in its case | 54 × 35 × 22 mm | `kitW`, `kitH`, `kitD` |
| HLK-LD2450 board | 44 × 15 × 1.6 mm | `ldW`, `ldH`, `ldT` |
| Speaker | 30 × 20 mm face, at most 5 mm deep | `spkL`, `spkH` |
| 1.69" screen module | to be measured: board size, glass thickness, holes | head (next) |
| Camera lens position on your XIAO Sense | relative to the board edge | head (next) |
| LD2450 cable | should end in female Dupont plugs; if male, add a few male–female jumpers | — |

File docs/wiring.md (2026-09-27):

# Wiring

**29 connections, and the only soldering is two header strips.** This guide assumes you have never wired electronics before.

## The idea in one paragraph

There are two kinds of wires:

- **Power wires** (5 V, 3.3 V and GND) go into one of four WAGO lever connectors. Cut the plug off, strip 10 mm of insulation, lift the lever, insert, and close the lever.
- **Data wires** keep their female Dupont plug and push straight onto a pin of the ESP32.

The USB-C cable (charger or power bank at the other end) plugs into the ESP32's USB-C port. The ESP32's **5V** pin is connected directly to that port's 5 V line, so it feeds the WAGO bus, and the bus powers every sensor.

## Where everything sits in the robot

Body heights come from the rev F CAD; head heights are planned until the head CAD lands.

| Part | Place | Height above the desk |
|---|---|---:|
| Lidar | On top of the head, cable down through the lidar ring | ≈ 133 mm |
| XIAO ESP32S3 Sense | Face frame, tilted 20°, camera above the screen | ≈ 113 mm |
| Screen | Face frame, vertical, behind the acrylic window | ≈ 92 mm |
| MR60BHA2 kit | Body, upper part of the sensor sled, tilted 20° | 42 mm |
| **Lever connectors** | Body, stuck on the back plate of the sensor sled | ≈ 20–55 mm |
| **Amp** | Body, back plate of the sensor sled, low down | ≈ 20 mm |
| Speaker | Body, against the dot grille in the right wall | 18 mm |
| HLK-LD2450 | Body, bottom front of the sensor sled, tilted 10° | 16 mm |

Everything between head and body (XIAO power and data, screen, lidar) runs through the neck damper. Every run fits the 20 cm Dupont jumpers. The USB-C power cable enters at the back of the plinth and climbs through the neck to the XIAO.

## Three rules

1. **Read the label, not the colour.** Wire colours differ between sellers. The pin names printed on each board (TX, GND, 5V…) are what count.
2. **5 V never touches a D pin.** 5 V goes only into its WAGO and onto the ESP32 pin marked **5V**. Anywhere else, it can destroy the ESP32.
3. **Connect the power last.** Wire everything, re-check the table line by line, then plug in the charger. If anything gets hot or smells, unplug it.

## Diagram

```mermaid
flowchart LR
  BANK["Charger or power bank"] -- "USB-C cable, 90° plug" --> XIAO

  subgraph XIAO["XIAO ESP32S3 Sense (built-in mic)"]
    P5V["5V"]; PGND["GND"]; P33["3V3"]; D7["D7 / GPIO44"]; D4["D4 / GPIO5"]; D5["D5 / GPIO6"]
    D0["D0 / GPIO1"]; D1["D1 / GPIO2"]; D3["D3 / GPIO4"]; D8["D8 / GPIO7"]; D10["D10 / GPIO9"]
    D2["D2 / GPIO3"]; D6["D6 / GPIO43"]; D9["D9 / GPIO8"]
  end

  W5["WAGO 5V"]; WGA["WAGO GND-A"]; WGB["WAGO GND-B"]; W33["WAGO 3V3"]
  P5V --> W5
  PGND --> WGA
  WGA -- "link wire" --- WGB
  P33 --> W33

  subgraph LID["Lidar (D800 / D500)"]
    L5["P5V"]; LG["GND"]; LP["PWM"]; LT["Tx"]
  end
  W5 --> L5
  WGA --> LG
  WGA --> LP
  LT --> D7

  subgraph RAD["HLK-LD2450"]
    R5["5V"]; RG["GND"]; RT["TX"]; RR["RX"]
  end
  W5 --> R5
  WGA --> RG
  RT --> D4
  D5 --> RR

  subgraph MR["MR60BHA2 kit"]
    MU["USB-C (pigtail)"]
  end
  W5 -- "red" --> MU
  WGB -- "black" --> MU

  subgraph LCD["1.69in screen (ST7789)"]
    SV["VCC"]; SG["GND"]; SDIN["DIN"]; SCLK["CLK"]; SCS["CS"]; SDC["DC"]; SRST["RST"]; SBL["BL"]
  end
  W33 --> SV
  W33 --> SBL
  WGB --> SG
  D10 --> SDIN
  D8 --> SCLK
  D0 --> SCS
  D1 --> SDC
  D3 --> SRST

  subgraph AMP["MAX98357A amp"]
    AV["VIN"]; AG["GND"]; ABC["BCLK"]; ALR["LRC"]; ADI["DIN"]; ASP["speaker + / -"]
  end
  W5 --> AV
  WGB --> AG
  D9 --> ABC
  D6 --> ALR
  D2 --> ADI
  ASP --> SPK["2030 speaker 8 Ω"]
```

## Wire-by-wire table

Tick each line as you go.

| # | Wire (name printed on the board) | Goes to | How |
|---:|---|---|---|
| 1 | XIAO **5V** | WAGO 5V | Dupont female on the pin, other end cut and stripped |
| 2 | XIAO **GND** | WAGO GND-A | Same as above |
| 3 | XIAO **3V3** | WAGO 3V3 | Same as above |
| 4 | Link wire | WAGO GND-A ↔ WAGO GND-B | A short stripped wire joining the two GND connectors |
| 5 | Lidar **P5V** | WAGO 5V | Cut the Dupont plug off, strip |
| 6 | Lidar **GND** | WAGO GND-A | Cut, strip |
| 7 | Lidar **PWM** | WAGO GND-A | Yes, to ground: the lidar spins at its default speed |
| 8 | Lidar **Tx** | XIAO **D7** | Push the Dupont plug on |
| 9 | LD2450 **5V** | WAGO 5V | Cut, strip |
| 10 | LD2450 **GND** | WAGO GND-A | Cut, strip |
| 11 | LD2450 **TX** | XIAO **D4** | Push the Dupont plug on |
| 12 | LD2450 **RX** | XIAO **D5** | Push the Dupont plug on |
| 13 | USB-C pigtail **red** | WAGO 5V | Usually pre-stripped. The plug goes into the MR60BHA2 kit. |
| 14 | USB-C pigtail **black** | WAGO GND-B | Same as above |
| 15 | Screen **VCC** | WAGO 3V3 | Cut, strip. **3V3, not 5V**: the screen's logic must match the ESP32's 3.3 V. |
| 16 | Screen **BL** | WAGO 3V3 | Cut, strip. The backlight stays on at full brightness; the eyes dim in software by drawing darker colours. |
| 17 | Screen **GND** | WAGO GND-B | Cut, strip |
| 18 | Screen **DIN** | XIAO **D10** | Push the Dupont plug on (SPI data) |
| 19 | Screen **CLK** | XIAO **D8** | Push the Dupont plug on (SPI clock) |
| 20 | Screen **CS** | XIAO **D0** | Push the Dupont plug on |
| 21 | Screen **DC** | XIAO **D1** | Push the Dupont plug on |
| 22 | Screen **RST** | XIAO **D3** | Push the Dupont plug on |
| 23 | Amp **VIN** | WAGO 5V | Dupont female on the amp pin, other end cut and stripped |
| 24 | Amp **GND** | WAGO GND-B | Same as above |
| 25 | Amp **BCLK** | XIAO **D9** | Dupont female–female |
| 26 | Amp **LRC** | XIAO **D6** | Dupont female–female |
| 27 | Amp **DIN** | XIAO **D2** | Dupont female–female |
| 28 | Speaker **+** | Amp terminal **+** | Screw terminal on the amp |
| 29 | Speaker **−** | Amp terminal **−** | Screw terminal on the amp |

The screen ships with a cable that ends in 8 labelled Dupont plugs. Leave the amp's **GAIN** and **SD** pins unconnected: the defaults give 9 dB of gain and a mono mix.

When you are done:

| Connector | Wires | Ports used |
|---|---|---|
| WAGO 5V | XIAO, lidar, LD2450, MR60, amp | 5 / 5 |
| WAGO GND-A | XIAO, lidar GND, lidar PWM, LD2450, link | 5 / 5 |
| WAGO GND-B | link, MR60, screen, amp | 4 / 5 |
| WAGO 3V3 | XIAO, screen VCC, screen BL | 3 / 5 |

Every XIAO pin is used.

## The only soldering

The standard XIAO ESP32S3 Sense ships with loose header pins, and so do most MAX98357A amp boards. Solder these two header strips (7 + 7 pins on the XIAO, 7 pins on the amp) before wiring. It takes about ten minutes. If you buy both boards pre-soldered, the build needs no soldering at all.

## XIAO pin map

As seen **from the pin side** (pins pointing at you, USB-C at the top). In the head frame this is how you see the board from behind; its USB-C port points to the side.

```
               ┌──[ USB-C ]──┐
         5V  ● │             │ ●  D0
        GND  ● │             │ ●  D1
        3V3  ● │             │ ●  D2      Seen from below, the two sides
        D10  ● │             │ ●  D3      are swapped compared with the
         D9  ● │             │ ●  D4      usual top-view pinout drawings.
         D8  ● │             │ ●  D5
         D7  ● │             │ ●  D6
               └─────────────┘
```

If in doubt, compare with Seeed's official pinout.

## Signal details

| Link | ESP32-S3 peripheral | Settings | Logic level |
|---|---|---|---|
| Lidar → ESP32 | UART0 RX on GPIO44 (D7) | 921 600 baud (D800) or 230 400 baud (D500), 8N1, one-way | 3.3 V |
| LD2450 ↔ ESP32 | UART1, RX on GPIO5 (D4), TX on GPIO6 (D5) | 256 000 baud, 8N1 | 3.3 V |
| ESP32 → screen | SPI2 (FSPI): SCK GPIO7 (D8), MOSI GPIO9 (D10); CS GPIO1 (D0), DC GPIO2 (D1), RST GPIO4 (D3). Backlight tied to 3V3. | Up to 80 MHz | 3.3 V |
| ESP32 → amp | I2S1 TX: BCLK GPIO8 (D9), LRC/WS GPIO43 (D6), DOUT GPIO3 (D2) | 16 kHz – 44.1 kHz, 16-bit | 3.3 V |
| Microphone → ESP32 | Built-in PDM mic on the Sense board: CLK GPIO42, DATA GPIO41, on I2S0 | 16 kHz | internal |
| MR60BHA2 → PC | Its own ESP32-C6 over Wi-Fi | — | — |

The ESP32-S3 console uses native USB, which leaves UART0 free for the lidar. No level shifters are needed, because both sensors use 3.3 V UART levels.

## Power budget

| Load | Average | Peak |
|---|---:|---:|
| XIAO ESP32S3 + camera + Wi-Fi | 300 mA | 450 mA |
| D800 lidar (STL-27L) | ≤ 290 mA | ≈ 350 mA (motor start) |
| HLK-LD2450 | 120 mA | 200 mA |
| MR60BHA2 kit | 160 mA | 300 mA |
| 1.69" screen (from 3V3) | 60 mA | 90 mA |
| MAX98357A + speaker | 20 mA idle | 400 mA (loud sound) |
| **Total at 5 V** | **≈ 1.0 A** | **≈ 1.9 A** |

Pick a charger or power bank that delivers at least 2 A. Keep the speaker volume moderate in the firmware: a 1 W speaker can be overdriven by the amp at 5 V.

## Flashing the ESP32

Unplug the charger and plug the same cable into your computer: it goes straight to the XIAO. The two sources must never be connected at the same time, because the 5V pin is wired straight to the port. After the first flash, updates go over Wi-Fi (OTA).

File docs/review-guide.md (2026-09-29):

<!-- SPDX-License-Identifier: CC-BY-4.0 -->
# Review guide: the Java host (migration phases 0 to 3)

The change adds `host-java/` (a Spring Boot host at parity with the Python host), the `./marvin`
launcher, the Python voice sidecar (`host/marvin_host/sidecar/voice`) and a few deliberate changes to
the Python host (phases 0 to 2); then memory v1 and the new app (phase 3, [its own reading
order](#memory-v1-and-the-new-app-design-phase-3)). The Python host still works and its tests still pass. The work
is big (most of it tests, golden files and generated gRPC code), so review it in this order.

## 1. What was asked, and what was decided (30 min)

1. [design.md](design.md): sections 3 (architecture), 4 (the sidecars), 10.4 (ready for
   microservices) and 11 (migration plan, phases 0 to 2). This is the specification.
2. [host-java/NOTES.md](../host-java/NOTES.md): one section per stage. Each has **Decisions and
   deviations** (where and why the code differs from the design), **Known gaps** and **Verified**.
   Read the deviations and the gaps. The "Review fixes" section lists what an earlier review
   found and how each finding was fixed.
3. [host-java/README.md](../host-java/README.md): how to run, the variables, the module table.

## 2. Module map

| Module | Holds | Start with |
|---|---|---|
| `marvin-domain` | Plain Java, no Spring, no I/O: `robot` (protocol v1 messages, device monitor), `presence` (the brain and events, ported from `brain.py`/`events.py`; day statistics), `conversation` (persona, speech text and `</think>` handling, sentence splitter, weather tool, settings), `settings`, `face`, `system` | `presence/Brain.java`, `conversation/SpeechText.java` |
| `marvin-application` | Use cases and ports per context (`port.in`, `port.out`): `VoiceService` (the conversation: turn order, answer loop, tools, memory), `AnswerLoop`, `PresenceHistoryService` + `HistoryWriter` (history written off the robot thread), `RobotAudioService`, health | `conversation/VoiceService.java`, `conversation/AnswerLoop.java` |
| `marvin-adapter-robot` | UDP 47100 (HELLO/HOST_ACK, lidar, LD2450, vitals, face link, audio relay), `.mvrec` record/replay, datagram tap | `UdpRobotLink.java` |
| `marvin-adapter-persistence` | PostgreSQL through JdbcClient, Flyway, one schema per context, the one-time SQLite import, `voice.json`, embedded PostgreSQL | `SqliteImporter.java`, `db/migration/*` |
| `marvin-adapter-web` | The app (the Java host's own since phase 3, `app/`), the Python host's REST API and SSE streams, the memory API, the access key, the face PNG | `AccessFilter.java`, `ApiController.java`, `MemoryController.java` |
| `marvin-adapter-llm` | Ollama through Spring AI (streaming, tool calls); memory's model and embeddings (JDK HTTP client) | `OllamaLanguageModel.java`, `OllamaMemoryModel.java` |
| `marvin-adapter-sidecar` | gRPC client of the voice sidecar, the process supervisor, the Python runtime | `GrpcVoiceSidecar.java`, `SupervisedProcess.java` |
| `marvin-app` | Spring Boot wiring (`HostWiring`, `VoiceWiring`), lifecycle, tracing, ArchUnit rules | `ArchitectureTest.java` |
| `marvin-contracts` | Golden files made by the **Python** host (`tools/*.py`): protocol vectors, recordings with their expected events, API snapshots, face and conversation vectors; `voice.proto` | `README.md`, `golden/` |
| `host/marvin_host/sidecar/voice` | The voice sidecar (Python): audio, VAD, wake word, speech recognition and synthesis behind gRPC | `engine.py`, `server.py` |
| `marvin` (repo root) | The launcher: JDK, build, PostgreSQL, host, venv, doctor | `cmd_up` |

Boundaries are enforced, not only described: `ArchitectureTest` (layers, contexts only through
ports, adapters independent of each other, domain without Spring or I/O, Boot glue in
`@Configuration` classes only; `ArchitectureRulesBiteTest` shows each rule fails on a fixture),
the Maven enforcer (domain and application depend on nothing else), and `SchemaOwnershipTest` (a
context's storage names only its own schema).

## 3. Where parity is proven

| What must match the Python host | Proof |
|---|---|
| UDP bytes, protocol v1 | `ProtocolVectorsTest` (Python-made vectors for every message), `UdpRobotLinkTest`, `SimulatorLinkIT` (the real Python simulator against the Java socket) |
| The brain's events and states | `GoldenRecordingsTest`: Python recordings replayed through the Java brain, compared with the Python events and states |
| `.mvrec` files | `MvrecCompatibilityTest`, `PythonReadsJavaRecordingTest` (both directions) |
| API JSON, headers, access rules | `ApiContractIT` replays every request recorded from the Python host (`golden/api`) and compares status, headers and shapes; `PyJsonTest` (Python's number and escaping format) |
| The app itself | `AppFilesTest`: every file served, nothing from the network, no inline script or style, Day and Night define the same variables (the Java app is its own since the app shell stage); `e2e/e2e.py` in a browser |
| Face | `FaceVectorsTest` (the Python renderer's pixels) |
| Conversation text handling and tools | `ConversationVectorsTest`, `ToolVectorsTest` (Python-made vectors: speech text, `</think>`, splitter, weather) |
| Voice behaviour end to end | `VoiceEndToEndIT` (the real sidecar in its test mode, a stub model, a spoken question through wake word, answer and latency), `GrpcVoiceSidecarIT`, `VoiceServiceTest` (turn order, interruption, errors) |
| History and import | `StoresAndImportIT`, `DayStatsTest`; the final check compared `/api/history`, `/api/day`, `/api/conversation` of both hosts on the same imported database (NOTES, "Final verification") |
| The whole thing in a browser | `host-java/e2e/` (Playwright walk, stub Ollama, second device); screenshots in the final verification |

Run everything: `cd host-java && ./mvnw verify` (Docker needed for the `*IT` tests) and
`cd host && python3 -m pytest -q`.

## 4. Changes to the Python host (deliberate)

- The voice package split: the audio half is the sidecar (`sidecar/voice`); `marvin-host talk` and
  `run --voice` still work in process.
- `ui/server.py`: the Host check accepts only whole names (DNS rebinding fix, the same in both hosts).
- `parent.py`: a child started by the Java host exits when the host dies.
- Contract tools under `host-java/marvin-contracts/tools` import the Python host to make the golden files.

## Memory v1 and the new app (design phase 3)

Built in six stages (write path, read path, app shell, app screens, review fixes, final verification), each with a
section under "Memory v1" in [NOTES.md](../host-java/NOTES.md). About half a day, in this order:

1. **The specification** (30 min): [design.md](design.md) section 5 (memory), then 3, 9 and 10.4, with their "as
   built" notes where reality differs. The approved visual direction is described in [ui.md](ui.md).
2. **How it works** (30 min): [memory.md](memory.md) (the log, facts on two clocks, the worker, the read path, the
   tools, the API, forgetting, the evaluation set, where the code is).
3. **What was decided and what is missing**: NOTES.md, "Memory v1", each stage's *Decisions and deviations* and
   *Known gaps*; the last stage, *Final verification*, says what was checked end to end.
4. **The rules**, plain Java: `domain/memory` (`Reconciliation`, `FactCandidate`, `ProfileText`, `RetrievalScoring`,
   `DecayRules`, `Redaction`, `EventFeeds`).
5. **The use cases**: `application/memory` (`MemoryLogService` and the catch-up, `Consolidator`, `MemoryWorker`,
   `NightlyPass`, `MemoryGuard`, `MemoryAdminService` and forgetting, `ForgetConfirmations`, `MemoryRecallService`,
   `MemoryExportService`) and their ports; tests: `ConsolidatorTest`, `MemoryWorkerTest`, `NightlyPassTest`,
   `MemoryPrivacyAndRobustnessTest`.
6. **Storage**: `db/migration/memory/V1..V3`, `JdbcEventLog`, `JdbcFactStore` (pgvector, and the exact search without
   it), `MemoryStoresIT`.
7. **The models**: `OllamaMemoryModel`, `OllamaEmbedder`, the prompts in `marvin/memory/prompts/v1/`,
   `OllamaMemoryModelTest`, `MemoryEvaluationTest` (the evaluation set).
8. **Memory in the voice**: the conversation's port `MemoryContext` and its bridge `MemoryForConversation`
   (marvin-app), `ContextAssembler`, `Persona.systemPrompt`, `VoiceService` (`prefetch`, `assemble`, `usage`),
   `MemoryTools`; tests: `VoiceMemoryTest` (the system prompt byte-identical between questions and languages, budgets
   cut by score, the cost on the voice's path), `MemoryToolsLoopTest`, `MemoryForConversationTest`.
9. **The API and the app**: `MemoryController`, `MemoryApiIT`; the app in `marvin-adapter-web/.../app/` (`theme.js`,
   `face.js`, `home.js`, `talk.js`, `inspector.js`, `memory.js`, `memtools.js`, `worker.js`, `activity.js`,
   `marvin.js`, `system.js`), `AppFilesTest`.
10. **End to end**: `MemoryEndToEndIT` (the whole host), `host-java/e2e/week.py` (a scripted week in French and
    English against the running host) and `e2e.py` (every screen, both appearances, phone and desktop); their
    screenshots are listed in NOTES.md.
11. **The owner's checks on the Mac**: [test-plan.md](test-plan.md), part 11 and checks 9.4 to 9.6.

The boundaries: `memory` is a bounded context with its own schema and Flyway history; the conversation reaches it only
through its own `MemoryContext` port, plugged in `marvin-app` (`ArchitectureTest`, and `ArchitectureRulesBiteTest`
shows the rule fails on a fixture).

## 5. Known gaps and risks (details in NOTES.md)

- Only one host can own UDP 47100. History written by the Java host stays in PostgreSQL: going back
  to the Python host shows its own SQLite history only. The import runs once, so days spent on the
  Python host afterwards are not imported.
- Not run on macOS or with real boards before release: [test-plan.md](test-plan.md) covers it.
- `/api/state` and `today` answer 500 after 5 s while PostgreSQL is down (robot and voice keep going).
- No trace context sent to the sidecar yet (phase 3: a `trace_parent` field in the voice contract).
- Four Boot lifecycle classes are known exceptions to the glue rule (`ArchitectureTest.BOOT_GLUE_KNOWN`).
- The embedded PostgreSQL (used without Docker) has no pgvector yet, and its test is skipped as root.
- Cosmetic: an empty day's `present_s`/`seated_s` are `0.0` in Java, `0` in Python (the same number in JSON).
- Memory: extraction quality and the first-word cost of memory are measured on the stub only; the owner's model and
  Mac numbers come from the test plan (part 11, 9.4 to 9.6). Forgetting a fact withholds the whole conversation batch
  it was learned from. Details: NOTES.md, "Memory v1", each stage's known gaps.

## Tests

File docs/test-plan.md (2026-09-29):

<!-- SPDX-License-Identifier: CC-BY-4.0 -->
# Test plan: the Java host on a Mac

A manual check of the Java host (`./marvin`) with the real boards, the real voice and a real model,
before it replaces `marvin-host run` for good. About an hour, and half an hour more for memory and the
new app ([part 11](#11-memory-and-the-new-app)). Each check says what to do and what you should see;
write down any difference (and the last lines of `./marvin logs -n 100`).

The setup this plan assumes: an Apple Silicon Mac (M3 Max) on the same 2.4 GHz Wi-Fi as the boards,
Ollama with the model `qwen3.8:27b-mlx`, a Wemos D1 mini and an ESP32-S3 DevKitC running the firmware
with simulated sensors, and `host/.venv` already set up for the Python host.

## 0. Before you start (once)

1. Update the repository: `git pull`.
2. Keep a copy of the Python host's history, in case: `cp ~/.local/share/marvin/marvin.db ~/marvin-before-java.db`.
3. Stop the Python host if it runs (`Ctrl+C` in its terminal): only one host can own UDP port 47100.
4. Start Docker Desktop (optional: without it the host runs its own PostgreSQL; the first choice is kept).
5. Start Ollama (the app, or `ollama serve`) and check the model: `ollama list` shows `qwen3.8:27b-mlx`.
6. `./marvin doctor`. Expected: `ok` lines, possibly `note` lines, and `Ready: ./marvin up` at the end.
   A missing JDK is not an error: `./marvin up` downloads one into `~/.local/share/marvin/jdk`.

## 1. Start and stop

| # | Do | Expected |
|---|---|---|
| 1.1 | `./marvin up` | The first time: JDK download, Java build (a few minutes), `Starting PostgreSQL ...`, `Starting Marvin's host (live) ...`, then `Marvin's app: http://localhost:8765/` and a phone address with `?token=`. The prompt comes back. |
| 1.2 | `./marvin status` | `host: running (pid ..., live)`, a `health:` line where `database`, `robot` and `voice` are `up` (`robot` says `no robot yet` until a board links), `postgres: running`. |
| 1.3 | Open http://localhost:8765/ | The app: the top bar with Marvin's eyes and `Live · on this computer`. No error banner. |
| 1.4 | `./marvin up` again | `Marvin's host is already running (pid ...)`; nothing restarts. |
| 1.5 | `./marvin restart` | The host stops and starts again in a few seconds; the app reconnects by itself (header dot back to Live). |
| 1.6 | `./marvin down`, then `./marvin status` | `Stopped.`; status says `host: not running`. The app says the host does not answer ("What you see may be out of date"). |
| 1.7 | `./marvin up`, then `./marvin logs -n 30` | The last log lines, no `ERROR`. |

## 2. Robot link

| # | Do | Expected |
|---|---|---|
| 2.1 | Power the Wemos D1 mini | Within 2 s its LED stops blinking fast and flashes every 2 s. App, **Marvin > Robot**: the device list shows `marvin-xxxxxx`, `Wemos D1 mini (ESP8266)`, simulated. |
| 2.2 | Marvin > Robot, lidar and radar views | The lidar top view is redrawn several times a second, the radar shows a moving target, the vital signs move. The top bar shows the **Simulated** badge. |
| 2.3 | Power the ESP32-S3 DevKitC | A second device `ESP32-S3 DevKitC` in the list (`2 of 2 connected`). Its screen shows Marvin's face, which follows the presence state (eyes open when someone is there, reacts to events). |
| 2.4 | `./marvin status` | `robot` is `up` and names a linked device. |

## 3. Presence (with the simulated sensors)

The simulated person comes in, sits down, stands up and leaves in a loop of about a minute and a half.

| # | Do | Expected |
|---|---|---|
| 3.1 | Watch **Home** for two minutes | Marvin's eyes follow the state; the sentence under them changes (`You're here, up and about`...); **Recent moments** gets `You came in`, `You sat down`, `You left`, with the time. Breathing appears while seated (marked **Simulated reading**). |
| 3.2 | Home, **Breaks and breathing** | While seated, the time left before the next break counts down (the interval from Marvin > Preferences). |
| 3.3 | Home, **Your day** | Seated time and breaks grow; the day's timeline gets the new sessions. |

## 4. The app, section by section (on the Mac and on the phone)

| # | Do | Expected |
|---|---|---|
| 4.1 | On the phone, open the address `./marvin up` printed (`http://<Mac address>:8765/?token=...`) | The same app, with the five destinations in a bar at the bottom. It keeps working after reloading the page without `?token=` (the key is kept in a cookie). |
| 4.2 | On the phone, the same address without `?token=` in a private tab | Refused (the access key is needed from other devices). |
| 4.3 | **Home** | Marvin's eyes, your decision ("Nothing needs you."), your day, a small thing remembered, breaks and breathing, recent moments. **Customize** hides and reorders them. |
| 4.4 | **Marvin > Robot** and **Marvin > System** | Devices, lidar, radar, vital signs; System lists each service with its state and the host log (new lines appear by themselves, filters work). |
| 4.5 | **Activity > History** | The day (timeline, seated time, breaks), the arrow goes to the previous day, the last seven days, the day in Marvin's words, and the day's conversation. |
| 4.6 | History, search box: type a word you said to Marvin before | The matching sentences from all days, with their date; clearing the box shows the day again. |
| 4.7 | **Marvin > Voice & models** and **Marvin > Preferences** | The voice's settings, Ollama and its models, memory's models; break reminder, quiet hours, clock, sounds, appearance. |

## 5. Voice

Turn the voice on in the **Talk** panel (the switch); the first time it takes a few seconds (models load).

| # | Do | Expected |
|---|---|---|
| 5.1 | Marvin > Voice & models, language model: pick `qwen3.8:27b-mlx`, **Apply** | Saved, the voice restarts with it; Talk shows the model's name. |
| 5.2 | Wake word: say "Marvin, bonjour" | Your sentence appears (`bonjour`), Marvin answers aloud in French, the answer appears as it is spoken. |
| 5.3 | Follow-up: right after the answer, ask another question without "Marvin" | Marvin answers (the listening window stays open `follow_up_s` seconds, shown by the listening bar). |
| 5.4 | Press **Talk now**, ask a question without "Marvin" | The button shows `Listening`, a countdown bar; Marvin answers. |
| 5.5 | Type a question in `Write to Marvin…`, press the arrow | It appears marked as typed; Marvin answers aloud and in text. |
| 5.6 | Tools: "Marvin, quel temps fait-il à Nice demain ?" | A short `Je regarde…`, then the real forecast for Nice (compare with a weather site). |
| 5.7 | Think leak: ask two or three weather questions in a row, and one that needs reasoning ("Marvin, combien font 17 fois 23 ?") | Marvin never says his reasoning aloud ("Okay, the user asks..."), never says `think`. If a model leaks, only the answer is spoken. |
| 5.8 | Inspector: **Why this answer** under one of Marvin's answers | It opens: what you said, what Marvin answered, **Where the time went** (end of speech, recognition, model, synthesis), the tool calls with their results, **Memory in this answer** (the profile's version, each section with its budget, what was kept), the prompt. |
| 5.9 | **Mute** | The button is pressed, "Marvin, ..." is no longer heard; press again to unmute. |
| 5.10 | Ask a long question ("Marvin, raconte-moi une histoire"), press **Stop** while he speaks | He stops within a moment; the answer is marked `interrupted`. |
| 5.11 | Interrupt by voice: while he speaks, say "Marvin, stop" | Same as 5.10 (barge-in). |
| 5.12 | Turn the voice off with the switch | Status `off`; turning it back on works. |

## 6. Settings

| # | Do | Expected |
|---|---|---|
| 6.1 | Marvin > Preferences: set the break reminder to 45 min, save | Saved; Home's breaks card counts from 45 min. |
| 6.2 | Marvin > Voice & models: change the follow-up window to 8 s, **Apply** | Saved; after an answer the listening strip stays open about 8 s. `cat ~/.config/marvin/voice.json` shows `"follow_up_s": 8.0`. |
| 6.3 | Voice & models: turn tools off, **Apply**, ask the weather | No tool call in the answer's inspector and no `Je regarde…` (the model answers on its own, possibly saying it cannot check). Turn tools back on. |
| 6.4 | Voice & models: type a model name with a space (`bad model`), **Apply** | `llm_model must be an Ollama model name, e.g. qwen3:4b-instruct` under the form, nothing saved. |

## 7. Persistence and import

| # | Do | Expected |
|---|---|---|
| 7.1 | First `./marvin up` only: `./marvin logs -n 500 \| grep imported` | `imported .../marvin.db: N events, N samples, N conversation`: the Python host's history is in PostgreSQL. |
| 7.2 | History: go back to days before the switch | The same days, bars and conversations as the Python host showed. |
| 7.3 | `./marvin down`, `./marvin up`, open History and search a sentence from section 5 | Still there; settings from section 6 kept; the voice comes back in the state you left it (on or off). The log does not import again. |
| 7.4 | Reboot the Mac (with Docker Desktop), `./marvin up` | Same data (Docker starts if it is not running; the host never opens an empty second database). |

## 8. Failure cases

| # | Do | Expected |
|---|---|---|
| 8.1 | Quit Ollama, ask a typed question | Marvin says `Je n'arrive pas à joindre mon modèle de langage. Ollama est-il lancé ?` (or the English one), with how to start Ollama under the answer; Settings > Voice says Ollama is not running. Start Ollama again: the next question is answered, no restart needed. |
| 8.2 | Unplug the D1 mini (and the S3) | After about 10 s the status says `Marvin is offline`, the devices show as not connected. Plug it back in: `Connected to the robot`, events resume. |
| 8.3 | Kill the voice: `pkill -f marvin_host.sidecar.voice` | The Talk panel shows `starting` for a moment, then the voice is back on by itself within about 2 s. The log says `restarting the voice sidecar`. |
| 8.4 | Kill the host hard: `kill -9 $(cat ~/.local/share/marvin/run/host.pid)` | Within 3 s no `marvin_host` Python process is left (`pgrep -fl marvin_host` is empty). `./marvin up` starts again cleanly. |
| 8.5 | Stop the database: `docker stop marvin-postgres`, wait 20 s, `docker start marvin-postgres` | The robot views keep moving; `curl -s localhost:8765/actuator/health/readiness` says `DOWN` then `UP`; the events of that time appear in Recent afterwards. |

## 9. Performance

| # | Do | Expected |
|---|---|---|
| 9.1 | Ask 5 short spoken questions; read the time under each answer | First word about 2.8-3.2 s with the 27B model and Piper, about 4.4-4.7 s with `say` ([voice.md](voice.md#latency)); the first question after a start can be slower. |
| 9.2 | Same 5 questions on the Python host (section 10) | The Java host is not slower by more than about 0.1 s on average. |
| 9.3 | `ps -o rss=,%cpu= -p $(cat ~/.local/share/marvin/run/host.pid)` at idle, robot linked | About 250 MB (the first number, in KB), CPU a few percent at most. |
| 9.4 | What memory costs the first word. Start with `MARVIN_JAVA_OPTS="-XX:+UseSerialGC -Xmx384m -Dmarvin.memory.read=false" ./marvin up`, ask the same 20 short questions (typed in Talk, so that recognition is out of the measure), note each reply's first-word time; then `./marvin up` (memory read on) and the same 20 questions, with some facts and yesterday's summary in memory. In each reply's inspector read "memory" (tokens sent) and Ollama's `prompt_eval_count`/`prompt_eval_duration`; the host log has one `prompt:` line per question. | The median first word with memory is within 100 ms of the median without it (docs/design.md, phase 3). If not, lower `marvin.memory.volatile-budget` (tokens, default 250) and note the prompt evaluation rate (tokens per second) of the voice model. |
| 9.5 | Ask a question while a memory pass runs: `curl -s -X POST localhost:8765/api/memory/consolidate -H 'Content-Type: application/json' -d '{"pass":"nightly"}'`, then speak at once | The pass yields (Memory > Memory at work: "yielded"), `ollama ps` shows the night model's request gone within a second, and the first word is not more than about 0.3 s later than usual. |
| 9.6 | Switch languages: ask "Marvin, quelle heure est-il ?", then "Marvin, what time is it?", then French again; read the host log's `prompt:` lines (`./marvin logs -n 50 \| grep prompt:`) | After the first question each one evaluates only its new message (a few hundred tokens at most), whatever the language: the system prompt does not name the language, so a switch does not re-read it. |

## 10. Going back to the Python host

The Python host is kept and still works on its own SQLite file.

```bash
./marvin down                                   # frees UDP 47100 and port 8765
cd host && source .venv/bin/activate
marvin-host run --voice                         # as before: viewer, app on :8765, voice
```

What it shows: its own history up to the day of the switch (`~/.local/share/marvin/marvin.db`, which
the Java host reads once and never writes). What happened while the Java host ran stays in PostgreSQL
and is not visible there; the voice settings (`~/.config/marvin/voice.json`) and the access key are
shared. To come back: `Ctrl+C`, then `./marvin up` (the import is not repeated: days spent on the
Python host in between are not imported).

To undo everything the Java host added: `./marvin down`, `docker rm marvin-postgres`,
`docker volume rm marvin-pgdata` (or `rm -rf ~/.local/share/marvin/pg` without Docker), and
`rm ~/.local/share/marvin/db_mode`.

## 11. Memory and the new app

What Marvin remembers, why, and how you correct it. Do it in order: each step builds on the one before. Memory
learns from what you say to Marvin; "Consolidate now" makes it learn at once instead of waiting until you have been
away for a while.

**Before you start (once)**

1. `ollama pull qwen3-embedding:8b` (the embedding model memory searches with: about 4.7 GB, French and English).
2. Choose the night model. Memory uses the voice's model by default. If the voice runs a small model (for example
   `qwen3:4b-instruct`, for a quick first word), set a larger one for the night in **Marvin > Voice & models**,
   *Memory's models*, *At night*: `qwen3.8:27b-mlx` (the night has time, and a larger model extracts better). If the
   voice already runs the 27B model, leave both empty.
3. `./marvin doctor`: an `ok` line for the embedding model `qwen3-embedding:8b`.

**Step by step**

| # | Do | Expected |
|---|---|---|
| 11.1 | Open **Memory**, then **Marvin > System** | Memory: empty lists that say so, no notice at the top (a notice with `ollama pull qwen3-embedding:8b` means the model is missing). System: *Memory* is up and says how it searches (`pgvector HNSW index` with Docker). |
| 11.2 | Say "Marvin, j'habite à Nice." then "My sister Julie lives in Nantes." then "Je préfère le thé au café." | Marvin answers each; nothing new in Memory yet (it learns later). |
| 11.3 | Memory > *Memory at work* > **Consolidate now**, wait until it says *done* | **Suggested** shows the facts in English ("The owner lives in Nice.", "Julie is the owner's sister and lives in Nantes.", ...), each with where it comes from ("From a conversation · Today, ..."). Nothing about the weather or small talk. |
| 11.4 | **Source & edit** on "The owner lives in Nice." | The sentence you said, quoted and dated; **Open that conversation** opens Activity > History at that line. This is how you see *why* Marvin remembers something. |
| 11.5 | Say "Marvin, on a déménagé à Lille." Then **Consolidate now** | "The owner lives in Lille." in **All memories**; "The owner lives in Nice." moves to **Past**, with the day it stopped being true. |
| 11.6 | Say "Marvin, souviens-toi que mon rendez-vous chez le dentiste est vendredi à dix heures." | Marvin says it will remember; a chip *Remembered: ...* under the answer in Talk; the fact is in Memory at once, marked **Yours**. |
| 11.7 | Say "Marvin, où est-ce que j'habite ?", then open **Why this answer** | He says Lille, not Nice. *Memory in this answer* lists what was sent: the profile's version and the facts kept, each with its score. |
| 11.8 | Say "Marvin, what do you remember about Julie?" | A chip *Looked in memory*; he mentions Nantes. |
| 11.9 | Say "Marvin, je suis allergique aux arachides." Then **Consolidate now** | The fact is marked **Sensitive**; it is not in the profile, and it is not used while someone else is in the room. |
| 11.10 | Memory > *Memory at work* > **Run the nightly pass** | *Days, in Marvin's words*: today is written after tonight, earlier days are there; **Your profile** gets a new version (the facts that matter most, Lille and not Nice, nothing sensitive). **Read profile & versions** shows what changed. |
| 11.11 | **Read profile & versions** > **Edit**: add the line "Call me by my first name.", save; then **Run the nightly pass** again | Your line is marked as yours and is still there after the rewrite. **Use this version again** on an older version brings it back. |
| 11.12 | Say "Marvin, oublie que ma sœur habite à Nantes." | He says what he would forget and asks you to confirm; **Home** > *Your decision* shows the request with **Keep** and **Forget**. |
| 11.13 | Press **Forget** on Home. Then ask "Marvin, where does my sister live?" | The fact is gone from Memory (all filters) and from the profile and its older versions; he does not know any more. The conversation itself stays in History. After **Consolidate now** it does not come back. |
| 11.14 | Pick a fact, **Source & edit**, correct it (for example the dentist's day), save | A new version; the old one is listed under the fact's versions. **Pin**: the fact moves to *Pinned* and never fades. |
| 11.15 | Memory > **Export**, JSON then Markdown | Two files download (`marvin-memory-<day>.json`, `.md`): every fact with its sources, the summaries, the profile and its versions. Nothing you forgot is in them. |
| 11.16 | `./marvin restart`, open Memory | Everything is still there, nothing forgotten came back. |
| 11.17 | Memory > *Memory, on your terms*: switch off **Your conversations**, say something, **Consolidate now**; switch it back on | Nothing said while it was off reaches memory. |
| 11.18 | Appearance: top bar **Day**, **Night**, then **Auto**; then switch macOS to dark (System Settings > Appearance) | Colours change, nothing moves (same layout in both). Auto follows the Mac at once. The phone keeps its own choice. |
| 11.19 | Resize the browser from wide to phone width, and open the app on the phone | Wide: a rail on the left. Narrow and on the phone: a bar at the bottom. Every screen fits without sideways scrolling. |
| 11.20 | **Activity** and **Marvin > Overview** | Tasks & approvals, Soul and Connections say "coming later", with no button that pretends to do something. |
| 11.21 | Last: Memory > *Memory, on your terms* > **Forget everything**; read what goes and what stays, type `forget everything` | Memory is empty (facts, summaries, profile). Ask "Marvin, où est-ce que j'habite ?": he does not know. History still has the conversations. |

**What Marvin remembers, and why**: Memory lists every fact with its source (**Source & edit**); **Why this answer**
under each reply shows what went into that question; **The raw log** (Memory, on your terms) is everything memory was
told; the export is all of it in one file.

**Reset memory without the app** (the host running): the same two-step request as the app,

```bash
code=$(curl -s -X POST localhost:8765/api/memory/forget-everything -H 'Content-Type: application/json' \
  -H 'Origin: http://localhost:8765' -d '{}' | python3 -c 'import json,sys; print(json.load(sys.stdin)["confirm"])')
curl -s -X POST localhost:8765/api/memory/forget-everything -H 'Content-Type: application/json' \
  -H 'Origin: http://localhost:8765' -d "{\"confirm\": \"$code\", \"phrase\": \"forget everything\"}"
```

**How good is extraction with your model** (about 5 minutes, Ollama running): from the repository,

```bash
cd host-java
MARVIN_EVAL_OLLAMA=http://localhost:11434 MARVIN_EVAL_MODEL=qwen3.8:27b-mlx MARVIN_EVAL_EMBED=qwen3-embedding:8b \
  ./mvnw -q -pl marvin-adapter-llm -am test -Dtest=MemoryEvaluationTest -Dsurefire.failIfNoSpecifiedTests=false
cat marvin-adapter-llm/target/memory-eval-report.txt
```

Expected: recall and precision of at least 0.7 each; note both numbers, and run it again with the voice's model if
it is a different one.

## Without the hardware

The same checks run without boards, model or microphone (this is how they were run before release):
`host-java/e2e/README.md` has a stand-in Ollama, a second simulated device, a scripted walk
through the app and a scripted week for memory (`week.py`); `./marvin demo` runs a simulated robot
and a simulated past week on its own database.

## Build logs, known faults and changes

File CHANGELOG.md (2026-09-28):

# Changelog

All notable changes to this project are documented here. The format follows [Keep a Changelog](https://keepachangelog.com/en/1.1.0/). Each hardware revision is a git tag (`rev-B` to `rev-E`; rev A predates the repository). Rev F will be tagged once the head is designed and the first unit is built.

## [Unreleased]

### Java host (2026-09-28)
- `host-java/`: the host core in Java 25 and Spring Boot 4.1 (hexagonal, bounded contexts, ArchUnit), built phase by phase from `docs/design.md` and checked against the Python host (`marvin-contracts`: protocol vectors, recordings, API snapshots, face and conversation vectors). It reaches parity with `marvin-host run`: the robot link (UDP protocol v1), the brain, the face, the history in PostgreSQL (the Python host's `marvin.db` imported once), the app unchanged, and the voice: the conversation in Java (Ollama through Spring AI, tools, memory, reminders), the audio loop in the Python voice sidecar it supervises (`host/marvin_host/sidecar/voice`, gRPC `marvin.voice.v1`).
- `./marvin up` is now the way to run Marvin (PostgreSQL, the Java host and its voice); `./marvin demo`, `status`, `logs`, `doctor`, `down`. The `marvin-host` commands stay as tools: simulator, viewer, recording, replay, calibration.

### Software prototype (2026-09-27)
- `docs/protocol.md`: robot → host UDP protocol v1. Zero-configuration discovery (`HELLO` broadcast, `HOST_ACK`), raw lidar and LD2450 frames in a 16-byte envelope.
- `host/`: the `marvin-host` Python package. Parsers for LDROBOT and HLK-LD2450 frames, sensor extrinsics, UDP receiver with loss counting, live Rerun view and recording, and a simulated robot (room, walking person, D500 or D800 lidar). `marvin-host demo` runs everything on one computer. Tests with `pytest`.
- Simulated home office (`host/marvin_host/scene.py`, shared with the firmware through a generated header): walls, furniture at their real heights, and a person who comes in, sits at the desk and leaves. Simulated camera rendering the same room, and MR60BHA2 vital signs (`VITALS` message).
- Viewer layout: 3D, camera with lidar and radar projected onto the image, lidar top view, radar-style mmWave view, presence and vital-sign time series.
- The brain (`host/marvin_host/brain.py`): presence, seating, stillness and vital-sign reliability as debounced events (`events.py`), shown in the viewer. The simulated MR60BHA2 now drops out while the person fidgets, as the real one does.
- The face (`host/marvin_host/face.py`, `docs/face.md`): the robot's eyes as a reference renderer for the 240 × 280 screen, following the person, blinking, reacting to events and falling asleep; shown live in the viewer.
- Real sensors (`firmware/src/sensor_framing.*`, `sensors_real.*`): resynchronising framers for the LDROBOT lidar and the HLK-LD2450 (with its multi-target init sequence), UART drivers for the XIAO ESP32-S3; `xiao_esp32s3` builds the real robot, `xiao_esp32s3_sim` keeps simulated sensors. Unity tests run on the PC (`pio test -e native`).
- The face on the robot (`firmware/src/face/`): C++ port of the face, identical to the Python reference frame for frame, a small ST7789 driver sending only what changed, and host → robot messages `FACE_STATE` and `FACE_EVENT` (`host/marvin_host/link.py`).
- `firmware/mr60_bridge/`: firmware for the MR60BHA2 kit's ESP32-C6 that sends its vital signs to the host (`VITALS`, board 4).
- The app (`host/marvin_host/ui/`, `docs/ui.md`): a local web page for computer and phone with the live face, today's timeline, breaks, 7-day history and settings; events and daily stats kept in SQLite on the computer. `marvin-host ui --demo` shows it with a simulated robot.
- The voice (`host/marvin_host/voice/`, `docs/voice.md`): "Marvin" wake word, Whisper speech-to-text, a local LLM through Ollama and macOS/Piper speech, with the brain's context and break reminders; all local. `marvin-host talk`, `marvin-host run --voice`.
- Audio and camera on the robot (`firmware/src/audio/`, `firmware/src/camera/`, `docs/audio.md`): I2S speaker with earcons and streamed speech, PDM microphone streamed to the host, MJPEG camera on port 81 shown in the viewer; protocol messages `AUDIO_IN`, `AUDIO_OUT`, `AUDIO_CTRL`, `SOUND` and HELLO capability flags.
- Tools (`docs/tools.md`): wireless firmware updates (OTA, `xiao_esp32s3_ota`), raw session recording and replay (`.mvrec`), automatic or manual lidar yaw calibration.
- PlatformIO platforms are pinned (espressif32 7.1.3, espressif8266 4.2.1).
- `firmware/`: first PlatformIO firmware. Wi-Fi, host discovery and streaming with simulated sensors, on the Wemos D1 mini (ESP8266), the ESP32-S3 DevKitC and the XIAO ESP32S3.

### Rev F CAD, body half (2026-09-27)
- `hardware/cad/marvin.scad`: body shell (printed upside down, 1.6 mm radome wall, anthracite band by filament change), plinth, sensor sled, TPU neck gasket, grommets and feet, lidar template. Print-ready STLs in `hardware/stl/`.
- The 24 GHz radar now sits **below** the 60 GHz radar (face centres at 16 mm and 42 mm): above it, it would have shadowed the upper part of the 60 GHz beam.
- The head sits on the body through a TPU gasket and four TPU grommets; no screw links them rigidly.
- `hardware/scripts/section_diagram.py` draws the section diagram from the CAD values.
- Rev E (Fanou) sources, STLs and Blender file moved to `hardware/archive/rev-e/`.
- `hardware/blender/marvin.blend`: the body half from the CAD (band painted), the modules, a concept stand-in for the head, and the print plates. Built by `hardware/scripts/build_blend.sh`.
- `hardware/bambu/marvin_A1.3mf`: Bambu Studio project for the A1 + AMS lite (4 plates, colours, per-part settings, band colour change). Built by `hardware/scripts/build_3mf.py` with the Bambu Studio command line.

### Renamed (2026-09-27): SuperLens is now Marvin
- The project and the robot are now called Marvin. "marvin" is also its wake word, a keyword of Google's open Speech Commands dataset.
- Older entries below keep the file names they had at the time (`superlens.scad`, `superlens.blend`).

### Rev F design (2026-09-25): the upright robot
- New shape: a compact upright robot (about 88 × 80 mm, 15 cm tall with the lidar) replaces the lighthouse. Design studies in `docs/concepts/` (terminal, robot v1–v3, sight lines).
- Sensors are tilted inside an upright shell: 60 GHz radar at 20° (aimed at a seated chest, 0.6–1 m), 24 GHz radar at 10°, camera at 20°, screen vertical.
- Head and body joined through a TPU damper so the lidar motor does not disturb the heart-rate radar.
- Smoked acrylic face window; anthracite band hiding both radars, printed as a filament change.
- Grown-up design language: warm grey, anthracite, one orange knob.
- BOM: MR60BHA2 now bought from Seeed Studio; adds smoked acrylic and TPU. Electronics and wiring unchanged.
- Docs, READMEs and presentation page describe rev F. The rev F CAD is not written yet; `hardware/cad/fanou.scad` still holds rev E.

## [rev E] - 2026-09-25 · Fanou

### Changed
- The handheld sensor head becomes **Fanou**, a desk companion shaped like a little lighthouse. Same sensors, same wiring and pin map as rev D.
- New parametric source `hardware/cad/fanou.scad`: rocky island base, bottom plate, striped tower (1.6 mm PETG wall, half a wavelength at 60 GHz), spine carrying every module, gallery cap with railing and lidar plinth.
- The radars now look through the painted wall: the 60 GHz radar behind an arched door, the 24 GHz radar behind the middle red band.
- The screen is Fanou's face, in portrait behind a framed window; the camera looks through a brass porthole above it.
- The speaker moves to the bottom plate under a grille; the WAGOs and the amp are stuck on the back of the spine.
- Power arrives through a USB-C cable with a right-angle plug, entering at the back of the island.
- The lidar is held by 3 thread-forming M2.5 screws (no nuts); the cap by 3 radial M3 screws.
- New Blender file `hardware/blender/fanou.blend` and Cycles renders `docs/images/fanou_*.png`. Presentation page and READMEs rewritten.

### Added
- Character studies in `docs/concepts/` (Fanou the lighthouse, Hulotte the owl, Tito the robot).

### Removed
- `hardware/cad/superlens.scad` and its parts (head, back cover, grip, stand), `superlens.blend` and the rev D renders.

## [rev D] - 2026-09-24

### Added
- Audio: the XIAO Sense's built-in PDM microphone, plus a MAX98357A I2S amp driving a 2030 speaker held in a cradle on the left wall. The side vents act as its grille, with extra holes.
- Presentation page `docs/index.html` (EN/FR) with a live simulation of the back screen.
- Cycles renders `docs/images/hero_front.png` and `hero_back.png`.

### Changed
- The D800 lidar (STL-27L, 921 600 baud) is now the reference; the D500 remains a cheaper option.
- To free the I2S pins, the lidar PWM goes back to GND and the screen backlight to 3V3. There are now four WAGO buses (5 V, GND-A, GND-B, 3V3) and 29 connections.
- The standard XIAO (loose headers) is the default: two header strips to solder.
- README and README.fr open with the project vision.
- Blender file: flat CAD shading, glowing screen, speaker volume.

## [rev C] - 2026-09-24

### Added
- 1.69" ST7789 colour screen (Waveshare, 240×280) in the back cover, held by two clamp brackets pressing its standoffs through foam.
- Blender file `hardware/blender/superlens.blend` (assembly + print layout) and its build script.

### Changed
- Recommended lidar: LDROBOT D500 (STL-19P), a drop-in replacement for the LD19. The D800 (STL-27L) is listed as an option.
- The power bank now stays in your pocket on a 1 m USB-C cable. The strap slots are gone.
- The lidar PWM pin now goes to D9 instead of GND, so the firmware can control the motor speed.
- Pressing columns moved around the screen: MR60 columns lowered, LD2450 columns moved to the board ends.

## [rev B] - 2026-09-24

### Changed
- Solderless build: a pre-soldered XIAO ESP32S3 Sense, Dupont plugs and WAGO 221 lever connectors replace the soldered distribution board.
- The user's power bank now plugs straight into the XIAO's USB-C port, and the 5V pin feeds the sensors.
- M3 screws thread-form into PETG, so heat-set inserts are no longer needed.
- The tripod mount uses a captive 1/4"-20 nut instead of a heat-set insert.

### Added
- Desk stand that holds the grip so the head stays level.
- Print-bed orientations in the CAD source (`PART="print_*"`) and export scripts.

### Removed
- Trigger button, USB-C input breakout, switch cable and bulk capacitor.

## [rev A] - 2026-09-24

### Added
- First enclosure: head, back cover with pressing columns, raked pistol grip, lidar check template.

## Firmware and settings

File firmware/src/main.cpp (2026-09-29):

// Marvin firmware: Wi-Fi link to the host, and the sensors, simulated or real.
//
// Boot -> join Wi-Fi -> broadcast HELLO every 0.5 s -> the host answers HOST_ACK ->
// unicast lidar and radar frames to that host, HELLO every 2 s as a heartbeat.
// No ACK for 6 s: back to broadcasting. The LED blinks fast while searching, slowly once linked.
//
// Sensor source, chosen at build time with MARVIN_SENSORS (see platformio.ini):
//   SIM  (default) simulated lidar, LD2450 and vital signs; HELLO carries the "simulated" flag.
//   REAL (ESP32 only) the lidar on UART0 and the LD2450 on UART1 (sensors_real.h); no VITALS,
//        the MR60BHA2 kit has its own bridge. A LOG with the sensor counters every 5 s.
//
// Optional media on the XIAO ESP32S3 Sense (flags in platformio.ini), announced in HELLO's flags:
//   MARVIN_HAS_AUDIO   speaker and microphone over UDP (audio/audio_app.h): AUDIO_OUT, AUDIO_CTRL
//                      and SOUND in, AUDIO_IN out.
//   MARVIN_HAS_CAMERA  MJPEG over HTTP on port 81 (camera/camera_app.h).
// A LOG with their counters every 10 s while they are in use.
//
// SPDX-License-Identifier: MIT
#include <Arduino.h>

#if defined(ESP8266)
#include <ESP8266WiFi.h>
#else
#include <WiFi.h>
#endif
#include <WiFiUdp.h>

#include "protocol.h"
#include "sensor_framing.h"
#include "sensors_real.h"
#include "sensors_sim.h"
#if defined(MARVIN_HAS_OTA)
#include "ota.h"
#endif
#if defined(MARVIN_HAS_SCREEN)
#include "face/face_app.h"
#endif
#if defined(MARVIN_HAS_AUDIO)
#include "audio/audio_app.h"
#include "audio/audio_packets.h"
#include "audio/earcons.h"
#endif
#if defined(MARVIN_HAS_CAMERA)
#include "camera/camera_app.h"
#endif

#if __has_include("secrets.h")
#include "secrets.h"
#else
#error "Copy include/secrets.example.h to include/secrets.h and put your Wi-Fi in it."
#endif

// ---- Build configuration ----------------------------------------------------------------------

#ifndef MARVIN_BOARD
#define MARVIN_BOARD 0
#endif
#ifndef MARVIN_SIM_LIDAR_MODEL
#define MARVIN_SIM_LIDAR_MODEL 1
#endif
#ifndef MARVIN_LIDAR_MODEL
#define MARVIN_LIDAR_MODEL 1
#endif
#ifndef MARVIN_SERIAL_BAUD
#define MARVIN_SERIAL_BAUD 115200
#endif
#ifndef MARVIN_LED_ACTIVE_LOW
#define MARVIN_LED_ACTIVE_LOW 0
#endif
#ifndef MARVIN_BOOT_SOUND
#define MARVIN_BOOT_SOUND 1                     // with audio: the "hello" earcon on the first link
#endif

// MARVIN_SENSORS=SIM or MARVIN_SENSORS=REAL, turned into a number the preprocessor can compare.
#ifndef MARVIN_SENSORS
#define MARVIN_SENSORS SIM
#endif
#define MARVIN_SENSORS_ID_SIM 1
#define MARVIN_SENSORS_ID_REAL 2
#define MARVIN_PASTE_(a, b) a##b
#define MARVIN_PASTE(a, b) MARVIN_PASTE_(a, b)
#define MARVIN_SENSORS_ID MARVIN_PASTE(MARVIN_SENSORS_ID_, MARVIN_SENSORS)

#if MARVIN_SENSORS_ID == MARVIN_SENSORS_ID_REAL
#define MARVIN_REAL_SENSORS 1
#elif MARVIN_SENSORS_ID == MARVIN_SENSORS_ID_SIM
#define MARVIN_REAL_SENSORS 0
#else
#error "MARVIN_SENSORS must be SIM or REAL"
#endif

#if (defined(MARVIN_HAS_AUDIO) || defined(MARVIN_HAS_CAMERA)) && !defined(CONFIG_IDF_TARGET_ESP32S3)
#error "MARVIN_HAS_AUDIO and MARVIN_HAS_CAMERA are for the XIAO ESP32S3 Sense (pins in docs/wiring.md)."
#endif

#if MARVIN_REAL_SENSORS && !defined(ARDUINO_ARCH_ESP32)
#error "MARVIN_SENSORS=REAL needs an ESP32-S3 (lidar on UART0, LD2450 on UART1). The D1 mini (ESP8266) runs simulated sensors only: build it with MARVIN_SENSORS=SIM."
#endif

namespace {

constexpr int LIDAR_BATCH = 10;                 // LDROBOT packets per datagram
constexpr uint32_t LINK_TIMEOUT_MS = 6000;
constexpr uint32_t LIDAR_FLUSH_MS = 20;         // real sensors: send a partial batch after this
constexpr uint32_t STATS_PERIOD_MS = 5000;      // real sensors: counters LOG period
constexpr uint32_t MEDIA_STATS_PERIOD_MS = 10000;  // audio / camera counters LOG period, when in use
constexpr uint8_t LIDAR_MODEL = MARVIN_REAL_SENSORS ? MARVIN_LIDAR_MODEL : MARVIN_SIM_LIDAR_MODEL;

const char *lidar_name(uint8_t model) { return model == 2 ? "D800" : "D500"; }

// ---- Link: Wi-Fi, HELLO / HOST_ACK, sending ---------------------------------------------------

WiFiUDP udp;
IPAddress host;
bool linked = false;
uint32_t last_ack_ms = 0;
uint32_t seq = 0;
uint8_t mac[6];
uint8_t buf[proto::HEADER_SIZE + 1 + LIDAR_BATCH * sim::LIDAR_PACKET];

uint64_t now_us() {
#if defined(ESP8266)
  return micros64();
#else
  return (uint64_t)esp_timer_get_time();
#endif
}

void led(bool on) {
#ifdef LED_BUILTIN
  digitalWrite(LED_BUILTIN, (on ^ MARVIN_LED_ACTIVE_LOW) ? HIGH : LOW);
#endif
}

// Sends the datagram in `dgram` (header space + payload_len bytes of payload), stamped t_us.
void send_datagram(uint8_t *dgram, proto::Type type, size_t payload_len, uint64_t t_us) {
  proto::header(dgram, type, seq++, t_us);
  IPAddress to = linked ? host : IPAddress(255, 255, 255, 255);
  udp.beginPacket(to, proto::HOST_PORT);
  udp.write(dgram, proto::HEADER_SIZE + payload_len);
  udp.endPacket();
}

// Sends the payload already written in buf, stamped now.
void send(proto::Type type, size_t payload_len) { send_datagram(buf, type, payload_len, now_us()); }

void send_hello() {
  uint8_t flags = MARVIN_REAL_SENSORS ? 0 : proto::FLAG_SIMULATED;
#if defined(MARVIN_HAS_CAMERA)
  if (camera_app::ready()) flags |= proto::FLAG_CAMERA;
#endif
#if defined(MARVIN_HAS_AUDIO)
  if (audio_app::ready()) flags |= proto::FLAG_AUDIO;
#endif
  size_t n = proto::hello(buf + proto::HEADER_SIZE, mac, MARVIN_BOARD, flags, (int8_t)WiFi.RSSI(),
                          millis(), MARVIN_FW_VERSION);
  send(proto::HELLO, n);
}

void send_log(const char *text) {
  size_t n = strlen(text);
  if (n > sizeof(buf) - proto::HEADER_SIZE) n = sizeof(buf) - proto::HEADER_SIZE;
  memcpy(buf + proto::HEADER_SIZE, text, n);
  send(proto::LOG, n);
}

#if MARVIN_REAL_SENSORS
bool ld2450_configured = false;
#endif

void on_host_ack() {
  last_ack_ms = millis();
  if (linked && udp.remoteIP() == host) return;
  host = udp.remoteIP();
  linked = true;
#if defined(MARVIN_HAS_AUDIO) && MARVIN_BOOT_SOUND
  static bool greeted = false;
  if (!greeted) greeted = audio_app::play_sound(audio::SOUND_HELLO);  // first link since boot
#endif
  Serial.printf("linked to host %s\n", host.toString().c_str());
  char msg[96];
#if MARVIN_REAL_SENSORS
  snprintf(msg, sizeof(msg), "firmware %s up, real %s lidar, LD2450 %s", MARVIN_FW_VERSION,
           lidar_name(LIDAR_MODEL), ld2450_configured ? "in multi-target mode" : "did not answer at boot");
#else
  snprintf(msg, sizeof(msg), "firmware %s up, simulated %s lidar", MARVIN_FW_VERSION, lidar_name(LIDAR_MODEL));
#endif
  send_log(msg);
}

// Reads the datagrams from the host.
void poll_host() {
#if defined(MARVIN_HAS_AUDIO)
  static uint8_t in[proto::MAX_HOST_DATAGRAM];  // AUDIO_OUT is the largest host -> robot message
#else
  static uint8_t in[512];
#endif
  while (udp.parsePacket()) {
    int n = udp.read(in, sizeof(in));
    if (n < (int)proto::HEADER_SIZE || !proto::valid(in, n)) continue;
    const bool from_host = linked && udp.remoteIP() == host;
    (void)from_host;  // unused on boards with neither screen nor audio
    switch (in[3]) {
      case proto::HOST_ACK:
        if (n >= (int)proto::HEADER_SIZE + 8) on_host_ack();
        break;
#if defined(MARVIN_HAS_AUDIO)
      case proto::AUDIO_OUT:
      case proto::AUDIO_CTRL:
      case proto::SOUND:
        if (from_host) audio_app::on_message(in[3], in + proto::HEADER_SIZE, n - proto::HEADER_SIZE);
        break;
#endif
      default:
        // other host -> robot messages are dispatched here
        // (type in[3], payload in + proto::HEADER_SIZE, n - proto::HEADER_SIZE bytes, sender udp.remoteIP())
#if defined(MARVIN_HAS_SCREEN)
        if (from_host)
          face_app::on_message(in[3], in + proto::HEADER_SIZE, n - proto::HEADER_SIZE);  // queued, never blocks
#endif
        break;
    }
  }
}

void connect_wifi() {
  WiFi.mode(WIFI_STA);
#if defined(ESP8266)
  WiFi.setSleepMode(WIFI_NONE_SLEEP);           // modem sleep adds latency and drops broadcast replies
#else
  WiFi.setSleep(false);
#endif
  WiFi.begin(WIFI_SSID, WIFI_PASSWORD);
  Serial.printf("joining %s", WIFI_SSID);
  while (WiFi.status() != WL_CONNECTED) {
    led(true); delay(100); led(false); delay(100);
    Serial.print('.');
  }
  Serial.printf("\nIP %s, RSSI %d dBm\n", WiFi.localIP().toString().c_str(), WiFi.RSSI());
}

// Host datagrams, link timeout, HELLO, status LED.
void link_step(uint32_t ms) {
  static uint32_t next_hello = 0;
  poll_host();
  // signed: an ACK read just above is stamped with millis(), which can be later than ms
  if (linked && (int32_t)(ms - last_ack_ms) > (int32_t)LINK_TIMEOUT_MS) {
    linked = false;
    Serial.println("host lost, searching");
  }
  if ((int32_t)(ms - next_hello) >= 0) {
    send_hello();
    next_hello = ms + (linked ? 2000 : 500);
  }
  led(linked ? (ms % 2000) < 100 : (ms % 250) < 125);
}

// ---- Media: audio and camera (XIAO ESP32S3 Sense) ---------------------------------------------

#if defined(MARVIN_HAS_AUDIO) || defined(MARVIN_HAS_CAMERA)

#if defined(MARVIN_HAS_AUDIO)
uint8_t mic_dgram[proto::HEADER_SIZE + audio_packets::AUDIO_IN_HEADER + 2 * proto::AUDIO_IN_SAMPLES];
#endif

// After Wi-Fi is up (the camera server needs the network stack).
void media_begin() {
#if defined(MARVIN_HAS_AUDIO)
  Serial.println(audio_app::begin() ? "audio: speaker on I2S1 (GPIO8/43/3), PDM mic on I2S0 (GPIO42/41)"
                                    : "audio: disabled");
#endif
#if defined(MARVIN_HAS_CAMERA)
  if (camera_app::begin())
    Serial.printf("camera: %s, http://%s:%u/stream\n", camera_app::sensor_name(), WiFi.localIP().toString().c_str(),
                  (unsigned)proto::CAMERA_PORT);
#endif
}

void media_step(uint32_t ms) {
  static uint32_t last_stats = 0;
#if defined(MARVIN_HAS_AUDIO)
  audio_app::set_linked(linked);
  uint64_t t_us;
  while (size_t n = audio_app::next_mic_payload(mic_dgram + proto::HEADER_SIZE, sizeof(mic_dgram) - proto::HEADER_SIZE, &t_us))
    send_datagram(mic_dgram, proto::AUDIO_IN, n, t_us);
#endif
  if (ms - last_stats < MEDIA_STATS_PERIOD_MS) return;
  last_stats = ms;
  char msg[192];
#if defined(MARVIN_HAS_AUDIO)
  if (audio_app::stats_line(msg, sizeof(msg))) {
    Serial.println(msg);
    if (linked) send_log(msg);
  }
#endif
#if defined(MARVIN_HAS_CAMERA)
  if (camera_app::stats_line(msg, sizeof(msg))) {
    Serial.println(msg);
    if (linked) send_log(msg);
  }
#endif
}

#else
void media_begin() {}
void media_step(uint32_t) {}
#endif

// ---- Simulated sensors ------------------------------------------------------------------------

#if !MARVIN_REAL_SENSORS

void sensors_begin() {
  uint32_t t0 = millis();
  sim::begin(MARVIN_SIM_LIDAR_MODEL, [] { yield(); });
  Serial.printf("simulated room ready in %lu ms\n", (unsigned long)(millis() - t0));
}

void sensors_step(uint32_t ms) {
  static uint32_t next_radar = 0, sent_packets = 0, link_start_ms = 0;
  float t = ms / 1000.0f;
  if (!linked) {
    link_start_ms = ms;
    sent_packets = 0;
    return;
  }

  // lidar: keep up with the real packet rate, one datagram per LIDAR_BATCH packets
  uint32_t due = (uint64_t)(ms - link_start_ms) * sim::lidar_points_per_second() / 12000;
  while (due - sent_packets >= LIDAR_BATCH) {
    uint8_t *p = buf + proto::HEADER_SIZE;
    *p++ = MARVIN_SIM_LIDAR_MODEL;
    for (int i = 0; i < LIDAR_BATCH; i++, p += sim::LIDAR_PACKET) sim::lidar_packet(t, p);
    send(proto::LIDAR, 1 + LIDAR_BATCH * sim::LIDAR_PACKET);
    sent_packets += LIDAR_BATCH;
  }

  if ((int32_t)(ms - next_radar) >= 0) {
    sim::ld2450_frame(t, buf + proto::HEADER_SIZE);
    send(proto::LD2450, sim::LD2450_FRAME);
    send(proto::VITALS, sim::vitals(t, buf + proto::HEADER_SIZE));
    next_radar = ms + 100;
  }
}

#endif  // !MARVIN_REAL_SENSORS

// ---- Real sensors (ESP32) ---------------------------------------------------------------------

#if MARVIN_REAL_SENSORS

// Lidar packets are batched in their own datagram buffer, so HELLO and LOG can use buf meanwhile.
uint8_t lidar_dgram[proto::HEADER_SIZE + 1 + LIDAR_BATCH * framing::LIDAR_PACKET];
int lidar_count = 0;
uint64_t lidar_first_us = 0;                    // when the batch's first packet was read
uint32_t lidar_first_ms = 0;
real::Counters last_counters;
uint32_t last_stats_ms = 0;

void flush_lidar() {
  if (lidar_count && linked)
    send_datagram(lidar_dgram, proto::LIDAR, 1 + lidar_count * framing::LIDAR_PACKET, lidar_first_us);
  lidar_count = 0;
}

void on_lidar_packet(const uint8_t *packet) {
  if (!linked) return;
  if (lidar_count == 0) {
    lidar_first_us = now_us();
    lidar_first_ms = millis();
    lidar_dgram[proto::HEADER_SIZE] = LIDAR_MODEL;
  }
  memcpy(lidar_dgram + proto::HEADER_SIZE + 1 + lidar_count * framing::LIDAR_PACKET, packet,
         framing::LIDAR_PACKET);
  if (++lidar_count == LIDAR_BATCH) flush_lidar();
}

void on_ld2450_frame(const uint8_t *frame) {
  if (!linked) return;
  memcpy(buf + proto::HEADER_SIZE, frame, framing::LD2450_FRAME);
  send(proto::LD2450, framing::LD2450_FRAME);
}

// Serial log (always) and LOG to the host (when linked): rates and error counts since the last one.
void report_stats(uint32_t ms) {
  real::Counters c = real::counters(), &p = last_counters;
  float s = (ms - last_stats_ms) / 1000.0f;
  char msg[160];
  snprintf(msg, sizeof(msg),
           "lidar %.0f pkt/s, %lu CRC err, %lu B dropped; LD2450 %.1f frame/s, %lu bad; %lu UART overflows",
           (c.lidar_packets - p.lidar_packets) / s, (unsigned long)(c.lidar_crc_errors - p.lidar_crc_errors),
           (unsigned long)(c.lidar_dropped_bytes - p.lidar_dropped_bytes),
           (c.ld2450_frames - p.ld2450_frames) / s, (unsigned long)(c.ld2450_bad_frames - p.ld2450_bad_frames),
           (unsigned long)(c.uart_overflows - p.uart_overflows));
  Serial.println(msg);
  if (linked) send_log(msg);
  last_counters = c;
  last_stats_ms = ms;
}

void sensors_begin() {
  Serial.printf("lidar %s on UART0 RX GPIO44 at %lu baud\n", lidar_name(LIDAR_MODEL),
                (unsigned long)real::lidar_baud(LIDAR_MODEL));
  ld2450_configured = real::begin(LIDAR_MODEL);
  Serial.printf("LD2450 on UART1 (RX GPIO5, TX GPIO6) at 256000 baud: %s\n",
                ld2450_configured ? "multi-target tracking set" : "no answer, reading its stream anyway");
}

// Called at the end of setup(): forget what piled up in the UARTs while joining Wi-Fi.
void sensors_ready() {
  real::poll(nullptr, nullptr);
  last_counters = real::counters();
  last_stats_ms = millis();
}

void sensors_step(uint32_t ms) {
  real::poll(on_lidar_packet, on_ld2450_frame);
  if (!linked) lidar_count = 0;
  else if (lidar_count && millis() - lidar_first_ms >= LIDAR_FLUSH_MS) flush_lidar();
  if (ms - last_stats_ms >= STATS_PERIOD_MS) report_stats(ms);
}

#endif  // MARVIN_REAL_SENSORS

}  // namespace

// ---- Arduino entry points ---------------------------------------------------------------------

void setup() {
  Serial.begin(MARVIN_SERIAL_BAUD);
  delay(200);
  Serial.printf("\nMarvin firmware %s, board %d, %s sensors\n", MARVIN_FW_VERSION, MARVIN_BOARD,
                MARVIN_REAL_SENSORS ? "real" : "simulated");
#ifdef LED_BUILTIN
  pinMode(LED_BUILTIN, OUTPUT);
#endif
#if defined(MARVIN_HAS_SCREEN)
  // the face runs in its own task from here on, asleep until the host says someone is there
  if (!face_app::begin()) Serial.println("face: screen init failed");
#endif
  sensors_begin();
  connect_wifi();
  WiFi.macAddress(mac);
  udp.begin(proto::DEVICE_PORT);
#if defined(MARVIN_HAS_OTA)
  ota::Callbacks ota_callbacks;
  ota_callbacks.on_start = [] { if (linked) send_log("OTA update started, back after the reboot"); };
  ota::begin(mac, ota_callbacks);
#endif
  media_begin();
#if MARVIN_REAL_SENSORS
  sensors_ready();
#endif
}

void loop() {
#if defined(MARVIN_HAS_OTA)
  ota::handle();                     // an update blocks here until it reboots or fails
#endif
  uint32_t ms = millis();
  link_step(ms);
  media_step(ms);
  sensors_step(ms);
  // Simulated sensors idle for 10 ms while searching for the host; real ones must keep the UARTs drained.
  delay(linked || MARVIN_REAL_SENSORS ? 1 : 10);
}

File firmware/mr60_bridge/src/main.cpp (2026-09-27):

// Marvin MR60BHA2 bridge: firmware for the XIAO ESP32C6 of Seeed's MR60BHA2 kit.
//
// Reads the 60 GHz radar on UART (tiny-frame protocol) and sends its vital signs to the Marvin
// host as VITALS messages, speaking protocol v1 exactly like the robot:
// boot -> join Wi-Fi -> broadcast HELLO every 0.5 s -> the host answers HOST_ACK ->
// unicast VITALS at 10 Hz to that host, HELLO every 2 s as a heartbeat.
// No ACK for 6 s: back to broadcasting.
//
// SPDX-License-Identifier: MIT
#include <Arduino.h>
#include <WiFi.h>
#include <WiFiUdp.h>

#include "mr60.h"
#include "protocol.h"

#if __has_include("secrets.h")
#include "secrets.h"
#else
#error "Copy include/secrets.example.h to include/secrets.h and put your Wi-Fi in it."
#endif

#ifndef MARVIN_BOARD
#define MARVIN_BOARD 4
#endif

namespace {

// Kit wiring (same as Seeed's stock ESPHome configuration).
constexpr int RADAR_RX = 17;          // D7, radar TX -> C6
constexpr int RADAR_TX = 16;          // D6, C6 -> radar RX
constexpr uint32_t RADAR_BAUD = 115200;
constexpr int RGB_PIN = 1;            // D1, one WS2812

constexpr uint32_t LINK_TIMEOUT_MS = 6000;
constexpr uint32_t VITALS_PERIOD_MS = 100;
constexpr uint32_t STATUS_PERIOD_MS = 5000;

HardwareSerial radar(1);
mr60::Parser parser;
mr60::Tracker tracker;

WiFiUDP udp;
IPAddress host;
bool linked = false;
uint32_t last_ack_ms = 0;
uint32_t seq = 0;
uint8_t mac[6];
uint8_t buf[proto::HEADER_SIZE + 128];

uint64_t now_us() { return (uint64_t)esp_timer_get_time(); }

void send(proto::Type type, size_t payload_len) {
  proto::header(buf, type, seq++, now_us());
  IPAddress to = linked ? host : IPAddress(255, 255, 255, 255);
  udp.beginPacket(to, proto::HOST_PORT);
  udp.write(buf, proto::HEADER_SIZE + payload_len);
  udp.endPacket();
}

void send_hello() {
  size_t n = proto::hello(buf + proto::HEADER_SIZE, mac, MARVIN_BOARD, 0, (int8_t)WiFi.RSSI(), millis(),
                          MARVIN_FW_VERSION);
  send(proto::HELLO, n);
}

void send_log(const char *text) {
  size_t n = strlen(text);
  if (n > sizeof(buf) - proto::HEADER_SIZE) n = sizeof(buf) - proto::HEADER_SIZE;
  memcpy(buf + proto::HEADER_SIZE, text, n);
  send(proto::LOG, n);
}

void radar_version(char *out, size_t size) {
  mr60::FirmwareVersion fw;
  if (tracker.firmware(fw))
    snprintf(out, size, "%u.%u.%u (project %u)", fw.major, fw.minor, fw.patch, fw.project);
  else
    snprintf(out, size, "%s", tracker.radar_alive(millis()) ? "not reported" : "silent");
}

void poll_host() {
  uint8_t in[32];
  while (int size = udp.parsePacket()) {
    int n = udp.read(in, sizeof(in));
    if (n >= (int)proto::HEADER_SIZE + 8 && proto::valid(in, n) && in[3] == proto::HOST_ACK) {
      last_ack_ms = millis();
      if (!linked || udp.remoteIP() != host) {
        host = udp.remoteIP();
        linked = true;
        Serial.printf("linked to host %s\n", host.toString().c_str());
        char fw[32], msg[96];
        radar_version(fw, sizeof(fw));
        snprintf(msg, sizeof(msg), "firmware %s up, MR60BHA2 radar %s", MARVIN_FW_VERSION, fw);
        send_log(msg);
      }
    }
    (void)size;
  }
}

void poll_radar() {
  uint32_t ms = millis();
  // bounded, so a babbling UART cannot starve the network side
  for (int budget = 512; budget > 0 && radar.available(); budget--) {
    if (parser.feed((uint8_t)radar.read())) {
      const mr60::Frame &f = parser.frame();
      bool had_fw = tracker.has_firmware();
      tracker.apply(f.type, f.payload, f.len, ms);
      mr60::FirmwareVersion fw;
      if (!had_fw && tracker.firmware(fw))
        Serial.printf("radar firmware %u.%u.%u (project %u)\n", fw.major, fw.minor, fw.patch, fw.project);
    }
  }
}

// Status light, kept dim: searching = blue blink, linked = slow green pulse,
// a person measured = soft red heartbeat at the measured rate.
void update_led(uint32_t ms, const mr60::Vitals &v) {
  static uint8_t last[3] = {255, 255, 255};
  uint8_t c[3] = {0, 0, 0};
  if (!linked) {
    if (ms % 1000 < 80) c[2] = 10;
  } else if (v.valid) {
    uint32_t period = (uint32_t)(60000.0f / (v.heart_rate > 30 ? v.heart_rate : 60));
    uint32_t t = ms % period;
    if (t < 90 || (t >= 180 && t < 250)) c[0] = t < 90 ? 14 : 7;   // lub-dub
  } else {
    float s = 0.5f - 0.5f * cosf(2 * (float)M_PI * (ms % 4000) / 4000.0f);
    c[1] = (uint8_t)(1 + 7 * s);
  }
  if (memcmp(c, last, 3) != 0) {
    rgbLedWrite(RGB_PIN, c[0], c[1], c[2]);   // handles the WS2812's GRB order
    memcpy(last, c, 3);
  }
}

void log_status(uint32_t ms, const mr60::Vitals &v) {
  if (!tracker.radar_alive(ms)) {
    Serial.printf("radar: no data (frames %lu, errors %lu)\n", (unsigned long)parser.frames(),
                  (unsigned long)parser.errors());
    return;
  }
  Serial.printf("radar: %s, breath %.1f/min, heart %.1f/min, distance %u mm%s (frames %lu, errors %lu)\n",
                tracker.present(ms) ? "person" : "nobody", v.breath_rate, v.heart_rate, v.distance_mm,
                v.valid ? ", valid" : "", (unsigned long)parser.frames(), (unsigned long)parser.errors());
}

void connect_wifi() {
  WiFi.mode(WIFI_STA);
  WiFi.setSleep(false);                         // modem sleep adds latency and drops broadcast replies
  WiFi.begin(WIFI_SSID, WIFI_PASSWORD);
  Serial.printf("joining %s", WIFI_SSID);
  while (WiFi.status() != WL_CONNECTED) {
    rgbLedWrite(RGB_PIN, 0, 0, 10); delay(100);
    rgbLedWrite(RGB_PIN, 0, 0, 0); delay(100);
    poll_radar();
    Serial.print('.');
  }
  Serial.printf("\nIP %s, RSSI %d dBm\n", WiFi.localIP().toString().c_str(), WiFi.RSSI());
}

}  // namespace

void setup() {
  Serial.begin(115200);
  delay(200);
  Serial.printf("\nMarvin MR60BHA2 bridge %s, board %d\n", MARVIN_FW_VERSION, MARVIN_BOARD);
  rgbLedWrite(RGB_PIN, 0, 0, 0);
  radar.setRxBufferSize(2048);
  radar.begin(RADAR_BAUD, SERIAL_8N1, RADAR_RX, RADAR_TX);
  Serial.printf("radar on UART1, RX GPIO%d, TX GPIO%d, %lu baud\n", RADAR_RX, RADAR_TX, (unsigned long)RADAR_BAUD);
  connect_wifi();
  WiFi.macAddress(mac);
  udp.begin(proto::DEVICE_PORT);
}

void loop() {
  static uint32_t next_hello = 0, next_vitals = 0, next_status = 0;
  poll_radar();
  poll_host();
  uint32_t ms = millis();
  if (linked && ms - last_ack_ms > LINK_TIMEOUT_MS) {
    linked = false;
    Serial.println("host lost, searching");
  }
  if ((int32_t)(ms - next_hello) >= 0) {
    send_hello();
    next_hello = ms + (linked ? 2000 : 500);
  }
  mr60::Vitals v = tracker.vitals(ms);
  if (linked && (int32_t)(ms - next_vitals) >= 0) {
    uint8_t *p = buf + proto::HEADER_SIZE;
    send(proto::VITALS, mr60::encode_vitals(v, p));
    next_vitals = ms + VITALS_PERIOD_MS;
  }
  if ((int32_t)(ms - next_status) >= 0) {
    log_status(ms, v);
    next_status = ms + STATUS_PERIOD_MS;
  }
  update_led(ms, v);
  delay(2);
}

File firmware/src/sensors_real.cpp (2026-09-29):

// SPDX-License-Identifier: MIT
#include "sensors_real.h"

#if defined(ARDUINO_ARCH_ESP32)

#include <Arduino.h>

#include "sensor_framing.h"

namespace real {
namespace {

#if CONFIG_IDF_TARGET_ESP32
// Classic ESP32 DevKit (not wired or tested yet): UART0 is the USB bridge's, so the lidar reads on UART2.
constexpr int LIDAR_RX = 16;          // GPIO16, UART2 RX
constexpr int LD2450_RX = 26;         // GPIO26, UART1 RX  <- LD2450 TX
constexpr int LD2450_TX = 27;         // GPIO27, UART1 TX  -> LD2450 RX
#else
constexpr int LIDAR_RX = 44;          // XIAO D7, UART0 RX
constexpr int LD2450_RX = 5;          // XIAO D4, UART1 RX  <- LD2450 TX
constexpr int LD2450_TX = 6;          // XIAO D5, UART1 TX  -> LD2450 RX
#endif
constexpr uint32_t LD2450_BAUD = 256000;
constexpr size_t LIDAR_RX_BUFFER = 4096;    // ~44 ms at 921 600 baud
constexpr size_t LD2450_RX_BUFFER = 1024;
constexpr uint32_t ACK_TIMEOUT_MS = 250;
constexpr int INIT_ATTEMPTS = 3;

// With USB CDC on boot, `Serial` is the USB port and UART0 is free for the lidar as Serial0.
// Only its RX pin is used; TX keeps its boot-time pin (GPIO43), which the I2S amplifier takes
// over when audio is initialised.
#if CONFIG_IDF_TARGET_ESP32
HardwareSerial &lidar_uart = Serial2;
#else
HardwareSerial &lidar_uart = Serial0;
#endif
HardwareSerial &radar_uart = Serial1;

framing::LidarFramer lidar;
framing::Ld2450Framer radar;
volatile uint32_t overflows = 0;

void count_overflow(hardwareSerial_error_t err) {
  if (err == UART_BUFFER_FULL_ERROR || err == UART_FIFO_OVF_ERROR) overflows = overflows + 1;
}

// Sends one LD2450 command and waits for its ACK. Target frames arriving meanwhile are skipped.
bool command(const uint8_t *frame, size_t len, uint16_t word, const char *name) {
  radar_uart.write(frame, len);
  radar_uart.flush();
  bool acked = false, ok = false;
  auto on_frame = [&](framing::Ld2450Framer::Kind kind, const uint8_t *f, size_t n) {
    uint16_t cmd, status;
    if (kind == framing::Ld2450Framer::ACK && framing::ld2450_cmd::parse_ack(f, n, &cmd, &status) &&
        cmd == word) {
      acked = true;
      ok = status == 0;
    }
  };
  uint32_t t0 = millis();
  while (!acked && millis() - t0 < ACK_TIMEOUT_MS) {
    uint8_t in[64];
    size_t n = radar_uart.read(in, sizeof(in));
    if (n) radar.feed(in, n, on_frame);
    else delay(1);
  }
  if (!acked) Serial.printf("LD2450: no ACK for %s\n", name);
  else if (!ok) Serial.printf("LD2450: %s refused\n", name);
  return ok;
}

bool configure_ld2450() {
  namespace cmd = framing::ld2450_cmd;
  uint8_t f[cmd::MAX_SIZE];
  for (int attempt = 1; attempt <= INIT_ATTEMPTS; attempt++) {
    bool ok = command(f, cmd::enable_config(f), cmd::ENABLE_CONFIG, "enable configuration");
    ok = ok && command(f, cmd::multi_target(f), cmd::MULTI_TARGET, "multi-target tracking");
    // always leave configuration mode, or the radar stops reporting targets
    bool ended = command(f, cmd::end_config(f), cmd::END_CONFIG, "end configuration");
    if (ok && ended) return true;
    delay(100);
  }
  return false;
}

}  // namespace

uint32_t lidar_baud(uint8_t lidar_model) { return lidar_model == 2 ? 921600 : 230400; }

bool begin(uint8_t lidar_model) {
  lidar_uart.setRxBufferSize(LIDAR_RX_BUFFER);        // must come before begin()
  lidar_uart.begin(lidar_baud(lidar_model), SERIAL_8N1, LIDAR_RX, -1);
  lidar_uart.onReceiveError(count_overflow);
  radar_uart.setRxBufferSize(LD2450_RX_BUFFER);
  radar_uart.begin(LD2450_BAUD, SERIAL_8N1, LD2450_RX, LD2450_TX);
  radar_uart.onReceiveError(count_overflow);
  return configure_ld2450();
}

void poll(FrameFn on_lidar, FrameFn on_ld2450) {
  uint8_t in[256];
  auto lidar_cb = [on_lidar](const uint8_t *p) { if (on_lidar) on_lidar(p); };
  auto radar_cb = [on_ld2450](framing::Ld2450Framer::Kind kind, const uint8_t *f, size_t) {
    if (kind == framing::Ld2450Framer::TARGETS && on_ld2450) on_ld2450(f);
  };
  // Bounded work per call: at most what was already buffered when we started.
  for (size_t left = lidar_uart.available(); left;) {
    size_t n = lidar_uart.read(in, left < sizeof(in) ? left : sizeof(in));
    if (!n) break;
    lidar.feed(in, n, lidar_cb);
    left -= n < left ? n : left;
  }
  for (size_t left = radar_uart.available(); left;) {
    size_t n = radar_uart.read(in, left < sizeof(in) ? left : sizeof(in));
    if (!n) break;
    radar.feed(in, n, radar_cb);
    left -= n < left ? n : left;
  }
}

Counters counters() {
  Counters c;
  c.lidar_packets = lidar.packets();
  c.lidar_crc_errors = lidar.crc_errors();
  c.lidar_dropped_bytes = lidar.dropped_bytes();
  c.ld2450_frames = radar.frames();
  c.ld2450_bad_frames = radar.bad_frames();
  c.ld2450_dropped_bytes = radar.dropped_bytes();
  c.uart_overflows = overflows;
  return c;
}

}  // namespace real

#endif  // ARDUINO_ARCH_ESP32

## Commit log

2026-09-24 Initial commit: SuperLens rev B hardware and documentation
    Handheld multi-sensor head (LD19 lidar, HLK-LD2450 24 GHz radar,
    MR60BHA2 60 GHz radar, XIAO ESP32S3 Sense camera).
    - Parametric OpenSCAD source with print-bed orientations
    - Print-ready STLs (head, back cover, grip, stand, lidar template)
    - Solderless wiring guide, BOM, printing and assembly docs
    - Architecture notes, firmware and host specs
    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
    [0_lidar_template.stl, 1_head.stl, 2_back_cover.stl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]
2026-09-24 Add Blender model of the assembled device and print layout
    - hardware/blender/superlens.blend: assembly (parts + sensor volumes, mm)
    and print-bed layout collections
    - hardware/blender/build_blend.py: regenerates the .blend from the STLs
    - README: how to open it in Blender
    [superlens.blend]
2026-09-24 Rev C: add 1.69" colour screen on the back cover
    - Waveshare 1.69" ST7789 LCD in the back cover, clamped by two
    brackets pressing its standoffs through foam
    - Power bank moves to the pocket (1 m cable), strap slots removed
    - Pressing columns rearranged around the screen
    - Lidar PWM wired to D9; screen on SPI (D8/D10) + D0/D1/D3/D6
    - D500 (STL-19P) becomes the recommended lidar, D800 as option
    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
    [0_lidar_template.stl, 1_head.stl, 2_back_cover.stl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]
2026-09-24 Docs: switch remaining LD19 references to the D500, update power budget
    [superlens.scad]
2026-09-24 Add presentation page and project vision to the README
    - docs/index.html: EN/FR presentation with a live simulation of the
    back screen, sensor spectrum, data flow, build steps and roadmap
    - Cycles hero renders (front and back) replace the old Blender preview
    - README / README.fr open with what the project is trying to do
    - Blender file: flat shading, glowing screen
    [superlens.blend]
2026-09-24 Rev D: microphone and speaker, D800 lidar as reference
    - Built-in PDM mic of the XIAO Sense; MAX98357A I2S amp + 2030 speaker
    in a cradle on the left wall, side vents as grille
    - Pins freed for I2S: lidar PWM back to GND, screen backlight to 3V3;
    four WAGO buses (5V, GND-A, GND-B, 3V3), 29 connections
    - D800 (STL-27L, 921600 baud) is the reference lidar, D500 the option
    - Standard XIAO with two header strips to solder
    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
    [0_lidar_template.stl, 1_head.stl, 2_back_cover.stl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]
2026-09-25 Rev E: Fanou, the desk lighthouse companion
    The handheld sensor head becomes Fanou, a little lighthouse that sees,
    feels, hears and speaks. Same sensors, wiring and pin map as rev D.
    - New parametric CAD (fanou.scad): rocky island, bottom plate, striped
    tower (1.6 mm PETG radome), spine carrying every module, gallery cap
    - Radars behind the painted wall, screen face in a window, porthole camera
    - New Blender file, Cycles renders, concept studies
    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
    [0_lidar_template.stl, 1_base_island.stl, 1_head.stl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]
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2026-09-25 Rev F design: the upright robot, docs updated
    The lighthouse gives way to a compact upright robot. The shell stays
    vertical and the sensors are tilted inside: 60 GHz radar at 20° aimed at
    a seated chest (0.6-1 m), 24 GHz at 10°, camera at 20°, screen vertical.
    TPU neck damper, smoked acrylic face window, anthracite band.
    - README (EN/FR), BOM, printing, assembly, wiring, architecture, firmware
    and host specs, presentation page and changelog describe rev F
    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
2026-09-27 Rename the project from SuperLens to Marvin
    [fanou.scad]
2026-09-27 Rev F CAD, body half: body, plinth, sensor sled, TPU neck
    - hardware/cad/marvin.scad: body shell (upside down, 1.6 mm radome wall,
    band by filament change), plinth, sensor sled, TPU gasket, grommets
    and feet, lidar template; print-ready STLs regenerated
    - 24 GHz radar moved below the 60 GHz radar so it never shadows the
    60 GHz beam (face centres at 16 and 42 mm)
    - section diagram generated from CAD values (section_diagram.py)
    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
    [0_lidar_template.stl, 1_base_island.stl, 1_body.stl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]
2026-09-27 Blender model and Bambu Studio project for rev F
    - hardware/blender/marvin.blend rebuilt for rev F: body half from the CAD
    (band painted), modules, concept head, print plates; build_blend.sh
    - hardware/bambu/marvin_A1.3mf: A1 + AMS lite project, 4 plates, colours,
    per-part settings, band colour change at 14/44 mm; build_3mf.py
    - marvin.scad: module ghosts exported as parts for the Blender model
    - printing docs, README layout and changelog updated
    [marvin.blend, marvin.scad, marvin_A1.3mf]
2026-09-27 Blender: flat shading on CAD parts, print plates hidden in the viewport by default
    [marvin.blend]
2026-09-27 Blender: millimetre clipping range in the viewport (fixes z-fighting stripes)
    [marvin.blend]
2026-09-27 Software prototype: UDP protocol v1, marvin-host package, firmware with simulated sensors
    - docs/protocol.md: HELLO/HOST_ACK discovery, raw lidar and LD2450 frames in a 16-byte envelope
    - host/: parsers, extrinsics, receiver, Rerun viewer, simulated robot, tests
    - firmware/: PlatformIO project for the Wemos D1 mini, ESP32-S3 DevKitC and XIAO ESP32S3
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2026-09-27 Voice: never answer its own voice, lower latency
    - Half duplex by default: the mic is muted while Marvin speaks and for a tail after playback; decisions use the time the audio was recorded, not when it was transcribed (the cause of the self-answering loop)
    - Transcript echo filter in every state; --duplex for headsets and the robot
    - MLX Whisper (large-v3-turbo) on Apple Silicon GPU, faster-whisper elsewhere; shorter end-of-speech silence with speculative transcription
    - Model warm-up and keep_alive, stable system prompt for Ollama's cache, first clause spoken early, pipelined synthesis
    - Per-stage latency log; defaults in ~/.config/marvin/voice.json (talk --save-defaults)
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2026-09-27 Voice: Piper voices download with certifi's CA bundle, fall back to say/espeak if Piper fails, never kill the speaker thread
    python.org builds of Python on macOS have no CA certificates until Install Certificates.command is run, which broke the first voice download.
2026-09-27 Voice: crackle-free playback
    - output stream at the device's native rate with a 120 ms buffer instead of a low-latency 16 kHz stream that underran while the models kept Python busy
    - the audio callback only copies ready samples from a chunk queue (no array concatenation under the lock)
    - anti-imaging filter when upsampling (Piper 22.05 kHz -> 48 kHz); input stream with 100 ms of headroom
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2026-09-28 Talk now: takes what you say, shows the time left, stops when pressed again
    - After Talk now (or "Marvin." alone) the next utterance is the question, even one word: the
    strict follow-up rules (language, single words, thanks) now only apply after an answer
    - The window opens from where the listening is, so it is never already over while Whisper catches up
    - The button turns orange while Marvin listens and stops listening when pressed again; a line under
    the wave shows the time left and waits while you talk
    - Your bubble only appears when Marvin listens to you (or the words start with "Marvin"), after
    300 ms: noises and talk around him no longer flash bubbles in the conversation
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2026-09-28 App: reply inspector, Marvin's eyes in the chat, sounds, now line, saved conversations
    - Reply inspector: what was heard (and the raw transcript), where the time went, the context
    facts and the exact message sent to the model, the model and language
    - Consecutive ignored utterances fold into one expandable line
    - "Simulated sensors" badge; /api/state and the stream carry simulated and vitals_sensor
    - Marvin's eyes, drawn in the browser, replace the orb: sleepy, calm, attentive, thinking, talking
    - Short synthesised sounds (WebAudio), on by default, ui_sounds setting
    - A line above the text box with what Marvin knows right now; tap it for the Robot tab
    - Conversations are saved in the datab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
2026-09-28 Voice: tools the model can call, starting with the weather
    - voice/tools: a Tool definition and a registry that gives Ollama a constant, byte-identical tools
    list (the prompt cache survives), validates arguments, runs each call with a timeout and turns
    errors into results the model can talk about; tools and online tools can be switched off
    - The answer loop handles tool calls (up to 3 rounds), says "Je regarde…" while an online tool
    runs, keeps whole tool exchanges in the append-only history, and never speaks a JSON payload
    - get_weather: Open-Meteo (no key), current conditions, today and tomorrow, cached 10 minutes;
    a home location in the settings for questions that name no place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
2026-09-28 Design: toward microservices
    A modular monolith first, cut along bounded contexts that own their schema and talk through ports
    and events, so a later split is a deployment change: events through a transactional outbox to
    NATS JetStream, gRPC on the answer path, contracts in marvin-contracts, OpenTelemetry from the
    start, and a likely extraction order that keeps the conversation path short.
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2026-09-28 Java host, review fixes: DNS rebinding closed in both hosts, ordered voice turns, history off the frame thread, robot audio behind ports, traces and readiness, launcher robustness
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2026-09-28 Firmware: the monitor no longer holds the ESP32-S3 DevKitC in reset
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2026-09-29 Memory v1, app screens: the Memory screen for real (filters, sources, correct, pin, keep, forget as a second choice, profile versions and restore, days and weeks, the worker, per-source switches, set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
2026-09-29 Memory v1, review fixes: forgetting reaches every future context (summaries blanked, sources withheld, profile history, the voice's history), sensitive lines relabelled and kept from guests, independ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
2026-09-29 Memory v1, final verification: a scripted week end to end (import, facts that change, sources, profile versions, summaries, retrieval shown in the inspector, remember, recall, forget, export, restart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
2026-09-29 Firmware: the link no longer drops right after each HOST_ACK (unsigned elapsed time)
    [main.cpp]
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2026-09-30 Protocol: BUTTON (0x07) and HELLO flags for buttons, a buzzer and a screen of its own, in both hosts and the vectors
2026-09-30 Firmware: the bench board's eyes on an SSD1306 OLED, Talk and Mute buttons, a buzzer and a status LED (esp32dev, esp32s3)
2026-09-30 Host: the Talk button is Talk now and Mute mutes; the voice's moments chime on the bench board's buzzer
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2026-10-01 Voice: the core decides the audio device once and sends every setting (contract version 2): one AudioDevice per route with its echo and level profile, swapped under the running voice when a robot lin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
2026-10-01 Voice: one place decides the earcons and one device plays them (the voice's own, else a bench board's buzzer); the app chimes only when neither does
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2026-10-04 Voice: new ears. Silero VAD v6 and Smart Turn v3.2 decide the end of a question (a 0.2 s silence, then the model; an unfinished turn waits up to 2 s), Parakeet TDT 0.6B v3 is the default speech recog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
2026-10-04 App: Senses, a sixth destination: everything Marvin sees (the lidar with its range and nearest obstacle, the radar, the camera on demand with an opt-in live preview, what it saw last), hears (the lev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
2026-10-05 Firmware: the "looks" bench build (esp32dev_looks, esp32dev_looks_ota): a real LD2450 and no lidar (MARVIN_LIDAR_MODEL=0), the OLED, Talk button and buzzer
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2026-10-05 Bench: the OLED eyes follow the board's own radar while the host sends no FACE_STATE; a soft "bye" chime on the buzzer
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2026-10-14 Launcher: ./marvin report, one paste for a bug report: versions, the host's health, doctor, the setup steps, devices, the robot's self-test lines, the last 20 latency lines with p50/p90 (contract C6)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
2026-10-14 Firmware: the screen's orientation as build flags (MARVIN_TFT_ROTATE_180, _MIRROR_X, _MIRROR_Y, _BGR; face/panel.h), the window offsets following a flip; the robot env spells out the screen and mic v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
2026-10-14 Host: Marvin greets the owner by name when they sit down after an absence (C5): an arrival after 30 minutes away (or the first since the host started) arms it, the next sat_down says "Bonjour Sébasti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
2026-10-14 Presence: posture hysteresis against a real LD2450's jitter (sat_down / stood_up flapped every 2 to 10 s at 0.3 to 0.7 m): a stand-up confirmed for 2 s against a 1.5 s average of the position, no new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
2026-10-14 Host: replay test, sit-down then greeting: the brain with the host's defaults on a jittery seated LD2450 session drives the voice, which greets the owner once, within 5 s of sitting down
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2026-10-14 App: /api/soul (read, the owner's edits, decide on a proposal, revert, reflect now), the weekly reflection's timer on the shared model lane, the week from memory; soul moved from pending in the API s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
2026-10-14 App: the first-run setup, heart and breathing on Home, Senses for the rev F robot, You in Preferences
    - Setup (setup.js, #setup and /setup): a full screen, one step at a time for a beginner, what each step is for,
    what the host found, the fix (a command with Copy, or words), Skip for now, the checks run again every few
    seconds; the owner's name and languages (in the order picked) with the greeting switch, the quiet hours, the
    speaker test and "Did you hear it?", the voice calibration; the end card. It opens by itself until the setup is
    done or put off (Finish later); Home then says what is left; Marvin > Overview and Preferences open it again.
    - Home: "Heart and breathing" (vitals.js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
2026-10-14 Integration: e2e.py's Home layout reset expects the eight modules (vitals from W5, room), the two sensor cards in place whether shown or not
2026-10-14 Hardware: the plinth prints upside down, floor plate on the bed (it no longer starts with a 4.4 mm ledge in the air); same part
2026-10-14 Hardware: the head CAD: shell printed face down with the smoked window behind a 0.8 mm lip, back cap, face frame holding the screen and the XIAO in a 20° pocket (locked by the USB-C plug), orange kno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

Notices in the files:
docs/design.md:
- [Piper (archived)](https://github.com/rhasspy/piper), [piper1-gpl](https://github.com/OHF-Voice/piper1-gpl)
